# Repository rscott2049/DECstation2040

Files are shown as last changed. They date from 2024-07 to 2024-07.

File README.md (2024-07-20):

# DECstation 2040

## 1.0 Introduction

This document outlines the DECstation 2040, a RP2040 based DECstation 3000
emulator that can run DECWindows. A summary of features:

Hardware:

- RP2040, running at 1.8v/300 MHz
- 32 MB of PSRAM
- 8 MB SPI flash
- uSD card socket
- Monochrome VGA at 1024 x 864
- Ethernet RMII PHY support (socket on rev 1.5, integrated in rev 2.1)

Software:

- 4 port PSRAM PIO engine
- PIO driven VGA, with seperate 16x16 cursor plane overlay
- USB HID to DECWindows keyboard and mouse
  
## 1.1 Software 

### PIO:
The PSRAM/HyperRAM PIO engine provides 42/32 MB/s (write/read) of memory
bandwidth. Further, four PIO engines are used to provide four seperate
read/write memory ports. This allows independent memory access for
the emulated CPU, video DMA, and receive/send Ethernet traffic. Note that
all 32 instruction slots are used.

The video PIO engine can support up to a sysclk/2 pixel rate. Thus,
for the 300 MHz sysclk typically used, it is possible to run 1080p60 at
a pixel rate of 148.5 MHz. The default video rate is 1024 x 768 @ 70Hz,
as this matches the screen used for development and the pixel rate
is an integral divisor from sysclk. Only five PIO instruction slots are
used.

### DMA:
To drive the video PIO engine, five DMA channels are used. They are allocated
as follows:

- ctrl_dma_chan - points to DMA channel command packets
- data_dma_chan - executes DMA command packets
- ps_read_chan - points to PSRAM read data buffer
- inc_dma_chan - used to generate loop counter indices
- cur_inc_dma_chan - used as cursor loop counter

This project uses the RP2040 DMA sniffer to dynamically generate PSRAM
addresses, which eliminates the need to have a per-line PSRAM command packet. 
Further, it uses the inc_dma_chan to enable DMA command loops, eliminating
per-line DMA commands needed to send commands to the PIO pixel and PSRAM
PIO engines. This makes the amount of memory needed to drive video
independent of the display format. Currently, 86 DMA command packets are
used vs. approximately 2250 required for 1080p if a per-line DMA structure
was used.

In order to eliminate the latency from when the PSRAM PIO engine FIFO
has read data, and its delivery to SRAM, we use the ps_read_chan. This
channel is chained to after a PSRAM DMA command is executed. Without
this channel, the PSRAM PIO engine FIFO would be not be emptied until
the next DMA command is executed. This impacts the non-video PSRAM
channels, as they must wait unitl the video PSRAM command is complete.

### USB:
The USB HID code supports (at least) two keyboard/mouse combo types:
Rii mini X1 (model: RT-MWK01), purchased at MicroCenter, and Logitech
K830. 

### Emulator:
Dmitry's code at http://dmitry.gr/?r=05.Projects&proj=33.%20LinuxCard was
modified to support the RP2040, as well as adding support for video and USB
mouse/keyboard input. With overclocking and running the assembly language
version of the CPU emulator, Dmitry's Linux image reports a BOGOMIPS rating
of 13.44.

# 2.0) Getting started

## 2.1) Hardware
Build either rev 1.5 or 2.1, using the appropriate emu_brd directory. Please
note that rev 2.1 is still undergoing Ethernet debug, and has exhibited
significant packet drops. I use JLCPCB for board fabrication, and there are 
Digikey BOM spreadsheets in doc/bom. Recommend building two boards: one to
use as a 1.8v CMSIS debugger, and the other as the target. Feel free to only
populate the RP2040 related components on the CMSIS debugger.

The surface mount parts aren't too troublesome - I find the PSRAM BGA to be
much easier to solder than the RP2040 QFN. My technique is to use a hot-air
SMT rework tool. Recommended assembly steps:
1) Solder the voltage regulator, check for 1.8v and 3.3v when done.
2) Solder all of the passives, the RP2040, flash, and the USB connectors
if building rev 2.1. (Note that two bodge wires are needed to connect J5
and J11 D+/D- as my assumption that USB-A could serve as non-host connector
was incorrect).
When done, use blink_bringup (below) to check connections. (Edit blink.c
to enable the pins to check).
3) Solder the HyperRAM chip, run mem_test to check connections.
4) Solder the voltage translator chips, edit blink.c and run to check
connections.
5) Solder the connectors.

For rev 1.5:
Needs modified waveshare LAN8722 board. In addition to the modifications
outlined at: https://github.com/maximeborges/pico-rmii-ethernet, pin 13 of
the 7 x 2 connector (originally NC) is used as VDDIO for the LAN8722 chip.
To make this modification, cut the existing connection between LAN8722 pin
9 to 3.3v, and route pin 9 to pin 13 of the connector. This allows the use
of 1.8v I/O from the DECstation 2040 board. Also needed is a 6 pin header
to VGA connector. See rev 2.1 schematic for VGA pins needed.

## 2.2) Software
Start with:
http://dmitry.gr/?r=05.Projects&proj=33.%20LinuxCard
Download the images, particularly the ultrix.gui image. This should be placed
on a FAT32 for uMIPS. Edit uc_main.c to select which image to run.

Next, go to where this README.md is stored. Then set current directory to sw.
Edit the "source_this" file to reflect the location of the Pico SDK, and source
this file to set the PICO_SDK environment variable for the current session.

A good place to start is with the blink_bringup directory. CD to this,
and do:

`cmake -B build -S .`

Build software via

`./build.sh`

This will generate an .elf file in build/src. Use picotool to load this onto
the target board. After rebooting, should get "hello, world" on USB serial, as
well as on the hardware serial port. A 500 Hz square wave should be present
on GPIO21 (ret_clk). This can be changed via editing the src/blink.c file.
I use this tool incrementally while soldering the board, to verify connectivity.

Next, build the CMSIS debugger. CD to the picoprobe directory and
build with:

`cmake -B build -DCUSTOMPROBE=1
make -C build`

Program with

`sudo picotool load build/customprobe.elf`

Now go to the psram directory and do:

`cmake -B build -S .`

Build software via

`./build.sh`

This will generate most of the available packages. Of interest are:

- mem_test - a simple memory tester
- fb_test - test program for the frame buffer library
- fb_mem_test - memory test with frame buffer enabled
- pico-rv32ima - RISC-V linux emulation
- uMIPS - DECstation emulation
- pico_rmii_ethernet_httpd - test program for RMII. 

There are shell scripts to load the above:

- cl_sram.sh   - sd command line
- eth_sram.sh  - ethernet test
- fb_flash.sh  - framebuffer library test, run from flash
- fb_sram.sh   - framebuffer library test, run from SRAM
- fbm_flash.sh - memory test with framebuffer enabled, run from flash
- fbm_sram.sh  - memory test with framebuffer enabled, run from SRAM
- mt_sram.sh   - memory test, run from SRAM
- mt_flash.sh  - memory test, run from flash
- um_flash.sh - uMIPS emulator, run from flash
- um_sram.sh  - uMIPS emulator, run from SRAM

Running the code:
Connect the debugger board to the SWD port on the target.
Start the CMSIS debugger via sw/start_cmsis.sh.
Execute one of the scripts above. This will load the program into RP2040
SRAM and start it.

If you wish to run from flash, comment out the no_flash line in the source CMakeLists.txt. Note that the uMIPS emulator requires "copy_to_ram" to be enabled
when running from flash.

# 3.0) Commentary

This project has been a voyage of discovery. The first doc/build_log.txt entry
was on 23-mar-2023, but I'd been thinking of building a business card
ever since I'd read Dmitry's LinuxCard web page. I've learned how to
use the RP2040 PIO engines and the DMA subsystem to push pixels. I'm
amazed at how flexible and capable the RP2040 has turned out to be. Hats off
to the RP2040 designers! 

Most enjoyable moments:

- When the PSRAM PIO engine finally ran the memory test overnight.
- When the second solution to the problem of how to get the DMA subsytem
to do a counted loop actually worked without killing SD card access.
- When the DMA cursor read data during blanking worked, giving smooth
cursor movement.

Less than enjoyable moments:

- Realizing the "optimization" of reordering data on the PSRAM to improve
layout was wrong, after submitting the design to JLCPCB.
-  Realizing that the first flash part chosen didn't support "Continuous Read
Mode". On the other hand, this did force me to learn how to do SRAM builds,
speeding up development.
- Having the wrong footprint for the level translator on rev 1.3.
- Finding out that Digikey no longer stocked the Ethernet connector on
rev 2.0, after submitting PCB. Related - the PSRAM was out of stock, so
clicked on the recommended alternative. Was disappointed when the box
showed up, and it was the waferscale part. Tiny, but unsolderable.

# 4.0) Next steps
- Use the ps_get_buf DMA subroutine to setup the cursor PSRAM command. This
will reduce the memory footprint.
- Write the lance Ethernet emulation code for uMIPS.
- Port MicroMac https://axio.ms/projects/2024/06/16/MicroMac.html

# 5.0) Acknowledgements

This project would not exist without Dmitry's excellent LinuxCard project,
at: http://dmitry.gr/?r=05.Projects&proj=33.%20LinuxCard

Inspiration and software framework:
https://github.com/Wren6991/PicoDVI.git

DEC mouse and keyboard support used code from:
https://hackaday.io/project/19576-dec-mouse-adapter and 
https://github.com/pkoning2/lk201emu.git

Ethernet:
https://github.com/maximeborges/pico-rmii-ethernet

Also, Hackaday.com for articles on SMT soldering, USB-C, etc., giving me
confidence that I could actually do this project!

## Pictures/video
A selection of pictures from doc/photos follows. See doc/photos for pictures
of previous versions and how the emulated video output progressed from first
pixel to current.
### Video showing [Xmaze/worms](https://youtu.be/O6Lyjsey6ek) running
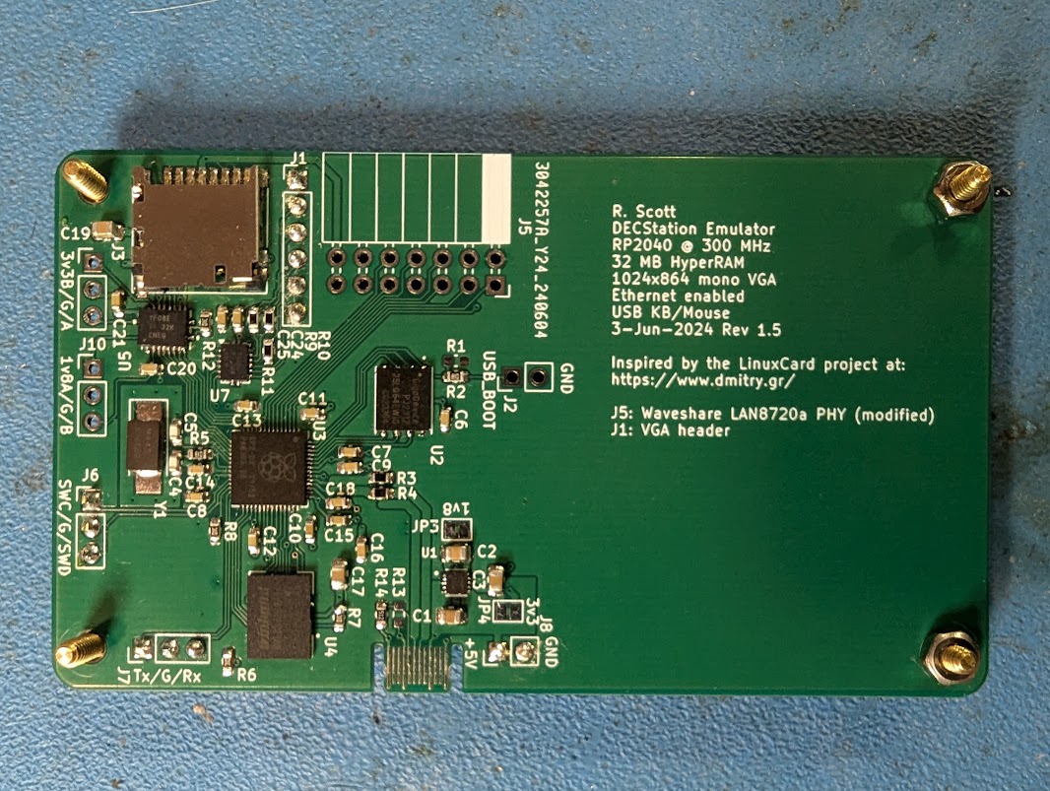
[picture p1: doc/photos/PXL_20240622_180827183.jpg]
### 
Rev 1.5
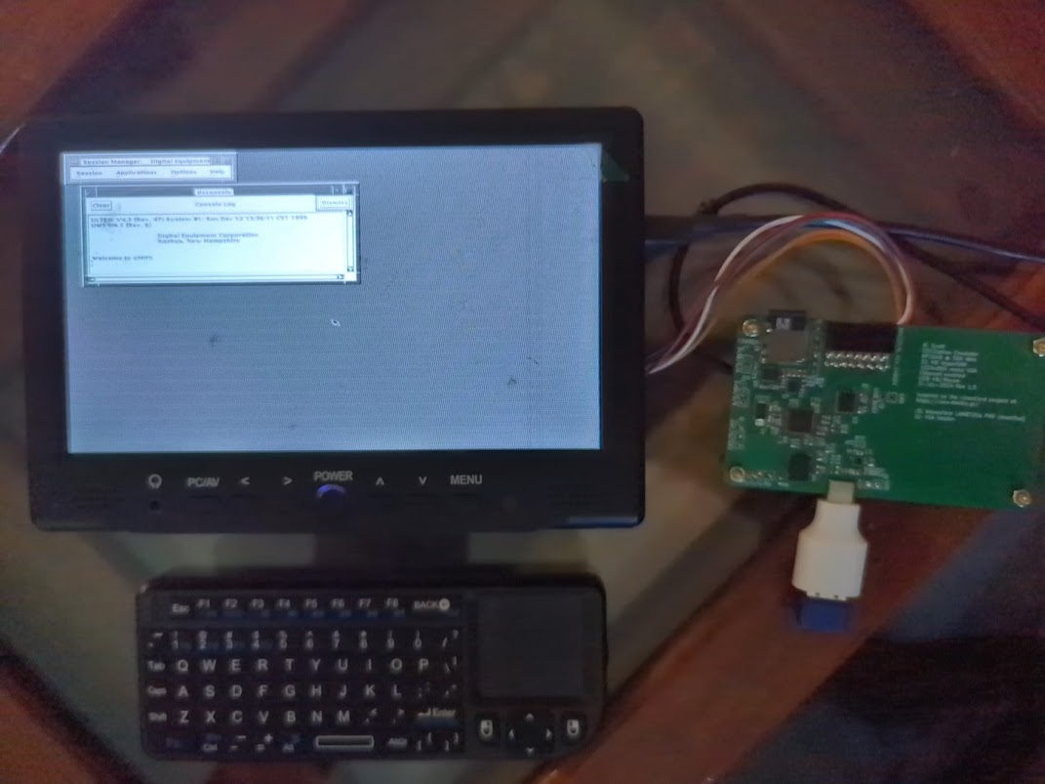
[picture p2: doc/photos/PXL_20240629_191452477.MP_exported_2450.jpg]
### 
Rev 1.5 running
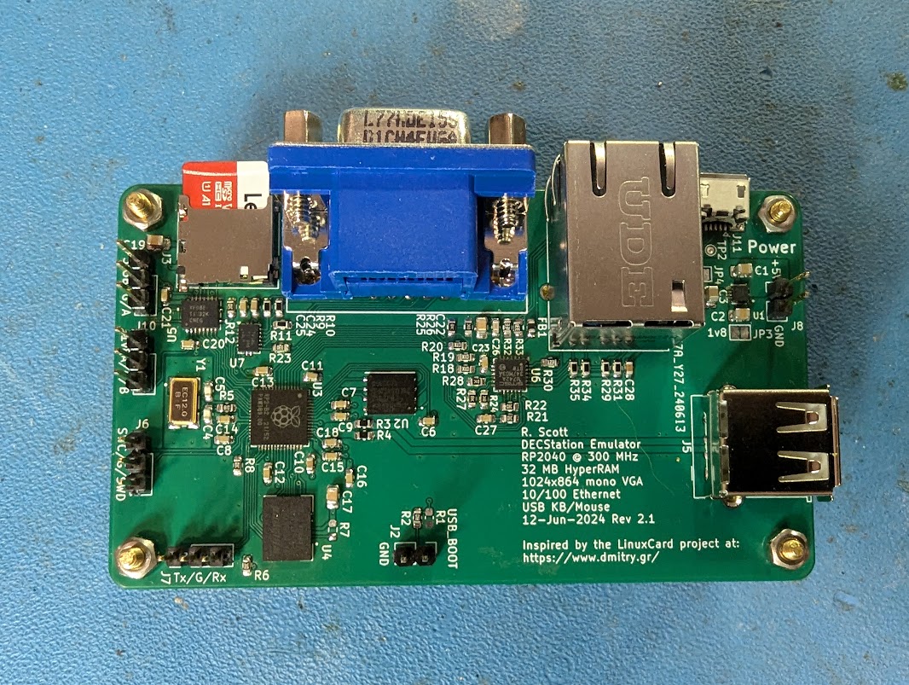
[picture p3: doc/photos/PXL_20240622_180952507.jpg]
### 
Rev 2.1
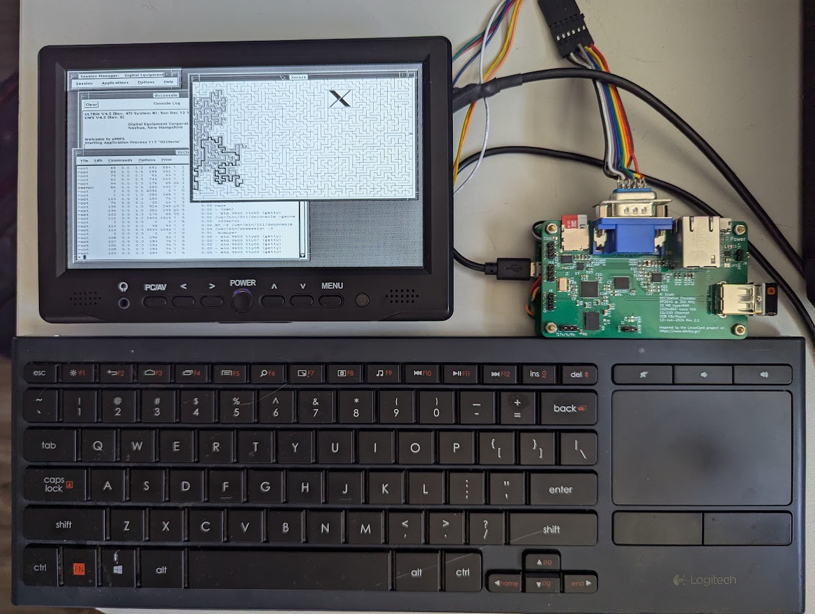
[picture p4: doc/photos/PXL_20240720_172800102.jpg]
### 
Rev 2.1 running with Logitech keyboard
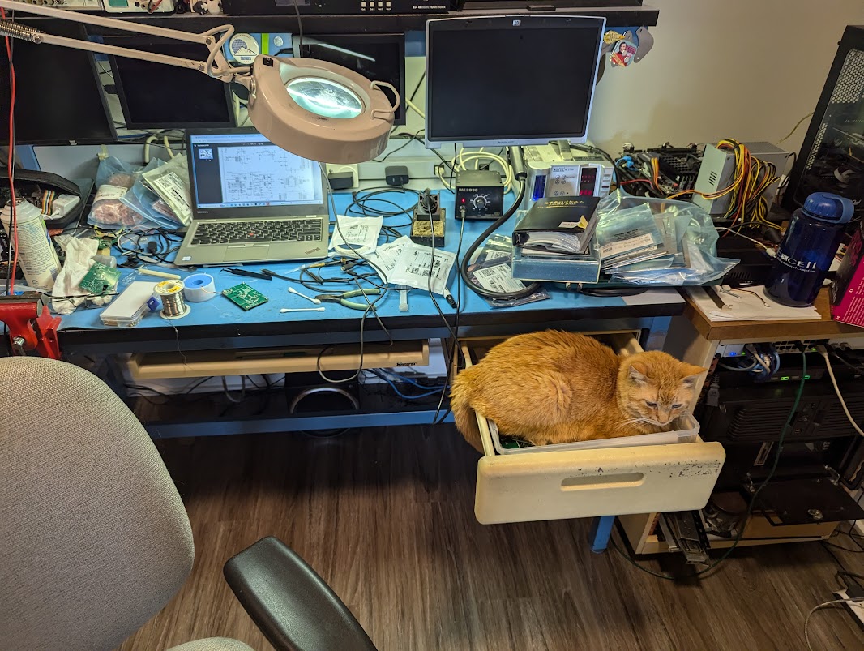
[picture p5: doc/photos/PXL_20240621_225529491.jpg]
Helper cat in the parts box
### 
Helper cat in the parts box

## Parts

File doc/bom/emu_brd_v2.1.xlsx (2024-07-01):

Index | Manufacturer Part Number | Manufacturer Name | Assemblies | Attrition % | Requested Quantity 1 | Pack Quantity 1 | Pack Type 1 | Digi-Key Part Number 1 | Unit Price 1 | Extended Price 1 | Minimum Order Quantity 1 | Product Notes
1 | SC0914(13) | Raspberry Pi | 480 |  | 1 | 480 | Cut Tape (CT) | 2648-SC0914(13)CT-ND | 0.70000 | $336.00 | 1
2 | W958D8NBYA4I | Winbond Electronics | 480 |  | 1 | 480 | Tray | 256-W958D8NBYA4I-ND | 2.99527 | $1,437.73 | 480
3 | GD25LQ64EWIGR | GigaDevice Semiconductor (HK) Limited | 480 |  | 1 | 480 | Cut Tape (CT) | 1970-GD25LQ64EWIGRCT-ND | 1.14648 | $550.31 | 1
4 | TXV0106BQBR | Texas Instruments | 480 |  | 1 | 480 | Cut Tape (CT) | 296-TXV0106BQBRCT-ND | 0.76004 | $364.82 | 1
5 | TXS0108ERGYR | Texas Instruments | 480 |  | 1 | 480 | Cut Tape (CT) | 296-24806-1-ND | 0.86860 | $416.93 | 1
6 | LAN8742A-CZ-TR | Microchip Technology | 480 |  | 1 | 480 | Cut Tape (CT) | LAN8742A-CZ-CT-ND | 1.17000 | $561.60 | 1
7 | TLV751180330PDSQR | Texas Instruments | 480 |  | 1 | 480 | Cut Tape (CT) | 296-TLV751180330PDSQRCT-ND | 0.35976 | $172.68 | 1
8 | L77HDE15SD1CH4FVGA | Amphenol ICC (Commercial Products) | 480 |  | 1 | 480 | Tray | L77HDE15SD1CH4FVGA-ND | 1.22643 | $588.69 | 1
9 | USB-A1HSW6 | On Shore Technology Inc. | 480 |  | 1 | 480 | Tray | ED2989-ND | 0.35552 | $170.65 | 1
10 | RB1-125BAG1A | WIZnet | 480 |  | 1 | 480 | Tray | 1278-1011-ND | 2.39295 | $1,148.62 | 1
11 | DM3D-SF | Hirose Electric Co Ltd | 480 |  | 1 | 480 | Cut Tape (CT) | HR1941CT-ND | 1.28572 | $617.15 | 1
12 | BLM18PG121SN1D | Murata Electronics | 480 |  | 1 | 480 | Cut Tape (CT) | 490-1037-1-ND | 0.03412 | $16.38 | 1
13 | C0603C270J5GAC7411 | KEMET | 480 |  | 2 | 960 | Cut Tape (CT) | 399-C0603C270J5GAC7411CT-ND | 0.01238 | $11.88 | 1
14 | GRM033R61H471KA12D | Murata Electronics | 480 |  | 1 | 480 | Cut Tape (CT) | 490-GRM033R61H471KA12DCT-ND | 0.00430 | $2.06 | 1
15 | CGA3E2X7R1H223K080AA | TDK Corporation | 480 |  | 2 | 960 | Cut Tape (CT) | 445-5663-1-ND | 0.01802 | $17.30 | 1
16 | CL10B104KO8NNNC | Samsung Electro-Mechanics | 480 |  | 16 | 4000 | Tape & Reel (TR) | 1276-1005-2-ND | 0.00574 | $22.96 | 4000
16 | CL10B104KO8NNNC | Samsung Electro-Mechanics | 480 |  |  | 3680 | Cut Tape (CT) | 1276-1005-1-ND | 0.00686 | $25.24 | 1
17 | CL10A105KO8NNNC | Samsung Electro-Mechanics | 480 |  | 2 | 960 | Cut Tape (CT) | 1276-1034-1-ND | 0.01050 | $10.08 | 1
18 | CL21A106KOQNNNG | Samsung Electro-Mechanics | 480 |  | 6 | 2880 | Cut Tape (CT) | 1276-6455-1-ND | 0.01847 | $53.19 | 1
19 | CRCW060327R0JNEA | Vishay Dale | 480 |  | 2 | 960 | Cut Tape (CT) | 541-27GCT-ND | 0.00866 | $8.31 | 1
20 | RC0603JR-0733RL | YAGEO | 480 |  | 1 | 480 | Cut Tape (CT) | 311-33GRCT-ND | 0.00760 | $3.65 | 1
21 | ERJ-3EKF49R9V | Panasonic Electronic Components | 480 |  | 4 | 1920 | Cut Tape (CT) | P49.9HCT-ND | 0.00980 | $18.82 | 1
22 | ERJ-3EKF2800V | Panasonic Electronic Components | 480 |  | 3 | 1440 | Cut Tape (CT) | P280HCT-ND | 0.00980 | $14.11 | 1
23 | RC0603JR-07330RL | YAGEO | 480 |  | 2 | 960 | Cut Tape (CT) | 311-330GRCT-ND | 0.00364 | $3.49 | 1
24 | CRGCQ0603F1K0 | TE Connectivity Passive Product | 480 |  | 2 | 960 | Cut Tape (CT) | A129688CT-ND | 0.00840 | $8.06 | 1
25 | CRG0603F10K | TE Connectivity Passive Product | 480 |  | 3 | 1440 | Cut Tape (CT) | A106048CT-ND | 0.00709 | $10.21 | 1
26 | RC0603FR-0712K1L | YAGEO | 480 |  | 1 | 480 | Cut Tape (CT) | 311-12.1KHRCT-ND | 0.00930 | $4.46 | 1
27 | ECS-120-20-23B-TR | ECS Inc. | 480 |  | 1 | 480 | Cut Tape (CT) | XC1013CT-ND | 0.52610 | $252.53 | 1

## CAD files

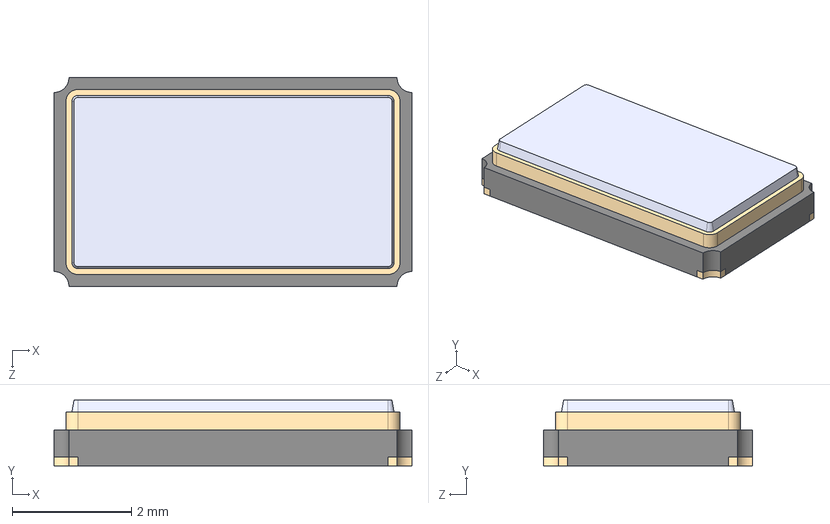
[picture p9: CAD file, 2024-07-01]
emu_brd_rev_2.1/emu_brd.step/ECS-120-20-23B-TR.step
6.00 x 1.10 x 3.50 mm

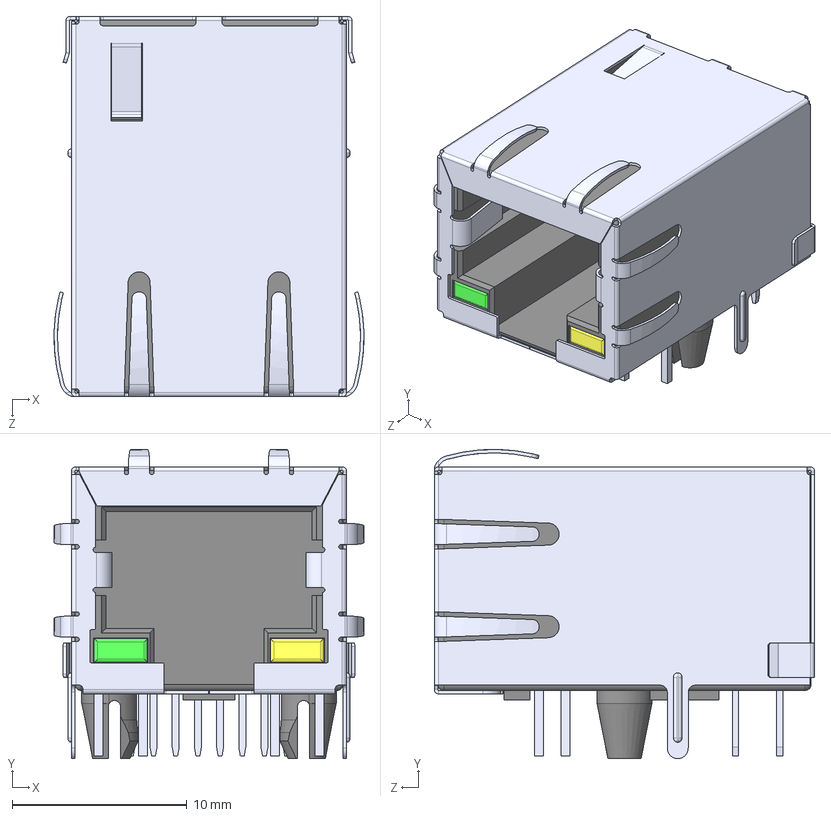
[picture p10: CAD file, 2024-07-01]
emu_brd_rev_2.1/emu_brd.step/RB1-125BAG1A.step
17.7 x 17.7 x 21.8 mm

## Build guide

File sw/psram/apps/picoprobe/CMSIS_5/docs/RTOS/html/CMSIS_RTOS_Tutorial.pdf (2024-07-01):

CMSIS-RTOS Tutorial

# Introduction

This tutorial is an excerpt from “The Designers Guide to the Cortex-M Processor Family” by Trevor Martin and is reproduced with permission of Elsevier. For more details please see the Further Reading section at the end of this tutorial.

In this tutorial we are going to look at using a small footprint RTOS running on a Cortex-M based microcontroller. Specifically we are going to use an RTOS that meets the ‘Cortex Microcontroller Interface Standard’ (CMSIS) RTOS Specification. This specification defines a standard RTOS API for use with Cortex-M based microcontrollers. The CMSIS-RTOS API provides us with all the features we will need to develop with an RTOS, we only need to learn it once and then can use it across a very wide range of devices. CMSIS-RTOS also provides a standard interface for more complex frameworks (Java Virtual Machine, UML). It is also a standard interface for anyone wanting to develop reusable software components. If you are new to using an RTOS it takes a bit of practice to get used to working with an RTOS but once you have made the leap the advantages are such that you will not want to return to writing bare metal code.

# Getting Started- Installing the tools

To run the examples in this tutorial, it is first necessary to install the MDK-ARM toolchain. First download the MDK-Core Version 5 using the embedded URL below and run the installation file.

http://www.keil.com/mdk5/install

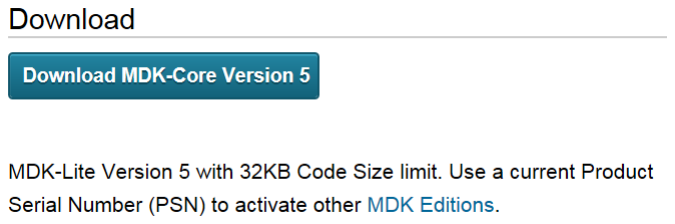
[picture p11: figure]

This installs the core toolchain which includes the IDE, compiler/linker and the basic debugger. It does not include support for specific Cortex-M based microcontrollers. To support a given microcontroller family we need to install a ‘Device Family Pack’. This is a collection of support files such as startup code, flash programming algorithms and debugger support that allow you to develop with a specific microcontroller family.

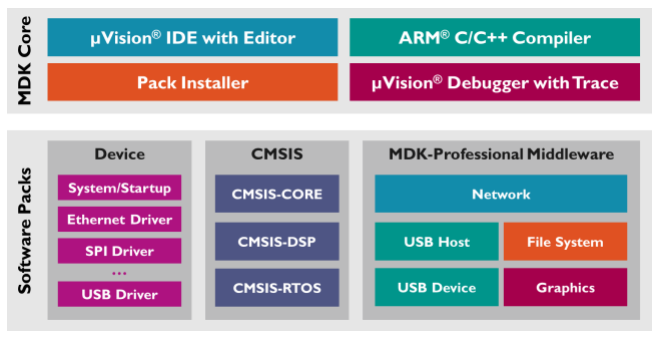
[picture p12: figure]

The | MDK-ARM | toolchain
consists of a Core Installation (IDE, Compiler and Debugger) plus additional software packs added through a pack installer

### 2 CMSIS-RTOS Tutorial

In the exercises we are going to use an STM32F103RB so we need to install support for this device using the ‘Pack Installer’ within the µVision IDE. When the MDK-Core finishes installing the pack installer will start automatically, alternatively you can start the µVision IDE and access Pack Installer from the toolbar by pressing the icon shown below

Once the pack installer is open it will connect to cloud based pack database and display the available device packs.

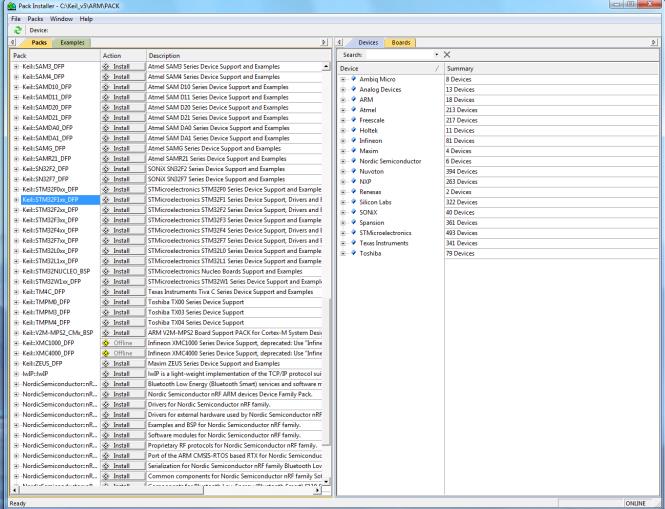
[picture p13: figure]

Select the Keil::STM32F1xx_DFP and press the install button. This will take a few minutes to download and install the STM32F1xx support files.

If the pack installer has any problems accessing the remote pack you can download it manually using the URL below

http://www.keil.com/dd2/Pack/

Pack Installer Icon

The Pack Installer.
Use this utility to
install device support
and | third | party
software components

Install support for the
STM32F1xx Family

CMSIS-RTOS Tutorial

Again select the STM32F1xx pack and save it to your hard disk. The file may be saved as a .zip file depending on the browser you are using. If it is saved as a .zip change the .zip extension to .pack, you can then install it locally by double clicking on the STM32F1xx.pack file.

# Installing the examples

The examples for this tutorial are provided as a CMSIS pack. You can install the pack into the MDK-ARM by simply double clicking on the Hitex.CMSIS_RTOS_Tutorial.1.0.3. pack file.

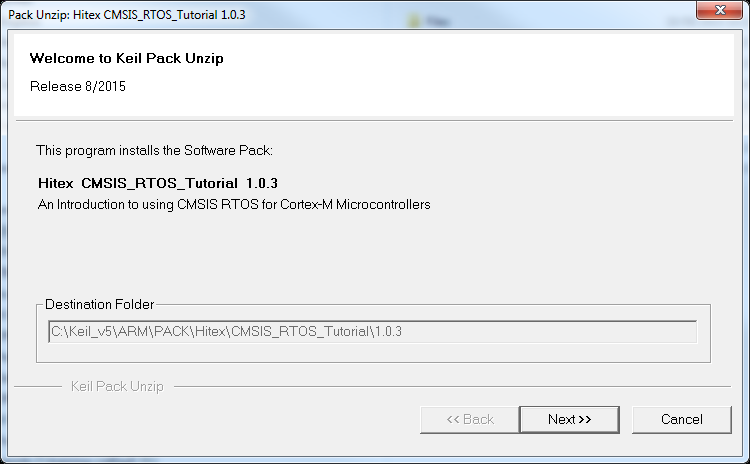
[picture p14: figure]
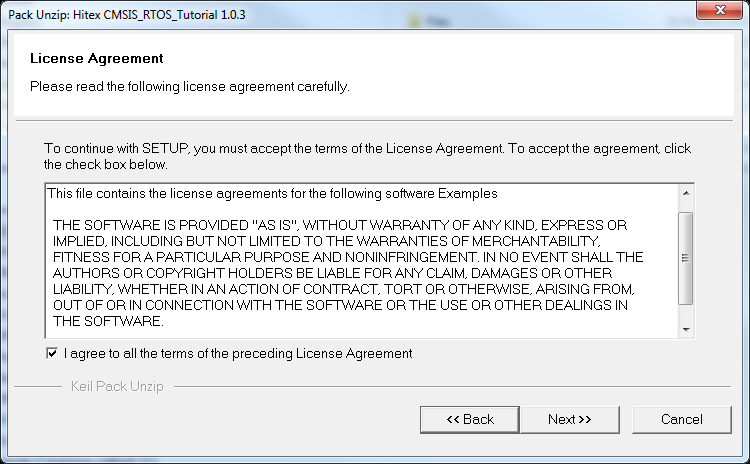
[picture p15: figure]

Once the examples have been installed into MDK-ARM they are part of the toolchain and can be accessed through the pack installer. The tutorial examples can be found in the boards section under ‘CMSIS_RTOS_Tutorial’.

Once | the | pack | has | started
installing click next

Here you must accept the license and again click next to continue the installation

### 4 CMSIS-RTOS Tutorial

# What Hardware do I need?

Simple answer: none! The Keil toolchain contains simulators for each of the Cortex-M processors. It also contains full simulation models (CPU + Peripherals) for some of the earlier Cortex-M microcontrollers. This means we can run the examples in the debugger using the simulation models and explore every aspect of using the RTOS. In fact this method of working is a better way of learning how to use the RTOS than going straight to a real microcontroller.

# Overview

In this tutorial we will first look at setting up an introductory RTOS project for a Cortex-M based microcontroller. Next, we will go through each of the RTOS primitives and how they influence the design of our application code. Finally, when we have a clear understanding of the RTOS features, we will take a closer look at the RTOS configuration options. If you are used to programming a microcontroller without using an RTOS i.e. bare metal, there are two key things to understand as you work through this tutorial. In the first section we will focus on creating and managing Threads. The key concept here is to consider them running as parallel concurrent objects. In the second section we will look at how to communicate between threads. In this section the key concept is synchronization of the concurrent threads.

CMSIS-RTOS Tutorial

## First steps with CMSIS-RTOS

The RTOS itself consists of a scheduler which supports round-robin, pre-emptive and co-operative multitasking of program threads, as well as time and memory management services. Inter-thread communication is supported by additional RTOS objects, including signal triggering, semaphores, mutex and a mailbox system. As we will see, interrupt handling can also be accomplished by prioritized threads which are scheduled by the RTOS kernel.

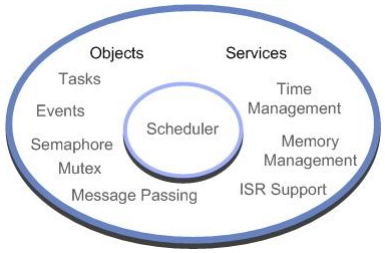
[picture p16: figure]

# Accessing the CMSIS-RTOS API

To access any of the CMSIS-RTOS features in our application code it is necessary to include the following header file

#include <cmsis_os.h>

This header file is maintained by ARM as part of the CMSIS-RTOS standard. For the CMSIS-RTOS Keil RTX this is the default API. Other RTOS will have their own proprietary API but may provide a wrapper layer to implement the CMSIS-RTOS API so they can be used where compatibility with the CMSIS standard is required.

# Threads

The building blocks of a typical ‘C’ program are functions which we call to perform a specific procedure and which then return to the calling function. In CMSIS-RTOS the basic unit of execution is a “Thread”. A Thread is very similar to a ‘C’ procedure but has some very fundamental differences.

The RTOS kernel contains a scheduler that runs program code as tasks. Communication between tasks is accomplished by RTOS objects such as events,
semaphores, | mutexes | and
mailboxes. | Additional | RTOS
services | include | time | and
memory | management | and
interrupt support.

### 6 CMSIS-RTOS Tutorial

unsigned int procedure (void) | void thread (void)
{ | {
| while(1)
…… | {
| ……
return(ch); | }
} | }

While we always return from our ‘C’ function, once started an RTOS thread must contain a loop so that it never terminates and thus runs forever. You can think of a thread as a mini self-contained program that runs within the RTOS.

An RTOS program is made up of a number of threads, which are controlled by the RTOS scheduler. This scheduler uses the SysTick timer to generate a periodic interrupt as a time base. The scheduler will allot a certain amount of execution time to each thread. So thread1 will run for 5ms then be de-scheduled to allow thread2 to run for a similar period; thread 2 will give way to thread3 and finally control passes back to thread1. By allocating these slices of runtime to each thread in a round-robin fashion, we get the appearance of all three threads running in parallel to each other.

Conceptually we can think of each thread as performing a specific functional unit of our program with all threads running simultaneously. This leads us to a more object-orientated design, where each functional block can be coded and tested in isolation and then integrated into a fully running program. This not only imposes a structure on the design of our final application but also aids debugging, as a particular bug can be easily isolated to a specific thread. It also aids code reuse in later projects. When a thread is created, it is also allocated its own thread ID. This is a variable which acts as a handle for each thread and is used when we want to manage the activity of the thread.

osThreadId id1,id2,id3;

In order to make the thread-switching process happen, we have the code overhead of the RTOS and we have to dedicate a CPU hardware timer to provide the RTOS time reference. In addition, each time we switch running threads, we have to save the state of all the thread variables to a thread stack. Also, all the runtime information about a thread is stored in a thread control block, which is managed by the RTOS kernel. Thus the “context switch time”, that is, the time to save the current thread state and load up and start the next thread, is a crucial figure and will depend on both the RTOS kernel and the design of the underlying hardware.

Each thread has its own stack for saving its data during a context switch. The thread control block is used by the kernel to manage the active thread.

Thread

Thread Control
Block

Thread
Stack
Priority & State | Context

CMSIS-RTOS Tutorial

The Thread Control Block contains information about the status of a thread. Part of this information is its run state. In a given system only one thread can be running and all the others will be suspended but ready to run. The RTOS has various methods of inter-thread communication (signals, semaphores, messages). Here, a thread may be suspended to wait to be signaled by another thread or interrupt before it resumes its ready state, whereupon it can be placed into running state by the RTOS scheduler.

Running | The Currently Running Thread
Ready | Threads ready to Run
Wait | Blocked Threads waiting for an OS Event

# Starting the RTOS

To build a simple RTOS program we declare each thread as a standard ‘C’ function and also declare a thread ID variable for each function.

void thread1 (void);
void thread2 (void);

osThreadId thrdID1, thrdID2;

By default the CMSIS-RTOS scheduler will be running when main() is entered and the main() function becomes the first active thread. Once in main(), we can stop the scheduler task switching by calling osKernelInitialize (). While the RTOS is halted we can create further threads and other RTOS objects. Once the system is in a defined state we can restart the RTOS scheduler with osKernelStart().

You can run any initializing code you want before starting the RTOS.

void main (void)
{
osKernelInitialize ();
IODIR1 = 0x00FF0000; | // Do any C code you want
Init_Thread(); | //Create a Thread
osKernelStart(); | //Start the RTOS
}

At any given moment a
single thread may be
running. The remaining
threads will be ready to
run | and | will | be
scheduled | by | the
kernel. Threads may
also | be | waiting
pending an OS event.
When this occurs they
will return to the ready
state and be scheduled
by the kernel.

### 8 CMSIS-RTOS Tutorial

When threads are created they are also assigned a priority. If there are a number
of threads ready to run and they all have the same priority, they will be allotted run time in a round-robin fashion. However, if a thread with a higher priority becomes ready to run, the RTOS scheduler will de-schedule the currently running thread and start the high priority thread running. This is called pre-emptive priority-based scheduling. When assigning priorities you have to be careful because the high priority thread will continue to run until it enters a waiting state or until a thread of equal or higher priority is ready to run.

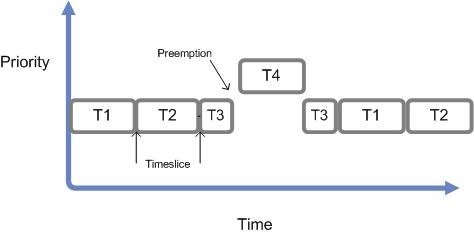
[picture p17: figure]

## Exercise a first CMSIS-RTOS project

This project will take you through the steps necessary to create and debug a CMSIS-RTOS based project.

Start µVision and select Project → New µVision Project

In the new project dialog enter a suitable project name and directory and click Save

Next the device database will open. Navigate through to the

STMicroelectronics::STM32F103:STM32F103RB

Threads of equal priority will be scheduled in a round-robin fashion. High priority tasks will pre-empt low priority tasks and enter the running state ‘on demand’.

CMSIS-RTOS Tutorial

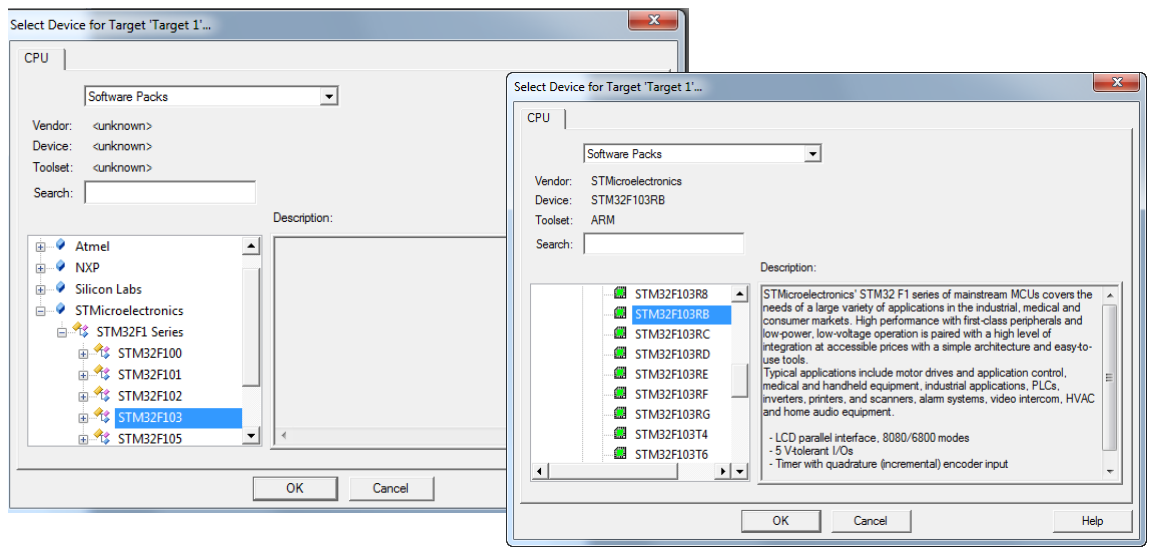
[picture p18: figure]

Once you have selected this device click ok.

Once the microcontroller variant has been selected the Run Time Environment Manager will open.

This allows you to configure the platform of software components you are going to use in a given project. As well as displaying the available components the RTE understands their dependencies on other components.

To configure the project for use with the CMSIS-RTOS Keil RTX, simply tick the CMSIS::RTOS (API):Keil RTX box.

### 10 CMSIS-RTOS Tutorial

This will cause the selection box to turn orange meaning that additional components are required. The required component will be displayed in the Validation Output window.

To add the missing components you can press the Resolve button in the bottom left hand corner of the RTE. This will add the device startup code and the CMSIS Core support. When all the necessary components are present the selection column will turn green.

It is also possible to access a components help files by clicking on the blue hyperlink in the Description column.

Now press the OK button and all the selected components will be added to the new project

CMSIS-RTOS Tutorial

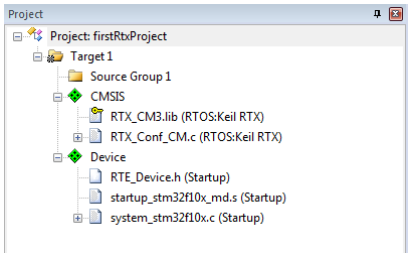
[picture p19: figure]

The CMSIS components are added to folders displayed as a green diamond. There are two types of file here. The first type is a library file which is held within the toolchain and is not editable. This file is shown with a yellow key to show that it is ‘locked’ (read-only). The second type of file is a configuration file. These files are copied to your project directory and can be edited as necessary. Each of these files can be displayed as a text files but it is also possible to view the configuration options as a set of pick lists and drop down menus.

To see this open the RTX_Conf_CM.c file and at the bottom of the editor window select the ‘Configuration Wizard’ tab.

### 12 CMSIS-RTOS Tutorial

Click on Expand All to see all of the configuration options as a graphical pick list:

For now it is not necessary to make any changes here and these options will be examined towards the end of this tutorial.

Our project contains four configuration files three of which are standard CMSIS files

Startup_STM32F10x_md.s | Assembler vector table
System_STM32F10x.c | C code to initialize key system peripherals, such as clock tree, PLL external memory interface.
RTE_Device.h | Configures the pin multiplex
RTX_Conf_CM.c | Configures Keil RTX

Now that we have the basic platform for our project in place we can add some user source code which will start the RTOS and create a running thread.

To do this right-click the ‘Source Group 1’ folder and select ‘Add new item to Source Group 1’

CMSIS-RTOS Tutorial

In the Add new Item dialog select the ’User code template’ Icon and in the CMSIS section select the ‘CMSIS-RTOS ‘main’ function’ and click Add

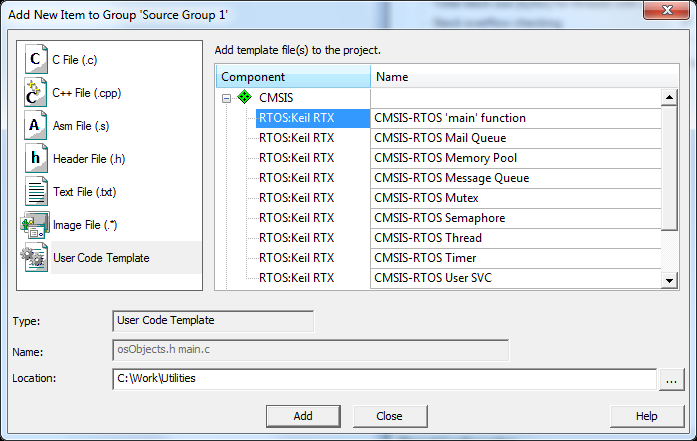
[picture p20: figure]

Repeat this but this time select ‘CMSIS-RTOS Thread’.

This will now add two source files to our project main.c and thread.c

Open thread.c in the editor

We will look at the RTOS definitions in this project in the next section. For now this file contains two functions Init_Thread() which is used to start the thread running and the actual thread function.

### 14 CMSIS-RTOS Tutorial

Copy the Init_Thread function prototype and then open main.c

Main contains the functions to initialize and start the RTOS kernel. Then unlike a bare metal project main is allowed to terminate rather than enter an endless loop. However this is not really recommended and we will look at a more elegant way of terminating a thread later.

In main.c add the Init_Thread prototype as an external declaration and then call it after the osKernelInitialize function as shown below.

#define osObjectsPublic

#include "osObjects.h"

extern int Init_Thread (void); | //Add this line

int main (void) {

osKernelInitialize ();

Init_Thread (); | //Add this line

osKernelStart ();

}

Build the project (F7)

In this tutorial we can use the debugger simulator to run the code without the need for any external hardware.

Highlight the Target 1 root folder, right click and select options for target 1

Select the debugger tab

This menu is in two halves the left side configures the simulator the right half configures the hardware debugger

Select the Simulator radio button and check that ‘Dialog DLL’ is set to DARMSTM.DLL with parameter -pSTM32F103RB

CMSIS-RTOS Tutorial

Click ok to close the options for target menu

Start the debugger (Ctrl+F5)

This will run the code up to main

Open the Debug → OS Support → System and Thread Viewer

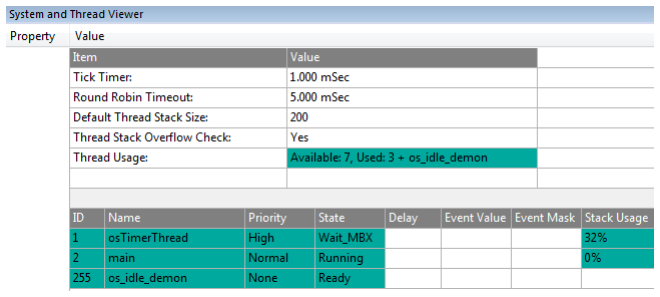
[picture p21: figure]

This debug view shows all the running threads and their current state. At the moment we have three threads which are main, os_idle_demon and osTimerThread.

Start the code running (F5)

### 16 CMSIS-RTOS Tutorial

Now the user thread is created and main is terminated.

Exit the debugger

While this project does not actually do anything it demonstrates the few steps necessary to start using CMSIS-RTOS

# Creating Threads

Once the RTOS is running, there are a number of system calls that are used to manage and control the active threads. By default, the main() function is automatically created as the first thread running. In the first example we used it to create an additional thread then let it terminate by running through the closing brace. However, if we want to we can continue to use main as a thread in its own right. If we want to control main as a thread we must get its thread ID. The first RTOS function we must therefore call is osThreadGetId() which returns the thread ID number of the currently running thread. This is then stored in its ID handle. When we want to refer to this thread in future OS calls, we use this handle rather than the function name of the thread.

osThreadId main_id; //create the thread handle

void main (void)

{

/* Read the Thread-ID of the main thread */

main_id = osThreadGetId ();

while(1)

{

………

}

}

Now that we have an ID handle for main we could create the application threads and then call osTerminate(main_id) to end the main thread. This is the best way to end a thread rather than let it run off the end of the closing brace. Alternatively

CMSIS-RTOS Tutorial

we can add a while(1) loop as shown above and continue to use main in our application.

As we saw in the first example the main thread is used as a launcher thread to create the application threads. This is done in two stages. First a thread structure is defined; this allows us to define the thread operating parameters.

osThreadId thread1_id; | //thread handle
void thread1 (void const *argument); | //function prototype for thread1
osThreadDef(thread1, osPriorityNormal, 1, 0); | //thread definition structure

The thread structure requires us to define the name of the thread function, its thread priority, the number of instances of the thread that will be created, and its stack size. We will look at these parameters in more detail later. Once the thread structure has been defined the thread can be created using the osThreadCreate() API call. Then the thread is created from within the application code, this is often the within the main thread but can be at any point in the code.

thread1_id = osThreadCreate(osThread(thread1), NULL);

This creates the thread and starts it running. It is also possible to pass a parameter to the thread when it starts.

uint32_t startupParameter = 0x23;

thread1_id = osThreadCreate(osThread(thread1), startupParameter);

When each thread is created, it is also assigned its own stack for storing data during the context switch. This should not be confused with the native Cortex processor stack; it is really a block of memory that is allocated to the thread. A default stack size is defined in the RTOS configuration file (we will see this later) and this amount of memory will be allocated to each thread unless we override it to allocate a custom size. The default stack size will be assigned to a thread if the stack size value in the thread definition structure is set to zero. If necessary a thread can be given additional memory resources by defining a bigger stack size in the thread structure.

osThreadDef(thread1, osPriorityNormal, 1, 0); | //assign default stack size to this thread
osThreadDef(thread2, osPriorityNormal, 1, 1024); | //assign 1KB of stack to this thread

### 18 CMSIS-RTOS Tutorial

However, if you allocate a larger stack size to a thread then the additional memory must be allocated in the RTOS configuration file; again we will see this later.

## Exercise creating and managing threads

In this project we will create and manage some additional threads. Each of the threads created will toggle a GPIO pin on GPIO port B to simulate flashing an LED. We can then view this activity in the simulator.

To access the exercise projects open the pack installer from within µVision.

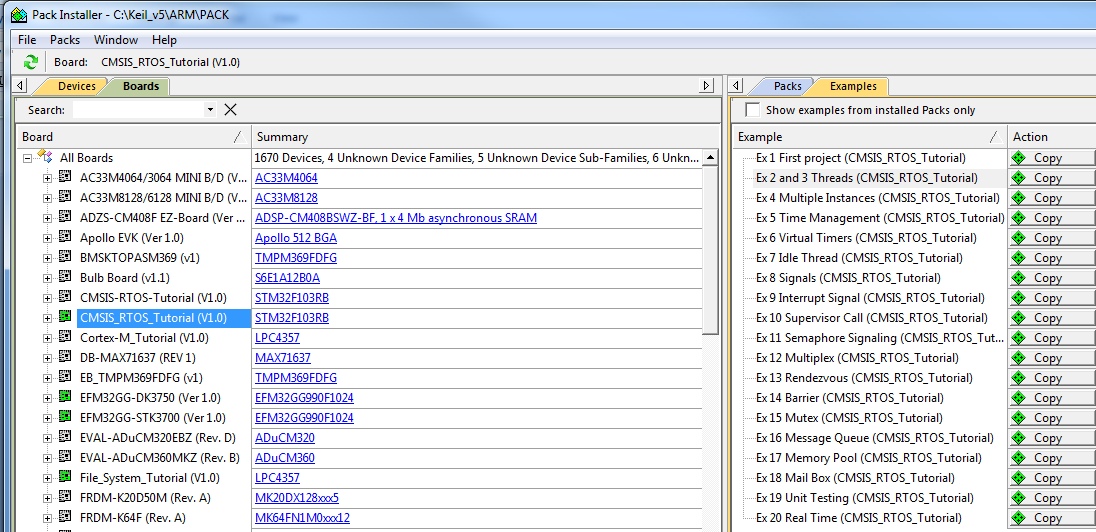
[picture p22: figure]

Select the boards tab and select the CMSIS-RTOS_Tutorial

Now select the examples tab and all the example projects for this tutorial will be shown.

To display then in order click on the grey ‘Example’ column header

A reference copy of the first exercise is included as Exercise 1

Select “Ex 2 and 3 Threads” and press the copy button.

This will install the project to a directory of your choice and open the project in µVision.

CMSIS-RTOS Tutorial

Open the Run Time Environment Manager

In the board support section the MCBSTM32E:LED box is ticked. This adds support functions to control the state of a bank of LED’s on the Microcontroller’s GPIO port B.

When the RTOS starts main() runs as a thread and in addition we will create two additional threads. First we create handles for each of the threads and then define the parameters of each thread. These include the priority the thread will run at, the number of instances of each thread we will create and its stack size (the amount of memory allocated to it) zero indicates it will have the default stack size.

osThreadId main_ID,led_ID1,led_ID2;

osThreadDef(led_thread2, osPriorityNormal, 1, 0);

osThreadDef(led_thread1, osPriorityNormal, 1, 0);

Then in the main() function the two threads are created

led_ID2 = | osThreadCreate(osThread(led_thread2), NULL);
led_ID1 = | osThreadCreate(osThread(led_thread1), NULL);

When the thread is created we can pass it a parameter in place of the NULL define.

Build the project and start the debugger

Start the code running and open the Debug → OS Support → System and Thread Viewer

### 20 CMSIS-RTOS Tutorial

Now we have four active threads with one running and the others ready.

Open the Debug → OS Support → Event Viewer

The event viewer shows the execution of each thread as a trace against time. This allows you to visualize the activity of each thread and get a feel for amount of CPU time consumed by each thread.

Now open the Peripherals → General Purpose IO → GPIOB window

Our two led threads are each toggling a GPIO port pin. Leave the code running and watch the pins toggle for a few seconds.

If you do not see the debug windows updating check the view\periodic window update option is ticked.

CMSIS-RTOS Tutorial

void led_thread2 (void const *argument) {

for (;;) {

LED_On(1);

delay(500);

LED_Off(1);

delay(500);

}}

Each thread calls functions to switch an LED on and off and uses a delay function between each on and off. Several important things are happening here. First the delay function can be safely called by each thread. Each thread keeps local variables in its stack so they cannot be corrupted by any other thread. Secondly none of the threads enter a descheduled waiting state, this means that each one runs for its full allocated time slice before switching to the next thread. As this is a simple thread most of its execution time will be spent in the delay loop effectively wasting cycles. Finally there is no synchronization between the threads. They are running as separate ‘programs’ on the CPU and as we can see from the GPIO debug window the toggled pins appear random.

# Thread Management and Priority

When a thread is created it is assigned a priority level. The RTOS scheduler uses a thread’s priority to decide which thread should be scheduled to run. If a number of threads are ready to run, the thread with the highest priority will be placed in the run state. If a high priority thread becomes ready to run it will preempt a running thread of lower priority. Importantly a high priority thread running on the CPU will not stop running unless it blocks on an RTOS API call or is preempted by a higher priority thread. A thread’s priority is defined in the thread structure and the following priority definitions are available. The default priority is osPriorityNormal

### 22 CMSIS-RTOS Tutorial

CMSIS-RTOS Priority Levels

osPriorityIdle

osPriorityLow

osPriorityBelowNormal

osPriorityNormal

osPriorityAboveNormal

osPriorityHigh

osPriorityRealTime

osPriorityError

Once the threads are running, there are a small number of OS system calls which are used to manage the running threads. It is also then possible to elevate or lower a thread’s priority either from another function or from within its own code.

osStatus osThreadSetPriority(threadID, priority);

osPriority osThreadGetPriority(threadID);

As well as creating threads, it is also possible for a thread to delete itself or another active thread from the RTOS. Again we use the thread ID rather than the function name of the thread.

osStatus = osThreadTerminate (threadID1);

Finally, there is a special case of thread switching where the running thread passes control to the next ready thread of the same priority. This is used to implement a third form of scheduling called co-operative thread switching.

osStatus osThreadYield();//switch to next ready to run thread

## Exercise creating and managing threads II

CMSIS-RTOS Tutorial

In this exercise we will look at assigning different priorities to threads and also how to create and terminate threads dynamically.

Go back to the project “Ex 2 and 3 Threads” Change the priority of LED Thread 2 to Above Normal

osThreadDef(led_thread2, osPriorityAboveNormal, 1, 0);

osThreadDef(led_thread1, osPriorityNormal, 1, 0);

Build the project and start the debugger

Start the code running

Open the Debug → OS Support → Event Viewer window

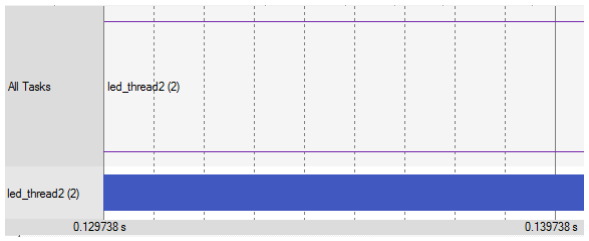
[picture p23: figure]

Here we can see thread2 running but no sign of thread1. Looking at the coverage monitor for the two threads shows us that led_thread1 has not run.

### 24 CMSIS-RTOS Tutorial

Led_thread1 is running at normal priority and led_thread2 is running at a higher priority so has pre-empted led_thread1. To make it even worse led_thread2 never blocks so it will run forever preventing the lower priority thread from ever running.

Although this error may seem obvious in this example this kind of mistake is very common when designers first start to use an RTOS.

# Multiple Instances

One of the interesting possibilities of an RTOS is that you can create multiple running instances of the same base thread code. So for example you could write a thread to control a UART and then create two running instances of the same thread code. Here each instance of the UART code could manage a different UART.

First we create the thread structure and set the number of thread instances to two;

osThreadDef(thread1, osPriorityNormal, 2, 0);

Then we can create two instances of the thread assigned to different thread handles. A parameter is also passed to allow each instance to identify which UART it is responsible for.

ThreadID_1_0 = osThreadCreate(osThread(thread1), UART1);
ThreadID_1_1 = osThreadCreate(osThread(thread1), UART2);

## Exercise Multiple thread instances

In this project we will look at creating one thread and then create multiple runtime instances of the same thread.

In the Pack Installer select “Ex 4 Multiple Instances” and copy it to your tutorial directory.

This project performs the same function as the previous LED flasher program. However we now have one led switcher function that uses an argument passed as a parameter to decide which LED to flash.

void ledSwitcher (void const *argument) {

CMSIS-RTOS Tutorial

for (;;) {
LED_On((uint32_t)argument); delay(500);
LED_Off((uint32_t)argument); delay(500);
}
}

When we define the thread we adjust the instances parameter to two.

osThreadDef(ledSwitcher, osPriorityNormal, 2, 0);

Then in the main thread we create two threads which are different instances of the same base code. We pass a different parameter which corresponds to the led that will be toggled by the instance of the thread.

led_ID1 = | osThreadCreate(osThread(ledSwitcher),(void *) 1UL);
led_ID2 = | osThreadCreate(osThread(ledSwitcher),(void *) 2UL);

Build the code and start the debugger

Start the code running and open the RTX tasks and system window

Here we can see both instances of the ledSwitcher task each with a different ID.

Examine the Call stack + locals window

### 26 CMSIS-RTOS Tutorial

Here we can see both instances of the ledSwitcher threads and the state of their variables. A different argument has been passed to each instance of the thread.

# Time Management

As well as running your application code as threads, the RTOS also provides some timing services which can be accessed through RTOS system calls.

# Time Delay

The most basic of these timing services is a simple timer delay function. This is an easy way of providing timing delays within your application. Although the RTOS kernel size is quoted as 5k bytes, features such as delay loops and simple scheduling loops are often part of a non-RTOS application and would consume code bytes anyway, so the overhead of the RTOS can be less than it immediately appears.

void osDelay (uint32_t millisec )

This call will place the calling thread into the WAIT_DELAY state for the specified number of milliseconds. The scheduler will pass execution to the next thread in the READY state.

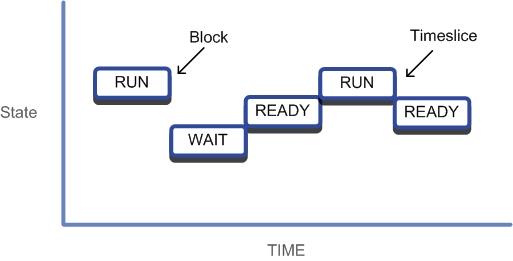
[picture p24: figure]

When the timer expires, the thread will leave the wait_delay state and move to the READY state. The thread will resume running when the scheduler moves it to the RUNNING state. If the thread then continues executing without any further blocking OS calls, it will be descheduled at the end of its time slice and be placed in the ready state, assuming another thread of the same priority is ready to run.

During their lifetime threads move through many states. Here a running thread is blocked by an osDelay call so it enters a wait state. When the delay expires, it moves to ready. The scheduler will place it in the run state. If its timeslice expires, it will move back to ready.

CMSIS-RTOS Tutorial

# Waiting for an Event

In addition to a pure time delay it is possible to make a thread halt and enter the waiting state until the thread is triggered by another RTOS event. RTOS events can be a signal, message or mail event. The osWait() API call also has a timeout period defined in millisec that allows the thread to wake up and continue execution if no event occurs.

osStatus osWait (uint32_t millisec )

When the interval expires, the thread moves from the wait to the READY state and will be placed into the running state by the scheduler. osWait is an optional api call within the CMSIS RTOS specification. If you intend to use this function you must first check it is supported by the RTOS you are using. The osWait API call is not supported by the Keil RTX RTOS.

# Exercise Time Management

In this exercise we will look at using the basic time delay function

In the Pack Installer select “Ex 5 Time Management” and copy it to your tutorial directory.

This is our original led flasher program but the simple delay function has been replaced by the osDelay API call. LED2 is toggled every 100mS and LED1 is toggled every 500mS

void ledOn (void const *argument) {

for (;;) {

LED_On(1);

osDelay(500);

LED_Off(1);

osDelay(500);

}}

### 28 CMSIS-RTOS Tutorial

Build the project and start the debugger

Start the code running and open the event viewer window

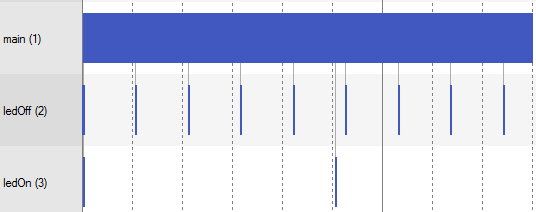
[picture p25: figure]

Now we can see that the activity of the code is very different. When each of the LED tasks reaches the osDelay API call it ‘blocks’ and moves to a waiting state. The main task will be in a ready state so the scheduler will start it running. When the delay period has timed out the led tasks will move to the ready state and will be placed into the running state by the scheduler. This gives us a multi threaded program where CPU runtime is efficiently shared between tasks.

# Virtual Timers

The CMSIS-RTOS API can be used to define any number of virtual timers which act as count down timers. When they expire, they will run a user call-back function to perform a specific action. Each timer can be configured as a one shot or repeat timer. A virtual timer is created by first defining a timer structure.

osTimerDef(timer0,led_function);

This defines a name for the timer and the name of the call back function. The timer must then be instantiated in an RTOS thread.

osTimerId timer0_handle = osTimerCreate (timer(timer0), osTimerPeriodic, (void *)0);

This creates the timer and defines it as a periodic timer or a single shot timer (osTimerOnce). The final parameter passes an argument to the call back function when the timer expires.

osTimerStart ( timer0_handle,0x100);

CMSIS-RTOS Tutorial

The timer can then be started at any point in a thread the timer start function invokes the timer by its handle and defines a count period in milliseconds.

## Exercise Virtual timer

In this exercise we will configure a number of virtual timers to trigger a callback function at various frequencies

In the Pack Installer select “Ex 6 Virtual Timers” and copy it to your tutorial directory.

This is our original led flasher program and code has been added to create four virtual timers to trigger a callback function. Depending on which timer has expired, this function will toggle an additional LED.

The timers are defined at the start of the code

osTimerDef(timer0_handle, callback);

osTimerDef(timer1_handle, callback);

osTimerDef(timer2_handle, callback);

osTimerDef(timer3_handle, callback);

They are then initialized in the main function

osTimerId timer0 = osTimerCreate(osTimer(timer0_handle), osTimerPeriodic, (void *)0);

osTimerId timer1 = osTimerCreate(osTimer(timer1_handle), osTimerPeriodic, (void *)1);

osTimerId timer2 = osTimerCreate(osTimer(timer2_handle), osTimerPeriodic, (void *)2);

osTimerId timer3 = osTimerCreate(osTimer(timer3_handle), osTimerPeriodic, (void *)3);

Each timer has a different handle and ID and passed a different parameter to the common callback function

void callback(void const *param){

switch( (uint32_t) param){

case 0:

GPIOB->ODR ^= 0x8;

### 30 CMSIS-RTOS Tutorial

break;

case 1:

GPIOB->ODR ^= 0x4;

break;

case 2:

GPIOB->ODR ^= 0x2;

break;

case 3:

break;

}

When triggered, the callback function uses the passed parameter as an index to toggle the desired LED.

In addition to the configuring the virtual timers in the source code, the timer thread must be enabled in the RTX configuration file.

Open the RTX_Conf_CM.c file and press the configuration wizard tab

In the system configuration section make sure the User Timers box is ticked. If this thread is not created the timers will not work.

Build the project and start the debugger

Run the code and observe the activity of the GPIOB pins in the peripheral window

CMSIS-RTOS Tutorial

There will also be an additional thread running in the System and Thread Viewer window

The osDelay() function provides a relative delay from the point at which the delay is started. The virtual timers provide an absolute delay which allows you to schedule code to run at fixed intervals.

## Sub millisecond delays

While the various CMSIS-RTOS time functions have a resolution of 1msec, it is possible to create delays with a resolution in micro seconds using the raw SysTick count. This form of delay does not deschedule the task, it simply halts its execution for the desired period. To create a delay we can first get the SysTick count.

int32_t tick,delayPeriod;

tick = osKernelSysTick(); | // get start value of the Kernel system tick

Then we can scale a period in microseconds to a SysTick count value

delayPeriod = osKernelTickMicroSec(100));

This then allows us to create a delay for the the required period.

do { | // Delay for 100 microseconds

### 32 CMSIS-RTOS Tutorial

} while ((osKernelSysTick() - tick) < delayPeriod);

# Idle Demon

The final timer service provided by the RTOS isn’t really a timer, but this is probably the best place to discuss it. If during our RTOS program we have no thread running and no thread ready to run (e.g. they are all waiting on delay functions) then the RTOS will use the spare runtime to call an “Idle Demon” that is again located in the RTX_Conf_CM.c file. This idle code is in effect a low priority thread within the RTOS which only runs when nothing else is ready.

void os_idle_demon (void)
{
for (;;) {
/* HERE: include here optional user code to be executed when no thread runs. | */
}
} /* end of os_idle_demon */

You can add any code to this thread, but it has to obey the same rules as user threads. The simplest use of the idle demon is to place the microcontroller into a low-power mode when it is not doing anything.

void os_idle_demon (void) {

__wfe();

}}

What happens next depends on the power mode selected in the microcontroller. At a minimum the CPU will halt until an interrupt is generated by the SysTick timer and execution of the scheduler will resume. If there is a thread ready to run then execution of the application code will resume. Otherwise, the idle demon will be reentered and the system will go back to sleep.

## Exercise Idle Thread

In the Pack Installer select “Ex 7 Idle” and copy it to your tutorial directory.

CMSIS-RTOS Tutorial

This is a copy of the virtual timer project. Open the RTX_Conf_CM.c file and click the text editor tab

Locate the os_idle_demon thread

void os_idle_demon (void) {

int32_t i;

for (;;) {

//wfe();

}}

Build the code and start the debugger

Run the code and observe the activity of the threads in the event Viewer.

This is a simple program which spend most of its time in the idle demon so this code will be run almost continuously

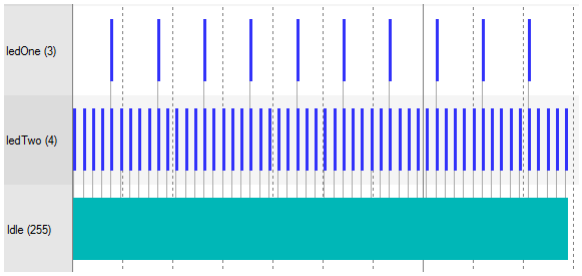
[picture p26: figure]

You can also see the activity of the idle demon in the event viewer. In a real project, the amount of time spent in the idle demon is an indication of spare CPU cycles.

Open the View → Analysis Windows → Performance Analyzer.

### 34 CMSIS-RTOS Tutorial

This window shows the cumulative run time for each function in the project. In this simple project the os_idle_demon is using most of the runtime because there is very little application code.

Exit the debugger

Remove the delay loop and the toggle instruction and add a __wfe() instruction in the for loop, so the code now looks like this.

void os_idle_demon (void) {

for (;;) {

__wfe();

}}

Rebuild the code, restart the debugger

Now when we enter the idle thread the __wfe() (wait for interrupt) instruction will halt the CPU until there is a peripheral or SysTick interrupt.

Performance analysis during hardware debugging

CMSIS-RTOS Tutorial

The code coverage and performance analysis tools are available when you are debugging on real hardware rather than simulation. However, to use these features you need two things: First, you need a microcontroller that has been fitted with the optional Embedded Trace Macrocell (ETM). Second, you need to use Keil ULINKpro debug adapter which supports instruction trace via the ETM.

# Inter-Thread Communication

So far we have seen how application code can be defined as independent threads and how we can access the timing services provided by the RTOS. In a real application we need to be able to communicate between threads in order to make an application useful. To this end, a typical RTOS supports several different communication objects which can be used to link the threads together to form a
meaningful | program. | The | CMSIS-RTOS | API | supports | inter-thread
communication with signals, semaphores, mutexes, mailboxes and message queues. In the first section the key concept was concurrency. In this section the key concept is synchronizing the activity of multiple threads.

## Signals

CMSIS-RTOS Keil RTX supports up to sixteen signal flags for each thread. These signals are stored in the thread control block. It is possible to halt the execution of a thread until a particular signal flag or group of signal flags are set by another thread in the system.

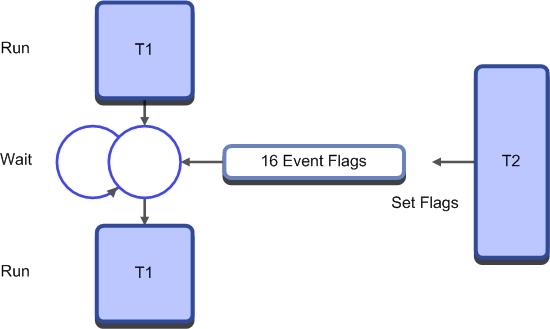
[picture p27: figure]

The signal wait system calls will suspend execution of the thread and place it into the wait_evnt state. Execution of the thread will not start until all the flags set in the signal wait API call have been set. It is also possible to define a periodic timeout after which the waiting thread will move back to the ready state, so that it

Each thread has 16 signal flags. A thread may be placed into a waiting state until a pattern of flags is set by another thread. When this happens, it will return to the ready state and wait to be scheduled by the kernel.

### 36 CMSIS-RTOS Tutorial

can resume execution when selected by the scheduler. A value of 0xFFFF defines an infinite timeout period.

osEvent osSignalWait ( int32_t signals,uint32_t millisec);

If the signals variable is set to zero when osSignalWait is called then setting any flag will cause the thread to resume execution. You can see which flag was set by reading the osEvent.value.signals return value.

Any thread can set or clear a signal on any other thread.

int32_t osSignalSet ( osThreadId thread_id, int32_t signals);

int32_t osSignalClear ( osThreadId thread_id, int32_t signals);

## Exercise Signals

In this exercise we will look at using signals to trigger activity between two threads. Whilst this is a simple program it introduces the concept of synchronizing the activity of threads together.

In the Pack Installer select “Ex 8 Signals” and copy it to your tutorial directory.

This is a modified version of the led flasher program one of the threads calls the same led function and uses osDelay() to pause the task. In addition it sets a signal flag to wake up the second led task.

void led_Thread2 (void const *argument) {

for (;;) {

LED_On(2);

osSignalSet (T_led_ID1,0x01);

osDelay(500);

CMSIS-RTOS Tutorial

LED_Off(2);

osSignalSet | (T_led_ID1,0x01);

osDelay(500);}}

The second led function waits for the signal flags to be set before calling the led functions.

void led_Thread1 (void const *argument) {

for (;;) {

osSignalWait (0x01,osWaitForever);

LED_On(1);

osSignalWait (0x01,osWaitForever);

LED_Off(1);

}}

Build the project and start the debugger

Open the GPIOB peripheral window and start the code running

Now the port pins will appear to be switching on and off together. Synchronizing the threads gives the illusion that both threads are running in parallel.

This is a simple exercise but it illustrates the key concept of synchronizing activity between threads in an RTOS based application.

## RTOS Interrupt Handling

The use of signal flags is a simple and efficient method of triggering actions between threads running within the RTOS. Signal flags are also an important method of triggering RTOS threads from interrupt sources within the Cortex-M microcontroller. While it is possible to run C code in an interrupt service routine (ISR), this is not desirable within an RTOS if the interrupt code is going to run for more than a short period of time. This delays the timer tick and disrupts the RTOS kernel. The SysTick timer runs at the lowest priority within the NVIC so there is no overhead in reaching the interrupt routine.

### 38 CMSIS-RTOS Tutorial

With an RTOS application it is best to design the interrupt service code as a thread within the RTOS and assign it a high priority. The first line of code in the interrupt thread should make it wait for a signal flag. When an interrupt occurs, the ISR simply sets the signal flag and terminates. This schedules the interrupt thread which services the interrupt and then goes back to waiting for the next signal flag to be set.

# Main

ISR level 0

ISR level 1

ISR level 2

ISR level 0

ISR level 1

# Round Robin Threads

priority normal

ISR 0 Thread priority above normal

ISR 1 Thread priority High

A traditional nested interrupt | scheme | supports prioritised interrupt
handling, but has unpredictable stack requirements.

Within the RTOS, interrupt code is run as threads. The interrupt handlers signal the threads when an interrupt occurs. The thread priority level defines which thread gets scheduled by the kernel.

CMSIS-RTOS Tutorial

A typical interrupt thread will have the following structure:

void Thread3 (void)
{

while(1)
{
osSignalWait ( isrSignal,waitForever); | // Wait for the ISR to trigger an event
| | // Handle the interrupt
} | // Loop round and go back sleep
}

The actual interrupt source will contain a minimal amount of code.

void IRQ_Handler (void)

{

osSignalSet (tsk3,isrSignal); | // Signal Thread 3 with an event

}

## Exercise Interrupt signal exercise

CMSIS-RTOS does not introduce any latency in serving interrupts generated by user peripherals. However operation of the RTOS may be disturbed if you lock out the SysTick interrupt for a long period of time. This exercise demonstrates a technique of signaling a thread from an interrupt and servicing the peripheral interrupt with a thread rather than a standard Interrupt service routine

In the Pack Installer select “Ex 9 Interrupt Signals” and copy it to your tutorial directory.

In the main function we initialize the ADC and create an ADC thread which has a higher priority than all the other threads

osThreadDef(adc_Thread, osPriorityAboveNormal, 1, 0);

int main (void) {

LED_Init ();

init_ADC ();

### 40 CMSIS-RTOS Tutorial

T_led_ID1 = | osThreadCreate(osThread(led_Thread1), NULL);
T_led_ID2 = | osThreadCreate(osThread(led_Thread2), NULL);
T_adc_ID = | osThreadCreate(osThread(adc_Thread), NULL);

However, there is a problem when we enter main: the RTOS may be configured to run the threads in unprivileged mode so we cannot access the NVIC registers without causing a fault exception. There are several ways round this. The simplest is to give the threads privileged access by changing the setting in the RTX_Conf_CM.c

Here, we have switched the thread execution mode to privileged which gives the threads full access to the Cortex-M processor. As we have added a thread, we also need to increase the number of concurrent running threads.

Build the code and start the debugger

Set breakpoints in led_Thread2, ADC_Thread and ADC1_2_IRQHandler

And in adc_Thread()

And in ADC1_2_Handler

CMSIS-RTOS Tutorial

Run the code

You should hit the first breakpoint which starts the ADC conversion, then run the code again and you should enter the ADC interrupt handler. The handler sets the adc_thread signal and quits. Setting the signal will cause the adc thread to preempt any other running task, run the ADC service code and then block waiting for the next signal.

## Exercise Keil RTX and SVC exceptions

As we saw in the last example, when we are in a thread, it will be running in unprivileged mode. The simple solution is to allow threads to run in privileged mode but this allows the threads full access to the Cortex M processor potentially allowing runtime errors. In this exercise we will look at using the system call exception to enter privileged mode to run ‘system level’ code.

In the Pack Installer select “Ex 10 Interrupt Signals” and copy it to your tutorial directory.

In the project we have added a new file called SVC_Table.s. This file is available as a ‘User Code Template’ (CMSIS-RTOS User SVC) from the ‘Add New Item’ dialog:

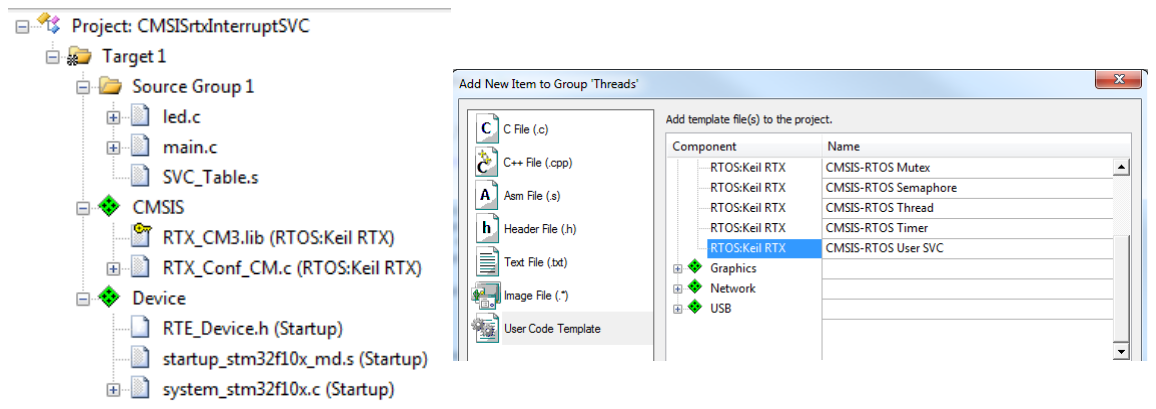
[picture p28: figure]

This is the look up table for the SVC interrupts

; Import user SVC functions here.

IMPORT __SVC_1

### 42 CMSIS-RTOS Tutorial

EXPORT SVC_Table

SVC_Table

; Insert user SVC functions here. SVC 0 used by RTX Kernel.

DCD | __SVC_1 | ; user SVC function

In this file we need to add import name and table entry for each __SVC function we are going to use. In our example we only need __SVC_1

Now we can convert the ADC init function to a service call exception

void __svc(1) init_ADC (void);

void __SVC_1 (void){

Build the project and start the debugger

Step the code (F11) to the call to the init_ADC function and examine the operating mode in the register window.

Here we are in Thread mode, unprivileged and using the process stack

Now step into the function (F11) and step through the assembler until you reach the init_ADC C function

Now we are running in Handler mode with privileged access and are using the main stack pointer.

CMSIS-RTOS Tutorial

This allows us the setup the ADC and also access the NVIC.

# Semaphores

Like signals, semaphores are a method of synchronizing activity between two or more threads. Put simply, a semaphore is a container that holds a number of tokens. As a thread executes, it will reach an RTOS call to acquire a semaphore token. If the semaphore contains one or more tokens, the thread will continue executing and the number of tokens in the semaphore will be decremented by one. If there are currently no tokens in the semaphore, the thread will be placed in a waiting state until a token becomes available. At any point in its execution, a thread may add a token to the semaphore causing its token count to increment by one.

The diagram above illustrates the use of a semaphore to synchronize two threads. First, the semaphore must be created and initialized with an initial token count. In this case the semaphore is initialized with a single token. Both threads will run and reach a point in their code where they will attempt to acquire a token from the semaphore. The first thread to reach this point will acquire the token from the semaphore and continue execution. The second thread will also attempt to acquire a token, but as the semaphore is empty it will halt execution and be placed into a waiting state until a semaphore token is available.

Meanwhile, the executing thread can release a token back to the semaphore. When this happens, the waiting thread will acquire the token and leave the waiting state for the ready state. Once in the ready state the scheduler will place the thread into the run state so that thread execution can continue. While semaphores have a simple set of OS calls they can be one of the more difficult OS objects to fully understand. In this section we will first look at how to add

Semaphores help to control access to program resources. Before a thread can access a resource, it must acquire a token. If none is available, it waits. When it is finished with the resource, it must return the token.

### 44 CMSIS-RTOS Tutorial

semaphores to an RTOS program and then go on to look at the most useful semaphore applications.

To use a semaphore in the CMSIS-RTOS you must first declare a semaphore container:

osSemaphoreId sem1;

osSemaphoreDef(sem1);

Then within a thread the semaphore container can be initialised with a number of tokens.

sem1 = osSemaphoreCreate(osSemaphore(sem1), SIX_TOKENS);

It is important to understand that semaphore tokens may also be created and destroyed as threads run. So for example you can initialise a semaphore with zero tokens and then use one thread to create tokens into the semaphore while another thread removes them. This allows you to design threads as producer and consumer threads.

Once the semaphore is initialized, tokens may be acquired and sent to the semaphore in a similar fashion to event flags. The os_sem_wait call is used to block a thread until a semaphore token is available, like the os_evnt_wait call. A timeout period may also be specified with 0xFFFF being an infinite wait.

osStatus osSemaphoreWait(osSemaphoreId semaphore_id, uint32_t millisec);

Once the thread has finished using the semaphore resource, it can send a token to the semaphore container.

osStatus osSemaphoreRelease(osSemaphoreId semaphore_id);

## Exercise Semaphore Signalling

In this exercise we will look at the configuration of a semaphore and use it to signal between two tasks.

In the Pack Installer select “Ex 11 Interrupt Signals” and copy it to your tutorial directory.

CMSIS-RTOS Tutorial

First, the code creates a semaphore called sem1 and initialises it with zero tokens.

osSemaphoreId sem1;
osSemaphoreDef(sem1);
int main (void) {
sem1 = osSemaphoreCreate(osSemaphore(sem1), 0);

The first task waits for a token to be sent to the semaphore.

void led_Thread1 (void const *argument) {
for (;;) {
osSemaphoreWait(sem1, osWaitForever); LED_On(1);
osDelay(500);
LED_Off(1);
}
}

While the second task periodically sends a token to the semaphore.

void led_Thread2 (void const *argument) {
for (;;) {
LED_On(2);
osSemaphoreRelease(sem1);
osDelay(500);
LED_Off(2);
osDelay(500);
}}

Build the project and start the debugger

Set a breakpoint in the led_Thread2 task

Run the code and observe the state of the threads when the breakpoint is reached.

### 46 CMSIS-RTOS Tutorial

Now led_thread1 is blocked waiting to acquire a token from the semaphore. led_Thread1 has been created with a higher priority than led_thread2 so as soon
as a token is placed in the semaphore it will move to the ready state and pre-empt the lower priority task and start running. When it reaches the osSemaphoreWait() call it will again block.
Now block step the code (F10) and observe the action of the threads and the semaphore.

# Using Semaphores

Although semaphores have a simple set of OS calls, they have a wide range of synchronizing applications. This makes them perhaps the most challenging RTOS object to understand. In this section we will look at the most common uses of semaphores. These are taken from “The Little Book Of Semaphores” by Allen
B. Downey. This book may be freely downloaded from the URL given in the bibliography at the end of this book.

# Signaling

Synchronizing the execution of two threads is the simplest use of a semaphore:

osSemaphoreId sem1;

osSemaphoreDef(sem1);

void thread1 (void)
{
sem1 = osSemaphoreCreate(osSemaphore(sem1), 0);

while(1)
{
FuncA();
osSemaphoreRelease(sem1)
}
}

void task2 (void)
{

while(1)
{
osSemaphoreWait(sem1,osWaitForever) FuncB();

CMSIS-RTOS Tutorial

}
}

In this case the semaphore is used to ensure that the code in FuncA() is executed before the code in FuncB().

# Multiplex

A multiplex is used to limit the number of threads that can access a critical section of code. For example, this could be a routine that accesses memory resources and can only support a limited number of calls.

osSemaphoreId multiplex;

osSemaphoreDef(multiplex);

void thread1 (void)
{
multiplex =osSemaphoreCreate(osSemaphore(multiplex), FIVE_TOKENS);

while(1) {
osSemaphoreWait(multiplex,osWaitForever)
ProcessBuffer();
osSemaphoreRelease(multiplex);
}}

In this example we initialise the multiplex semaphore with 5 tokens. Before a thread can call the ProcessBuffer() function, it must acquire a semaphore token. Once the function has completed, the token is sent back to the semaphore. If more than five threads are attempting to call ProcessBuffer(), the sixth must wait until a thread has finished with ProcessBuffer() and returns its token. Thus the multiplex semaphore ensures that a maximum of five threads can call the ProcessBuffer() function “simultaneously”.

### 48 CMSIS-RTOS Tutorial

# Exercise Multiplex

In this exercise we will look at using a semaphore to control access to a function by creating a multiplex.

In the Pack Installer select “Ex 12 Multiplex” and copy it to your tutorial directory.

The project creates a semaphore called semMultiplex which contains one token. Next, six instances of a thread containing a semaphore multiplex are created.

Build the code and start the debugger

Open the Peripherals → General Purpose IO → GPIOB window

Run the code and observe how the tasks set the port pins

As the code runs only one thread at a time can access the LED functions so only one port pin is set.

Exit the debugger and increase the number of tokens allocated to the semaphore when it is created

semMultiplex = osSemaphoreCreate(osSemaphore(semMultiplex), 3);

Build the code and start the debugger

Run the code and observe the GPIOB pins

Now three threads can access the led functions ‘concurrently’.

# Rendezvous

A more generalised form of semaphore signalling is a rendezvous. A rendezvous ensures that two threads reach a certain point of execution. Neither may continue until both have reached the rendezvous point.

osSemaphoreId arrived1,arrived2;

osSemaphoreDef(arrived1);

CMSIS-RTOS Tutorial

osSemaphoreDef(arrived2);

void thread1 (void){
Arrived1 =osSemaphoreCreate(osSemaphore(arrived1),ZERO_TOKENS); Arrived2 =osSemaphoreCreate(osSemaphore(arrived2),ZERO_TOKENS); while(1){
FuncA1();
osSemaphoreRelease(Arrived1); osSemaphoreWait(Arrived2,osWaitForever); FuncA2();
}}

void thread2 (void) {
while(1){
FuncB1();
Os_sem_send(Arrived2);
os_sem_wait(Arrived1,osWaitForever); FuncB2();
}}

In the above case the two semaphores will ensure that both threads will rendezvous and then proceed to execute FuncA2() and FuncB2().

## Exercise Rendezvous

In this project we will create two tasks and make sure that they have reached a semaphore rendezvous before running the LED functions.

In the Pack Installer select “Ex 13 Rendezvous” and copy it to your tutorial directory.

Build the project and start the debugger.

Open the Peripherals\General Purpose IO\GPIOB window.

Run the code

Initially the semaphore code in each of the LED tasks is commented out. Since the threads are not synchronised the GPIO pins will toggle randomly.

Exit the debugger

Un-comment the semaphore code in the LED tasks.

### 50 CMSIS-RTOS Tutorial

Built the project and start the debugger.

Run the code and observe the activity of the pins in the GPIOB window.

Now the tasks are synchronised by the semaphore and run the LED functions ‘concurrently’.

# Barrier Turnstile

Although a rendezvous is very useful for synchronising the execution of code, it only works for two functions. A barrier is a more generalised form of rendezvous which works to synchronise multiple threads.

osSemaphoreId count,barrier;

osSemaphoreDef(counter);

osSemaphoreDef(barrier);

unsigned int count;

void thread1 (void)
{
count = osSemaphoreCreate(osSemaphore(count),ONE_TOKEN); barrier = osSemaphoreCreate(osSemaphore(barrier),ZERO_TOKENS);

while(1)
{
//Allow only one task at a time to run this code osSemaphoreWait(counter);
count = count+1;
if count == 5 os_sem_send(barrier, osWaitForever); osSemaphoreRelease(counter);

//when all five tasks have arrived the barrier is opened os_sem_wait(barrier, osWaitForever); os_sem_send(barrier);

critical_Function();
}}

In this code we use a global variable to count the number of threads which have arrived at the barrier. As each function arrives at the barrier it will wait until it can acquire a token from the counter semaphore. Once acquired, the count variable will be incremented by one. Once we have incremented the count

CMSIS-RTOS Tutorial

variable, a token is sent to the counter semaphore so that other waiting threads can proceed. Next, the barrier code reads the count variable. If this is equal to the number of threads which are waiting to arrive at the barrier, we send a token to the barrier semaphore.

In the example above we are synchronising five threads. The first four threads will increment the count variable and then wait at the barrier semaphore. The fifth and last thread to arrive will increment the count variable and send a token to the barrier semaphore. This will allow it to immediately acquire a barrier semaphore token and continue execution. After passing through the barrier it immediately sends another token to the barrier semaphore. This allows one of the other waiting threads to resume execution. This thread places another token in the barrier semaphore which triggers another waiting thread and so on. This final section of the barrier code is called a turnstile because it allows one thread at a time to pass the barrier. In our model of concurrent execution this means that each thread waits at the barrier until the last arrives then the all resume simultaneously. In the following exercise we create five instances of one thread containing barrier code. However the barrier could be used to synchronise five unique threads.

## Exercise Semaphore Barrier

In this exercise we will use semaphores to create a barrier to synchronise multiple tasks.

In the Pack Installer select "Ex 14 Barrier" and copy it to your tutorial directory.

Build the project and start the debugger.

Open the Peripherals\General Purpose IO\GPIOB window.k

Run the code.

Initially, the semaphore code in each of the threads is commented out. Since the threads are not synchronised the GPIO pins will toggle randomly like in the rendezvous example.

Exit the debugger.

### 52 CMSIS-RTOS Tutorial

Remove the comments on lines 34, 45, 53 and 64 to enable the barrier code.

Built the project and start the debugger.

Run the code and observe the activity of the pins in the GPIOB window.

Now the tasks are synchronised by the semaphore and run the LED functions ‘concurrently’.

# Semaphore Caveats

Semaphores are an extremely useful feature of any RTOS. However semaphores can be misused. You must always remember that the number of tokens in a semaphore is not fixed. During the runtime of a program semaphore tokens may be created and destroyed. Sometimes this is useful, but if your code depends on having a fixed number of tokens available to a semaphore you must be very careful to always return tokens back to it. You should also rule out the possibility of accidently creating additional new tokens.

# Mutex

Mutex stands for “Mutual Exclusion”. In reality, a mutex is a specialized version of semaphore. Like a semaphore, a mutex is a container for tokens. The difference is that a mutex can only contain one token which cannot be created or destroyed. The principle use of a mutex is to control access to a chip resource such as a peripheral. For this reason a mutex token is binary and bounded. Apart from this it really works in the same way as a semaphore. First of all we must declare the mutex container and initialize the mutex:

osMutexId uart_mutex;

osMutexDef (uart_mutex);

Once declared the mutex must be created in a thread.

uart_mutex = osMutexCreate(osMutex(uart_mutex));

Then any thread needing to access the peripheral must first acquire the mutex token:

osMutexWait(osMutexId mutex_id,uint32_t millisec;

CMSIS-RTOS Tutorial

Finally, when we are finished with the peripheral the mutex must be released:

osMutexRelease(osMutexId mutex_id);

Mutex use is much more rigid than semaphore use, but is a much safer mechanism when controlling absolute access to underlying chip registers.

# Exercise Mutex

In this exercise our program writes streams of characters to the microcontroller UART from different threads. We will declare and use a mutex to guarantee that each thread has exclusive access to the UART until it has finished writing its block of characters.

In the Pack Installer select "Ex 15 Mutex" and copy it to your tutorial directory.

This project declares two threads which both write blocks of characters to the UART. Initially, the mutex is commented out.

void uart_Thread1 (void const *argument) {

uint32_t i;

for (;;) {

//osMutexWait(uart_mutex, osWaitForever);

for( i=0;i<10;i++) SendChar('1');

SendChar('\n');

SendChar('\r');

//osMutexRelease(uart_mutex);

}}

In each thread the code prints out the thread number. At the end of each block of characters it then prints the carriage return and new line characters.

Build the code and start the debugger.

### 54 CMSIS-RTOS Tutorial

Open the UART1 console window with View\Serial Windows\UART #1

Start the code running and observe the output in the console window.

Here we can see that the output data stream is corrupted by each thread writing to the UART without any accessing control.

Exit the debugger.

Uncomment the mutex calls in each thread.

Build the code and start the debugger.

Observe the output of each task in the console window.

CMSIS-RTOS Tutorial

Now the mutex guarantees each task exclusive access to the UART while it writes each block of characters.

# Mutex Caveats

Clearly you must take care to return the mutex token when you are finished with the chip resource, or you will have effectively prevented any other thread from accessing it. You must also be extremely careful about using the osThreadTerminate() call on functions which control a mutex token. Keil RTX is designed to be a small footprint RTOS so that it can run on even the very small Cortex-M microcontrollers. Consequently there is no thread deletion safety. This means that if you delete a thread which is controlling a mutex token, you will destroy the mutex token and prevent any further access to the guarded peripheral.

# Data Exchange

So far all of the inter-thread communication methods have only been used to trigger execution of threads; they do not support the exchange of program data between threads. Clearly, in a real program we will need to move data between threads. This could be done by reading and writing to globally declared variables. In anything but a very simple program, trying to guarantee data integrity would be extremely difficult and prone to unforeseen errors. The exchange of data between threads needs a more formal asynchronous method of communication.

### 56 CMSIS-RTOS Tutorial

CMSIS-RTOS provides two methods of data transfer between threads. The first method is a message queue which creates a buffered data ‘pipe’ between two threads. The message queue is designed to transfer integer values.

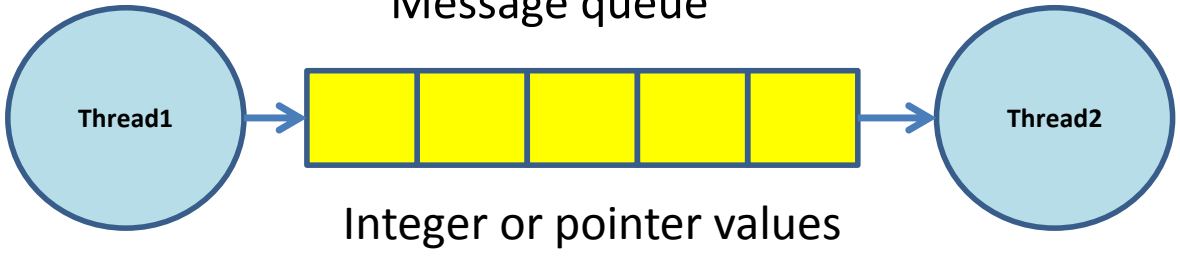
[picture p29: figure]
Thread1; Thread2; Integer or pointer values

The second form of data transfer is a mail queue. This is very similar to a message queue except that it transfers blocks of data rather than a single integer.

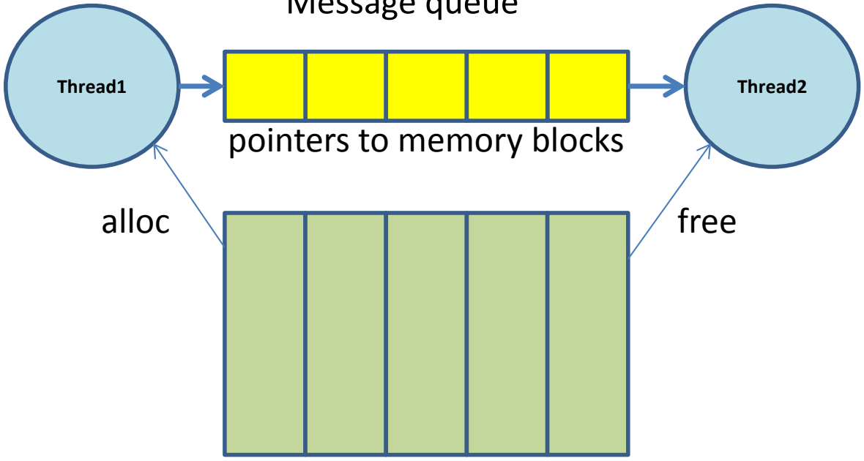
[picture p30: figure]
Thread1; Thread2; pointers to memory blocks; alloc; free

Message and mail queues both provide a method for transferring data between threads. This allows you to view your design as a collection of objects (threads) interconnected by data flows. The data flow is implemented by message and mail queues. This provides both a buffered transfer of data and a well defined communication interface between threads. Starting with a system level design based on threads connected by mail and message queues allows you to code different subsystems of your project, especially useful if you are working in a

# Message queue

# Message queue

# Mailslots – formatted memory blocks

CMSIS-RTOS Tutorial

team. Also as each thread has well defined inputs and outputs it is easy to isolate for testing and code reuse.

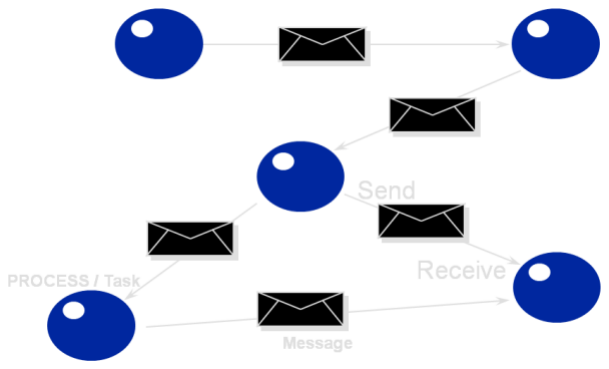
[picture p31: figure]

## Message Queue

To setup a message queue we first need to allocate the memory resources.

osMessageQId Q_LED;

osMessageQDef (Q_LED,16_Message_Slots,unsigned int);

This defines a message queue with sixteen storage elements. In this particular queue each element is defined as an unsigned int. Whilst we can post data directly into the message queue, it is also possible to post a pointer to a data object.

osEvent result;

We also need to define an osEvent variable which will be used to retrieve the queue data. The osEvent variable is a union that allows you to retrieve data from the message queue in a number of formats.

union{

uint32_t v

void *p

int32_t signals

The system level view of an RTOS based project consists of thread objects connected by data flows in the form of message and mail queues.

### 58 CMSIS-RTOS Tutorial

}value

The osEvent union allows you to read the data posted to the message queue as an unsigned int or a void pointer. Once the memory resources are created we can declare the message queue in a thread.

Q_LED = osMessageCreate(osMessageQ(Q_LED),NULL);

Once the message queue has been created we can put data into the queue from one thread.

osMessagePut(Q_LED,0x0,osWaitForever);

and then read if from the queue in another.

result = osMessageGet(Q_LED,osWaitForever);

LED_data = result.value.v;

## Exercise message queue

In this exercise we will look at defining a message queue between two threads and then use it to send process data.

In the Pack Installer select “Ex 16 Message Queue” and copy it to your tutorial directory.

Open Main.c and view the message queue initialization code.

osMessageQId Q_LED;

osMessageQDef (Q_LED,0x16,unsigned char);

osEvent result;

int main (void) {

LED_Init ();

Q_LED = osMessageCreate(osMessageQ(Q_LED),NULL);

We define and create the message queue in the main thread along with the event structure.

osMessagePut(Q_LED,0x1,osWaitForever);

CMSIS-RTOS Tutorial

osDelay(100);

Then in one of the threads we can post data and receive it in the second.

result = osMessageGet(Q_LED,osWaitForever);

LED_On(result.value.v);

Build the project and start the debugger.

Set a breakpoint in led_thread1.

Now run the code and observe the data as it arrives.

## Memory pool

While it is possible to post simple data values into the message queue it is also possible to post a pointer to a more complex object. CMSIS-RTOS supports the dynamic allocation of memory in the form of a memory pool. Here we can declare a structure which combines a number of data elements.

typedef struct {

uint8_t LED0;

uint8_t LED1;

uint8_t LED2;

uint8_t LED3;

} memory_block_t;

Then we can create a pool of these objects as blocks of memory.

osPoolDef(led_pool,ten_blocks,memory_block_t);

osPoolId( led_pool);

Then we can create the memory pool by declaring it in a thread.

### 60 CMSIS-RTOS Tutorial

led_pool = osPoolCreate(osPool(led_pool));

Now we can allocate a memory pool within a thread.

memory_block_t *led_data;

*led_data = (memory_block_t *) osPoolAlloc(led_pool);

and then populate it with data;

led_data->LED0 = 0;

led_data->LED1 = 1;

led_data->LED2 = 2;

led_data->LED3 = 3;

It is then possible to place the pointer to the memory block in a message queue.

osMessagePut(Q_LED,(uint32_t)led_data,osWaitForever);

so the data can be accessed by another task.

osEvent event; memory_block_t * received;

event = osMessageGet(Q_LED,osWatiForever);

*received = (memory_block *)event.value.p;

led_on(received->LED0);

Once the data in the memory block has been used the block must be released back to the memory pool for reuse.

osPoolFree(led_pool,received);

## Exercise Memorypool

This exercise demonstrates the configuration of a memorypool and message queue to transfer complex data between threads.

In the Pack Installer select “Ex 17 MemoryPool” and copy it to your tutorial directory.

CMSIS-RTOS Tutorial

This exercise creates a memory pool and a message queue. A producer thread acquires a buffer from the memory pool and fills it with data. A pointer to the memory pool buffer is then placed in the message queue. A second thread reads the pointer from the message queue and then accesses the data stored in the memory pool buffer before freeing the buffer back to the memory pool. This allows large amounts of data to be moved from one thread to another in a safe synchronized way. This is called a ‘zero copy’ memory queue as only the pointer is moved through the message queue, the actual data does not move memory locations.

At the beginning of main.c the memory pool and message queue are defined.

typedef struct {

uint8_t canData[8];

} message_t;

osPoolDef(mpool, 16, message_t);

osPoolId mpool;

osMessageQDef(queue, 16, message_t);

osMessageQId queue;

In the producer thread acquire a message buffer, fill it with data and post a testData++;

message = (message_t*)osPoolAlloc(mpool);

for(index =0;index<8;index++){

message->canData[index] = testData+index;}

osMessagePut(queue, (uint32_t)message, osWaitForever);

Then in the consumer thread we can read the message queue using the event.value.p pointer object and then access the memory pool buffer. Once we have used the data in the buffer it can be released back to the memory pool.

for(index=0;index<8;index++){

message_t *message = (message_t*)evt.value.p;

LED_On((uint32_t)message->canData[index]);}

### 62 CMSIS-RTOS Tutorial

osPoolFree(mpool, message);

Build the code and start the debugger.

Place breakpoints on the osMessagePut and osmessageGet functions.

Run the code and observe the data being transferred between the threads.

## Mail Queue

While memory pools can be used as data buffers within a thread, CMSIS-RTOS also implements a mail queue which is a combination of memory pool and message queue. The Mail queue uses a memory pool to create formatted memory blocks and passes pointers to these blocks in a message queue. This allows the data to stay in an allocated memory block while we only move a pointer between the different threads. A simple mail queue API makes this easy to setup and use. First we need to declare a structure for the mail slot similar to the one we used for the memory pool.

typedef struct {

uint8_t LED0;

uint8_t LED1;

uint8_t LED2;

uint8_t LED3;

} mail_format;

This message structure is the format of the memory block that is allocated in the mail queue. Now we can create the mail queue and define the number of memory block ‘slots’ in the mail queue.

CMSIS-RTOS Tutorial

osMailQDef(mail_box, sixteen_mail_slots, mail_format);

osMailQId mail_box;

Once the memory requirements have been allocated we can create the mail queue in a thread.

mail_box = osMailCreate(osMailQ(mail_box), NULL);

Once the mail queue has been instantiated we can post a message. This is different from the message queue in that we must first allocate a mail slot and populate it with data.

mail_format *LEDtx;

LEDtx = (mail_format*)osMailAlloc(mail_box, osWaitForever);

First declare a pointer in the mail slot format and then allocate this to a mail slot. This locks the mail slot and prevents it being allocated to any other thread. If all of the mail slots are in use the thread will block and wait for a mail slot to become free. You can define a timeout in milliseconds which will allow the task to continue if a mail slot has not become free.

Once a mail slot has been allocated it can be populated with data and then posted to the mail queue.

LEDtx->LED0 = led0[index];

LEDtx->LED1 = led1[index];

LEDtx->LED2 = led2[index];

LEDtx->LED3 = led3[index];

osMailPut(mail_box, LEDtx);

The receiving thread must declare a pointer in the mail slot format and an osEvent structure.

osEvent evt;

mail_format *LEDrx;

Then in the thread loop we can wait for a mail message to arrive.

### 64 CMSIS-RTOS Tutorial

evt = osMailGet(mail_box, osWaitForever);

We can then check the event structure to see if it is indeed a mail message and extract the data.

if (evt.status == osEventMail) {

LEDrx = (mail_format*)evt.value.p;

Once the data in the mail message has been used the mail slot must be released so it can be reused.

osMailFree(mail_box, LEDrx);

## Exercise Mailbox

This exercise demonstrates configuration a mailbox and using it to post messages between tasks.

In the Pack Installer select “Ex 17 Mailbox” and copy it to your tutorial directory.

The project creates a 16 slot mailbox to send LED data between threads.

typedef struct {
uint8_t LED0;
uint8_t LED1;
uint8_t LED2;
uint8_t LED3;
} mail_format;

osMailQDef(mail_box, 16, mail_format); osMailQId mail_box;

int main (void) {
LED_Init();
mail_box = osMailCreate(osMailQ(mail_box), NULL);

A producer task then allocates a mail slot fills it with data and posts it to the mail queue.

LEDtx = (mail_format*)osMailAlloc(mail_box, osWaitForever);

LEDtx->LED0 = led0[index];

CMSIS-RTOS Tutorial

LEDtx->LED1 = led1[index];

LEDtx->LED2 = led2[index];

LEDtx->LED3 = led3[index];

osMailPut(mail_box, LEDtx);

The receiving task waits for a mail message to arrive then reads the data. Once the data has been used the mail slot is released.

evt = osMailGet(mail_box, osWaitForever);

if(evt.status == osEventMail){

LEDrx = (mail_format*)evt.value.p;

LED_Out((LEDrx->LED0|LEDrx->LED1|LEDrx->LED2|LEDrx->LED3)<<8);

osMailFree(mail_box, LEDrx);

}

Build the code and start the debugger

Set a breakpoint in the consumer and producer threads and run the code.

Observe the mailbox messages arriving at the consumer thread.

# Configuration

So far we have looked at the CMSIS-RTOS API. This includes thread management functions, time management and inter-thread communication. Now that we have a clear idea of exactly what the RTOS kernel is capable of, we can take a more detailed look at the configuration file. There is one configuration file for all of the Cortex-M based microcontrollers.

### 66 CMSIS-RTOS Tutorial

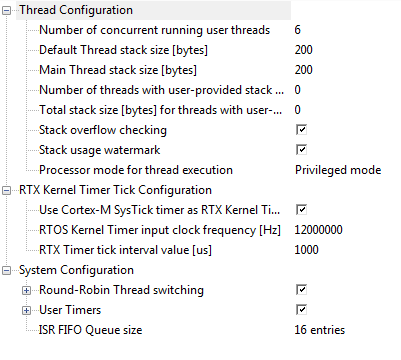
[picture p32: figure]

Like the other configuration files, the RTX_Conf_CM.c file is a template file which presents all the necessary configurations as a set of menu options.

# Thread Definition

In the thread definition section we define the basic resources which will be required by the CMSIS-RTOS threads. For each thread we allocate a defined stack space (in the above example this is 200 bytes.) We also define the maximum number of concurrently running threads. Thus, the amount of RAM required for the above example can easily be computed as 200 x 6 or 1200 bytes. If some of our threads need a larger stack space, then a larger stack can be allocated when the task is created. In addition the total custom stack size must be allocated in the configuration file along with the total number of threads with custom stack size. Again, the RAM requirement is easily calculated.

CMSIS-RTOS Tutorial

## Kernel Debug support

During development, CMSIS-RTOS can trap stack overflows. When this option is enabled, an overflow of a thread stack space will cause the RTOS kernel to call the os_error function which is located in the RTX_Conf_CM.c file. This function gets an error code and then sits in an infinite loop. The stack checking option is intended for use during debugging and should be disabled on the final application to minimize the kernel overhead. However, it is possible to modify the os_error() function if enhanced error protection is required in the final release.

#define OS_ERROR_STACK_OVF | 1

#define OS_ERROR_FIFO_OVF | 2

#define OS_ERROR_MBX_OVF | 3

extern osThreadId svcThreadGetId (void);

void os_error (uint32_t error_code) {

switch (error_code) {

case OS_ERROR_STACK_OVF:

/* Stack overflow detected for the currently running task. */

/* Thread can be identified by calling svcThreadGetId(). */

break;

case OS_ERROR_FIFO_OVF:

/* ISR FIFO Queue buffer overflow detected. */

break;

case OS_ERROR_MBX_OVF:

/* Mailbox overflow detected. */

break;

}

for (;;);

}

### 68 CMSIS-RTOS Tutorial

It is also possible to monitor the maximum stack memory usage during run time. If you check the ‘Stack Usage Watermark’ option, a pattern (0xCC) is written into each stack space. During runtime this watermark is used to calculate the maximum memory usage. This figure is reported in the threads section of the ‘System and Event Viewer’ window.

The final option in the thread definition section allows you to define the number of user timers. It is a common mistake to leave this set at zero. If you do not set this value to match the number of virtual timers in use by your application, the os_timer() API calls will fail to work. The thread definition section also allows us to select whether the threads are running in privileged or unprivileged mode.

## System Timer Configuration

The default timer for use with CMSIS-RTOS is the Cortex-M SysTick timer which is present on nearly all Cortex-M processors. The input to the SysTick timer will generally be the CPU clock. It is possible to use a different timer by unchecking the ‘Use SysTick’ option. If you do this there are two function stubs in the RTX_Conf_CM.c file that allow you to initialize the alternative timer and acknowledge its interrupt.

int os_tick_init (void) {

return (-1); /* Return IRQ number of timer (0..239) */

}

void os_tick_irqack (void) {

/* ... */

}

Whichever timer you use you must next setup its input clock value. Next we must define our timer tick rate. This is the rate at which timer interrupts are generated. On each timer tick the RTOS kernel will run the scheduler to determine if it is necessary to perform a context switch and replace the running

CMSIS-RTOS Tutorial

thread. The timer tick value will depend on your application, but the default starting value is set to 1msec.

# Timeslice configuration

The final configuration setting allows you to enable round robin scheduling and define the timeslice period. This is a multiple of the timer tick rate so in the above example each thread will run for five ticks or 5msec before it will pass execution to another thread of the same priority that is ready to run. If no thread of the same priority is ready to run, it will continue execution. The system configuration options also allow you to enable and configure the virtual timer thread. If you are going to use the virtual timers this option must be configured or the timers will not work. Then lastly if you are going to trigger a thread from an interrupt routine using event flags then it is possible to define a FIFO queue for triggered signals. This buffers signal triggers in the event of bursts of interrupt activity.

# Scheduling Options

CMSIS-RTOS allows you to build an application with three different kernel scheduling options. These are round robin scheduling, pre-emptive scheduling and co-operative multi-tasking. A summary of these options are as follows:

# Pre-emptive scheduling

If the round robin option is disabled in the RTX_Config_CM.c file, each thread must be declared with a different priority. When the RTOS is started and the threads are created, the thread with the highest priority will run.

In a pre-emptive RTOS each thread has a different priority level and will run until it is pre-empted or has reached a blocking OS call.

### 70 CMSIS-RTOS Tutorial

This thread will run until it blocks, i.e. it is forced to wait for an event flag, semaphore or other object. When it blocks, the next ready thread with the highest priority will be scheduled and will run until it blocks, or a higher priority thread becomes ready to run. So with pre-emptive scheduling we build a hierarchy of thread execution, with each thread consuming variable amounts of run time.

## Round-Robin Scheduling

A round-robin based scheduling scheme can be created by enabling the round-robin option in the RTX_Conf_CM.c file and declaring each thread with the same priority.

In this scheme, each thread will be allotted a fixed amount of run time before execution is passed to the next ready thread. If a thread blocks before its timeslice has expired, execution will be passed to the next ready thread.

## Round-Robin Pre-emptive Scheduling

As discussed at the beginning of this tutorial, the default scheduling option for the Keil RTX is round-robin pre-emptive. For most applications this is the most useful option and you should use this scheduling scheme unless there is a strong reason to do otherwise.

## Co-operative Multitasking

A final scheduling option is co-operative multitasking. In this scheme, round-robin scheduling is disabled and each thread has the same priority. This means that the first thread to run will run forever unless it blocks. Then execution will pass to the next ready thread.

In a round robin RTOS
threads will run for a fixed period or timeslice or until they reach a blocking OS

CMSIS-RTOS Tutorial

Threads can block on any of the standard OS objects, but there is also an additional OS call, os_task_pass, that schedules a thread to the ready state and passes execution to the next ready thread.

## RTX Source Code

CMSIS-RTOS Keil RTX is included with all versions of the MDK-ARM toolchain. The source code can be found in the following directory of the toolchain.

C:\Keil\ARM\Pack\ARM\CMSIS\<version>\CMSIS\RTOS\RTX

If you want to perform source level debugging of the RTOS code create a text file containing the following command line where the path is the RTX source directory.

SET SRC = <path>

Now add this file to the initialization box in the debugger menu.

In a co-operative RTOS each thread will run until it reaches a blocking OS call or uses the osThreadYield()

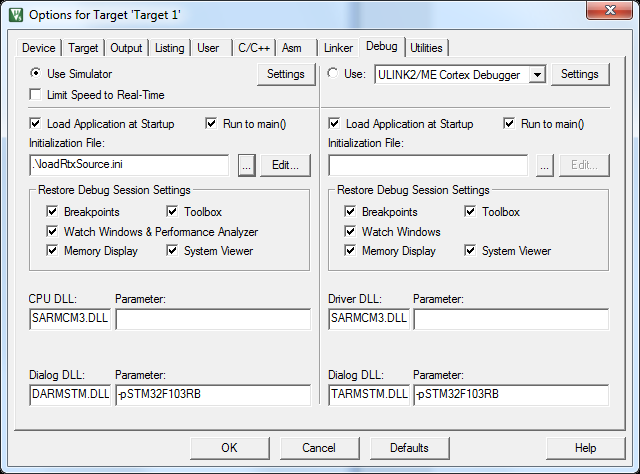
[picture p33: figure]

### 72 CMSIS-RTOS Tutorial

Now when you start the debug session the RTX source will be loaded.

## RTX License

CMSIS-RTOS Keil RTX is provided under a three clause BSD license and may be used freely without cost for commercial and non commercial projects. RTX will also compile using the IAR and GCC tools. For more information use the URL below.

https://www.keil.com/demo/eval/rtx.htm

## Hardware Debug

During this tutorial we have used the simulator within the µVision debugger. To debug real hardware you need to select the hardware interface you are using and select the radio button to enable hardware debug.

If your hardware debugger supports the CoreSight Instrumentation Trace Macrocell (ITM), you will be able to get the same debug information in the ‘System and Thread Viewer’ and ‘Event Viewer’. However, to make these windows active you must enable and configure the ITM. In the debug dialog press the settings button next to the hardware debug interface.

CMSIS-RTOS Tutorial

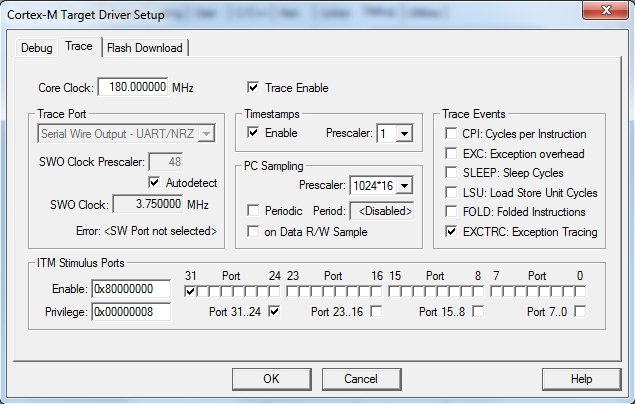
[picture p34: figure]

In this menu you must set the Core clock to the CPU frequency of your microcontroller.

Next tick the trace enable box.

Finally enable port 31 of the ITM stimulus ports

This will now receive the additional debug information sent by the RTX kernel.

### 74 CMSIS-RTOS Tutorial

## Further Reading

This tutorial is an excerpt from the Designers Guide to the Cortex-M Processor family by Trevor Martin.

Table of contents

Introduction to the Cortex-M Processor Family

Developing Software for the Cortex-M Processors

Cortex-M Architecture

Cortex Microcontroller Software Interface Standard

Advanced Architecture Features

Developing with CMSIS-RTOS

Practical DSP for the Cortex-M4

Debugging with CoreSight

For More details please see the Elsevier Store

Print book ISBN 978-0080982960

http://store.elsevier.com/product.jsp?isbn=9780080982960&pagename=search

E Book | ISBN 978-0080982991

http://store.elsevier.com/product.jsp?isbn=9780080982991&pagename=search

CMSIS-RTOS Tutorial

## Reference Material

Little Book Of Semaphores Allen B downey

http://www.greenteapress.com/semaphores/

## Training Courses

In Depth Training courses for the Cortex-M processors are available from Hitex in Germany and the UK.

Training courses in Germany

http://www.hitex.com/index.php?id=training&L=2

Training courses in the UK

http://www.hitex.co.uk/index.php?id=3431

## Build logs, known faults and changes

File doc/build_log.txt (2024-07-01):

28-mar-2023:

Started designing emulation board (need better name!) last Sunday, just to
see if it's possible. As of today, added PSRAM (32MB), and changed to 1.8v
operation. Used the modified RP2040 minimal board as a starting point,
and also upgraded to Kicad 6. Some strangenesses observed...

Now on to Micro SD and VGA support.
SD card from "Hardware Design with RP2040" uses:
GPIO 18-22: SD card data bus 0 to 3
GPIO 5 SD clk
GPIO 18 SD cmd

Now, if we want to use SPI mode only, need to map into a SPI instance
(DAT1 and DAT2 not used).
That means SD_CMD needs to transform into SPIO_RX. One pin that can do this
is GPIO16.

uSD Pinouts:
     uSD   SPI
1    Dat2  NC
2    Dat3  CS
3    CMD   DI  (MOSI)
4    VDD   VDD
5    SCLK  SCLK
6    VCC   VCC
7    Dat0  DO  (MISO)
8    Dat1  NC

uSD conn  RP GPIO Function
1 SD_DAT2   GPIO21  (not used)
2 SD_DAT3   GPIO22  (used as GPIO to do CS function)
3 SD_CMD    GPIO16  SPIO_RX
4 3V3 
5 SD_CLK    GPIO18  SPIO_SCK
6 GND
7 SD_DAT0   GPIO19  SPIO_TX
8 SD_DAT1   GPIO20  (not used)

29-mar-2023:
Unfortunately, we need to operate the uSD card at 3.3v I/O levels. A single
channel voltage translator is $0.39, and an 8 channel 110 MHz is $1.06

Using:
Using Ti TXS0108, which has several second sources, in QFN package.

30-mar-2023:
Using Hirose DMD3D uSD card socket, as there is a KiCad footprint available.
Not the cheapest socket, but not too bad: $1.69.

Ethernet:
RMII project: https://github.com/maximeborges/pico-rmii-ethernet
Uses:
MDC
CRS_DV
RXD1
RXD0
MDIO
R_RXCLK
TXD0
TXD1
TXEN

Wiring
RMII Module 	Raspberry Pi Pico 	Library Default
TX1 	TX0 + 1 	11
TX-EN 	TX0 + 2 	12
TX0 	any GPIO 	10
RX0 	any GPIO 	6
RX1 	RX0 + 1 	7
nINT / RETCLK 	   21/23/24/25 	         21
CRS 	RX0 + 2 	8
MDIO 	any GPIO 	14
MDC 	MDIO + 1 	15
VCC 	3V3 	
GND 	GND

So, we need 9 GPIOs. Have 11, without audio. If we use PWM audio
(2 pins), then we'd make it. Could give up CK#, to do I2S (3 pin) audio.
The LAN8720A does have variable I/O voltage, so no level translation
needed!

Also, it appears that MDIO uses I2C protocol, so could share this...

But, no pins left to do video...

Digikey has no stock on LAN8720A. Looking at eth board, it appears that
pin 9 (VDDIO) is brought out to a via, so may be possible to modify...

Will have to modify to accept external 50MHz clock input, so that
RP2040 can drive it directly.

Ethernet costs:
LAN8720A:   1.37
Jack w/mag: 2.14 (no LEDs)

Amazon:
DWEII 2PCS LAN8720 board: $11, so $5.50 per board.

For now, design in a connector. Digikey shows stock of LAN8720A in late July.

Could do both: footprint and connector...

No video for this pass. Also, may not have enough PIO space to drive
video in addition to Hyperbus, RMII, and SDIO.

Need to re-jigger SDIO, given need to use the 3.3v GPIO pins. Note: this
precludes the use of hardware SPI, since SD_DAT0 must be on GPIO26, and
this is assigned to SPI1 SCK. (Wish there was a GPIO30, then we could
start the SD data bus on GPIO27). 

So:

uSD conn  uSD SPI  RP GPIO Function
1 SD_DAT2   NC     GPIO28  SPI1_RX
2 SD_DAT3   CS     GPIO29  SPI1_CS
3 SD_CMD    DI
4 3V3       3V3
5 SD_CLK    SCLK
6 GND       GND
7 SD_DAT0   DO     GPIO26  SPI1_SCK
8 SD_DAT1   NC     GPIO27  SPI1_TX

Still need at least four channels of voltage translation:
2 for uSD (clk & cmd), and 2 for SWD/SWCLK.

Future pin reduction: PSRAM RESET#. Could be done as a power on reset via
external circuitry. Could also tie to RP2040 RUN pin.

LAN8720A module connector:
1) TX1      2) IOVDD (with mod)
3) TX_EN    4) TX0
5) RX0      6) RX1
7) RefClk   8) CRS
9) GND     10) GND
11) 3v3    12) 3v3

Note: Need to modify Waveshare LAN8720A board to make RefClk input
instead of output, and to add IOVDD to pin 2.

GPIO assignment:
RMII Module 	   RP2040
RX0 	any GPIO   GPIO15
RX1 	RX0 + 1    GPIO16
CRS 	RX0 + 2    GPIO17

TX0 	any GPIO   GPIO18
TX1 	TX0 + 1    GPIO19
TX-EN 	TX0 + 2    GPIO20

nINT / RETCLK 	   GPIO21
MDIO 	any GPIO   GPIO22  I2C1_SDA
MDC 	MDIO + 1   GPIO23  I2C1_SCL

Remaining GPIOS: 13 & 14. If we move RESET# to 14, then we could add a
uart on 12 & 13 (UART 0).

31-mar-2023:

If we take the CK# and RESET# from the PSRAM, then we could do mono video
and single channel PWM sound.

Not sure if there's enough PIO program space though.
SD card, sdio (4bit):
From: https://github.com/ZuluSCSI/ZuluSCSI-firmware
https://github.com/ZuluSCSI/ZuluSCSI-firmware/blob/main/lib/ZuluSCSI_platform_RP2040/rp2040_sdio.pio
_sdio.pio: sm0: 18, sm1: 5 + 9 = 14
 Exactly 32! No room for anything else on one state machine instance. It
 looks like there are actually two instances, each with their own 32 instruction
 memory. Yes, this is the case: pio0 has 32 locations and 4 sms, and pio1 the
 same.
Ethernet, RMII:
From: https://github.com/maximeborges/pico-rmii-ethernet
phy_tx.pio: 10 instructions
phy_rx.pio: 7 instructions
2 sm instances
Audio, PDM:
PDM.pio from https://github.com/tierneytim/Pico-USB-audio: 1 PIO instruction
I2S:
https://github.com/raspberrypi/pico-extras/blob/master/src/rp2_common/pico_audio_i2s/audio_i2s.pio
8 instructions
SPDIF:
4 instructions
Video: VGA:
https://github.com/raspberrypi/pico-extras/blob/master/src/common/pico_scanvideo/scanvideo.pio
32 instructions!
https://github.com/HughMaingauche/PICO-VGA-Micropython/blob/main/VGA.py
hsync: 9
vsync: 14
out: 8
total: 31
3 sm instances

If we used only hardware PWM for audio, that could help. 

Breakdown:
PIO/SMs  function #inst
0/0, 1   SDIO     32
1/0, 1   RMII     17
1/2      SPDIF    4
or
1/2      PWDM     1

Can we do video in 14 instructions?
Yes, with the help of DMA chaining! Use pixel out SM to do basic timing.
But, we'd most likely conflict with system timing, since we can't use
the fractional PIO clock divider (would lead to asymmetric pixels).

Could use the following system clocks:
MHz Enet Div
100 1
125 1.25
150 1.5
175 1.75
200 2

None of these are VGA pixel clocks. 150 is close to 148.5 (1920x1080p).

1-apr-2023:

Found:

Note that at Mouser, can get double density for the same price. So,
32 MB for $3 or 64 MB for $6? They are footprint compatible, so late
binding decision. (Digikey prices are 2x, and have limitied octal spi parts)
Octal SPI removes need for clk#, and reset# is optional, so gets back two
pins. Also, there are DQM, allowing for masked writes. Could be good for
graphics.

Etherenet repo:
https://github.com/maximeborges/pico-rmii-ethernet

5-apr-2023:
Going with the Octal SPI part, even though digikey doesn't have it. Arrow lists
it, but has no stock. $4.59 for 512Mbit. Only in-stock part is 128Mbit for 3.81.

Octal SPI frees up ck# pin, and reset# can be driven by an RC network.
This gives four pins available. If we use these as debug port, then
we can skip the 1.8v to 3.3v translator. $1.57 for TSSOP, $1.05 for VQFN
at digikey.

Going to keep this version simple, so no video/audio.

Oops! Re-reading the RP2040 datasheet:

It is safe to supply ADC_AVDD at a higher or lower voltage than IOVDD, e.g.
to power the ADC at 3.3V, for optimum performance, while supporting 1.8V
signal levels on the digital IO. But the voltage on the ADC analogue inputs must
not exceed IOVDD, e.g. if IOVDD is powered at 1.8V, the voltage on the ADC inputs should be limited to 1.8V. Voltages greater than IOVDD will result in leakage
currents through the ESD protection diodes. See Section 5.2.3, “Pin
Specifications” for details.

So, the scheme of using ADC I/O at 3.3v doesn't work. Do need the translator
for interfacing to the SD card. This will use 6 of the 8 available
translation circuits. Could use the remaining two for the SWD interface,
removing the need to have a 1.8v SWD programmer.

Need to re-jigger GPIO assignments, to allow SPI to drive SD card. (See above).

Think we should jumper SWD pins to enable selection between them and
UART. Then we can have a 1.8v UART, or 1.8v SWD. (Use one copy to debug
the other...)

Further refinements:
Put jumper on reset# to select between LED and reset#. Also enables use as
an external GPIO. Maybe GPIO25 for Pico compatibility. A green LED has a 2.0v
threshold, a rohm sample has 1.8v for yellow. Still seems like a good idea
to put a resistor in series (for current limiting), just in case. 

So:
SD card:
1 SD_DAT2   GPIO21  (not used)
2 SD_DAT3   GPIO22  (used as GPIO to do CS function)
3 SD_CMD    GPIO16  SPIO_RX
4 3V3 
5 SD_CLK    GPIO18  SPIO_SCK
6 GND
7 SD_DAT0   GPIO19  SPIO_TX
8 SD_DAT1   GPIO20  (not used)

and:

RMII Module 	Raspberry Pi Pico 	Library Default
TX1 	TX0 + 1 	11
TX-EN 	TX0 + 2 	12
TX0 	any GPIO 	10
RX0 	any GPIO 	6
RX1 	RX0 + 1 	7
nINT / RETCLK 	   21/23/24/25 	         21
CRS 	RX0 + 2 	8
MDIO 	any GPIO 	14
MDC 	MDIO + 1 	15
VCC 	3V3 	
GND 	GND

Rationalizing with PSRAM using GPIO0 to GPIO10:
TX0 	any GPIO 	13
TX1 	TX0 + 1 	14
TX-EN 	TX0 + 2 	15
nINT / RETCLK 	        24
RX0 	any GPIO 	25
RX1 	RX0 + 1 	26
CRS 	RX0 + 2 	27

MDIO 	any GPIO 	28 (I2C0 SDA)
MDC 	MDIO + 1 	29 (I2C0 SCL)

And
UART0 TX 12
UART0 RX 17

LED/reset# 23

6-apr-2023:

Ok, a layout attempt with the above gpio allocation really didn't look good.
The RMII TX0, 1, _EN are on the opposite side of the RP2040, and would
require circumnavigating the whole chip. These are high speed signals,
and would interfere with other signals. Also, the jumpering of SWD/UART0
creates routing problems...

Reorganizing GPIOs:
Push the SD card down, move the reset/led pin back.

SD card:
1 SD_DAT2   GPIO17  (not used)
2 SD_DAT3   GPIO18  (used as GPIO to do CS function)
3 SD_CMD    GPIO12  SPI1_RX
4 3V3 
5 SD_CLK    GPIO14  SPI1_SCK
6 GND
7 SD_DAT0   GPIO15  SPI1_TX
8 SD_DAT1   GPIO16  (not used)

7-apr-2023:

Finalizing layout. Need to align the three 3 pin jumper blocks:

JP2:
X: 113.11 mm
Y: 106.975

Conn J5 (gnd)
X: 115.65
Y: 106.975

JP1:
X: 118.19
Y: 106.975

Holes:
H1:
X: 73.19
Y: 74

H4:
X: 73.19
Y: 117.18

H2:
X: 117.29
Y: 74

H3:
X: 117.29
Y: 117.18

J6:
X: 78.25
Y: 118

J7:
X: 87.65
Y: 118

Move to:
X: 88.41

8-apr-2023:

Finalized board last night, and sent off to JLCPCB.com! Also submitted a fixed
version of the HP display driver board (addressed the swapped source/drains on
the column MOSFET drivers). Final cost was: $9.84 for 10 boards, including
$3.84 for shipping. Amazing!

Final GPIO assignment:
Ethernet:
Signal  Requirement    GPIO  Alternate function
TX0 	any GPIO 	0    UART0 TX/I2C0 SDA/SPI0 RX
TX1 	TX0 + 1 	1    UART0 RX/I2C0 SCL/SPI0 CSn
TX-EN 	TX0 + 2 	2    I2C1 SDA/SPI0 SCK

RX0 	any GPIO 	3    I2C1 SCL/SPI0 TX
RX1 	RX0 + 1 	4    UART1 TX/I2C0 SDA/SPI0 RX
CRS 	RX0 + 2 	5    UART1 RX/I2C0 SCL/SPI0 CSn

nINT / RETCLK 	        21 (Must be a RP2040 clock output, i.e. 21, 23, 24, 25)

MDIO 	any GPIO 	6    I2C1 SDA/SPI0 SCK
MDC 	MDIO + 1 	7    I2C1 SCL/SPI0 TX

SD Card:
Signal        
SDIO       SPI       Requirement   GPIO  Alternate function
1 SD_DAT2  (N/C)     SD_DAT1 + 1    13   SPI1 CSn
2 SD_DAT3  CS        SD_DAT2 + 1    14   SPI1 SCK
3 SD_CMD   RX (MOSI) any GPIO       8    SPI1 RX
4 3V3 
5 SD_CLK   SCK       any GPIO       10   SPI1 SCK
6 GND
7 SD_DAT0  TX (MISO) any GPIO       11   SPI1 TX
8 SD_DAT1  (N/C)     SD_DAT0 + 1    12   SPI1 RX

PSRAM:
Signal  Requirement    GPIO
DQ0     any GPIO       19
DQ1     DQ0 + 1        22 (FAIL! Violated the requirement)
DQ2     DQ1 + 1        23
DQ3     DQ2 + 1        24
DQ4     DQ3 + 1        25
DQ5     DQ4 + 1        26
DQ6     DQ5 + 1        27
DQ7     DQ6 + 1        28
CK      any GPIO       29
CS#
RWDS
CK#     (pulled down to gnd via 10K resistor)
RESET#  (pulled up to +1v8 via 10K resistor)

UART:
Signal  Requirement     GPIO   Function
TX      RP2040 UART TX  16     UART0TX
RX      RP2040 UART RX  17     UART0RX

GPIO
Signal  Requirement     GPIO   Function
0       any GPIO        9      UART1 Rx/I2C0 SDA
1       any GPIO        15     UART0 RTS/I2C1 SCL

OK, so two failures seen on the light of day:
1) SD Card SPI mode won't work: conflict between SPI RX and SD card SPI RX,
   and same for TX. Should have been RX->TX, and TX->RX.

2) PSRAM DQ0 not sequential with remaining DQS...

Need to do a spin...

First, reconfigure pinout:
Must use GPIO22 to 29 as DQ bus. CK will have to be on GPIO18. Messy.

SD Card:
Signal        
SDIO       SPI       Requirement   GPIO  Alternate function
1 SD_DAT2  (N/C)     SD_DAT1 + 1    14   
2 SD_DAT3  CS        SD_DAT2 + 1    15   SPI1 TX (Use as GPIO)
3 SD_CMD   RX (MOSI) any GPIO       11   SPI1 TX
4 3V3 
5 SD_CLK   SCK       any GPIO       10   SPI1 SCK 
6 GND
7 SD_DAT0  TX (MISO) any GPIO       12   SPI1 RX
8 SD_DAT1  (N/C)     SD_DAT0 + 1    13   

From: 
https://github.com/ZuluSCSI/ZuluSCSI-firmware/blob/main/lib/ZuluSCSI_platform_RP2040/ZuluSCSI_platform_gpio_BS2.h
// SD card pins in SDIO mode
#define SDIO_CLK 10
#define SDIO_CMD 11
#define SDIO_D0  12
#define SDIO_D1  13
#define SDIO_D2  14
#define SDIO_D3  15

// SD card pins in SPI mode
#define SD_SPI       spi0
#define SD_SPI_SCK   10
#define SD_SPI_MOSI  11
#define SD_SPI_MISO  12
#define SD_SPI_CS    15

(The SD_SPI #define looks questionable - should be spi1, according to the
RP2040 datasheet).

Note: was able to modify the Waveshare LAN8720 board to put IOVDD on pin 2 (the
previous NC pin), and change the clocking to external (remove the two 33 ohm
resistors, and put one across the two vacated pads next to the chip).

9-apr-2023:

Using https://github.com/carlk3/no-OS-FatFS-SD-SPI-RPi-Pico.git as a test
with a ltm board wired up as above.

git clone -b sdio --recurse-submodules https://github.com/carlk3/no-OS-FatFS-SD-SPI-RPi-Pico.git no-OS-FatFS

from the README:
Customize:

    Configure the code to match the hardware: see section Customizing for the Hardware Configuration, below.
    Customize ff14a/source/ffconf.h as desired
    Customize pico_enable_stdio_uart and pico_enable_stdio_usb in CMakeLists.txt as you prefer. (See 4.1. Serial input and output on Raspberry Pi Pico in Getting started with Raspberry Pi Pico and 2.7.1. Standard Input/Output (stdio) Support in Raspberry Pi Pico C/C++ SDK.)

Figured out how to change default UART pins:

Put this in the CMakeLists.txt, just before "target sources", changing exe name:

# Enable different UART pin definitions
target_compile_definitions(simple_example PRIVATE
  PICO_DEFAULT_UART_TX_PIN=16
  PICO_DEFAULT_UART_RX_PIN=17
)

Success! Running command_line example:
> mount
> getfree                                                                       
    258095 KiB total drive space.                                               
    202925 KiB available.                                                       
                                                                                
> cat LICENCE.broadcom                                                          
Copyright (c) 2006, Broadcom Corporation.                                       
Copyright (c) 2015, Raspberry Pi (Tradary form, without                         
modification, are permitted provided that the following condiy only be used for 
  running or using a Raspbeivative                                              
  device manufactured via the element14 Raspberry Pi Customization Serv* Rediste
  following rovided with the distribution.                                      
* Neither the name of Broadcom Corporation nor t this software                  
  without specific prior written permission.                                    
                                                                                
DISCLAIMER.  THDED BY THE COPYRIGHT HOLDERS AND                                 
CONTRIBUTORS "AS IS" AND ANY EXPRESS OR IMPLIUDING,                             
BUT NOT LIMITED TO, THE IMPLIED WARRANTIES OF MERCHANTABILITY AND               
FITNESS FOR A NT SHALL THE                                                      
COPYRIGHT OWNER OR CONTRIBUTORS BE LIABLE FOR ANY DIRECT, INDIRECTNSEQUENTIAL D,
BUT NOT LIMITED TO, PROCUREMENT OF SUBSTITUTE GODS OR SERVICES; LOSS            
OF USE, DATA, OR PROFITS; OR BUSINESS INTERRUPTION) HOWEIN CONTRACT, STRICT LIAR
TORT (INCLUDING NEGLIGENCE OR OTHERWISE) ARISUSE OF THIS SOFTWARE, EVEN IF ADVIH
DAMAGE.                                                                         

> 

Now to try the SDIO mode...

11-apr-2023:
Finally, success! Not sure what it took - perhaps powercycling all of the
components?

Oturing date: 11/2013

FILE_SIZE_MB = 5
BUF_SIZE = 20480
Starting write test,latency
speed,max,min,avg
KB/Sec,usec,usec,usec
                                                           
2849.4,17019,6457,7181
                                                          
2858.7,14090,6583,7160
Starting read test, please wait.
read speed and late4761.9,4702,4070,4300
4766.3,4696,4063,4298
Done

Really need to get a better version of picoprobe - apparently, servicing
the USB uart and the SWD port leads to dropped characters.
(Maybe use both cores?!)

29-apr-2023:

Rev 1.1 Final pinouts:
Ethernet:
Signal  Requirement    GPIO  Alternate function
TX0 	any GPIO 	0    UART0 TX/I2C0 SDA/SPI0 RX
TX1 	TX0 + 1 	1    UART0 RX/I2C0 SCL/SPI0 CSn
TX-EN 	TX0 + 2 	2    I2C1 SDA/SPI0 SCK

RX0 	any GPIO 	3    I2C1 SCL/SPI0 TX
RX1 	RX0 + 1 	4    UART1 TX/I2C0 SDA/SPI0 RX
CRS 	RX0 + 2 	5    UART1 RX/I2C0 SCL/SPI0 CSn

nINT / RETCLK 	        21 (Must be a RP2040 clock output, i.e. 21, 23, 24, 25)

MDIO 	any GPIO 	6    I2C1 SDA/SPI0 SCK
MDC 	MDIO + 1 	7    I2C1 SCL/SPI0 TX

SD Card:
Signal        
SDIO       SPI       Requirement   GPIO  Alternate function
1 SD_DAT2  (N/C)     SD_DAT1 + 1    14   
2 SD_DAT3  CS        SD_DAT2 + 1    15   SPI1 TX (Use as GPIO)
3 SD_CMD   RX (MOSI) any GPIO       11   SPI1 TX
4 3V3 
5 SD_CLK   SCK       any GPIO       10   SPI1 SCK 
6 GND
7 SD_DAT0  TX (MISO) any GPIO       12   SPI1 RX
8 SD_DAT1  (N/C)     SD_DAT0 + 1    13   

PSRAM:
Signal  Requirement    GPIO
DQ0     any GPIO       22
DQ1     DQ0 + 1        23
DQ2     DQ1 + 1        24
DQ3     DQ2 + 1        25
DQ4     DQ3 + 1        26
DQ5     DQ4 + 1        27
DQ6     DQ5 + 1        28
DQ7     DQ6 + 1        29
CK      any GPIO       18
CS#     any GPIO       19
RWDS    any GPIO       20
CK#     (pulled down to gnd via 10K resistor)
RESET#  (pulled up to +1v8 via 10K resistor)

UART:
Signal  Requirement     GPIO   Function
TX      RP2040 UART TX  16     UART0TX
RX      RP2040 UART RX  17     UART0RX

GPIO
Signal  Requirement     GPIO   Function
0       any GPIO        8      UART1 TX/I2C0 SDA
1       any GPIO        9      UART1 RX/I2C0 SCL

20-may-2023:

Figured out how to build custom stage two rp2040 boot loader. CMakfile:

# Select different boot_stage2 file
#set(PICO_DEFAULT_BOOT_STAGE2_FILE $ENV{PICO_SDK_PATH}/src/rp2_common/boot_stage2/boot2_usb_blinky.S)
#set(PICO_DEFAULT_BOOT_STAGE2_FILE $ENV{PWD}/boot_stage2/boot2_usb_blinky.S)
set(PICO_DEFAULT_BOOT_STAGE2_FILE $ENV{PWD}/boot_stage2/w25q80.S)
pico_define_boot_stage2(slower_boot2 ${PICO_DEFAULT_BOOT_STAGE2_FILE})
#target_compile_definitions(slower_boot2 PRIVATE PICO_FLASH_SPI_CLKDIV=4)
pico_set_boot_stage2(blink slower_boot2)

Verified with modified boot2_usb_blinky.S:
.thumb_func
_stage2_boot:
    add r0, r0, #2	
    b _stage2_boot

telnet devel0 4444

Trying 192.168.1.54...
Connected to devel0.light.com.
Escape character is '^]'.
Open On-Chip Debugger
> halt
target halted due to debug-request, current mode: Thread 
xPSR: 0x01000000 pc: 0x20041f00 msp: 0x20041ee8
> reg r0
r0 (/32): 0x79db8072

> resume
> halt
target halted due to debug-request, current mode: Thread 
xPSR: 0x01000000 pc: 0x00000138 msp: 0x20041f00
target halted due to debug-request, current mode: Thread 
xPSR: 0x01000000 pc: 0x20041f00 msp: 0x20041ee8
> reg r0
r0 (/32): 0x7f80ff40

OpenOCD memory read commands
mrb address
      Returns value of byte in memory. (command valid any time)
mrh address
      Returns value of halfword in memory. (command valid any time)
mrw address
      Returns value of word in memory. (command valid any time)

Before mod:
> mrw 0x40020000
0
> 

After adding at line 120:
    movs r0, #PADS_QSPI_VOLTAGE_SELECT_VALUE_1V8
    str r0, [r3, #PADS_QSPI_VOLTAGE_SELECT_OFFSET]

> mrw 0x40020000
1
>

Still doesn't boot. Trying the boot2_generic_03h.S file... Hurray, works!
Now have figure out why our W25Q64JW part doesn't work with the W25q080
rpi boot2 code. FYI, we did boot with a W25Q40CLSNIG (after modifying the
board to use 3.3v).

Modifying boot2_generic_03h.S to set threshold to 1.8v:
Before:
> mrw 0x40020000
0

Adding at line 22:
#include "hardware/regs/pads_qspi.h"

Adding at line 67:
    // Set pad configuration:
    // - 1.8v threshold for VDD of 1.8v	(20-may-2023 RS)
    ldr r3, =PADS_QSPI_BASE
    movs r0, #PADS_QSPI_VOLTAGE_SELECT_VALUE_1V8
    str r0, [r3, #PADS_QSPI_VOLTAGE_SELECT_OFFSET]

After mod:
> mrw 0x40020000
1
>

21-may-2023:

Found in picoboot sources:
#define ROM_START   0x00000000
#define ROM_END     0x00004000
#define FLASH_START 0x10000000
#define FLASH_END   0x11000000 // this is maximum
#define XIP_SRAM_BASE 0x15000000
#define XIP_SRAM_END 0x15004000

Apparently bricked board - didn't respond to openocd. Rebooting board in
dfu mode and reprogramming with standard blink allowed openocd to work
once again.

Ok, finally figured out problem: The W25Q64JW does not support "Continuous
Read Mode", while the W25Q64FW does. Digikey shows no stock for the F variant.

Phrase to look for is something like:
Allows XiP (eXecute In Place) Operation
- High speed Read reduce overall XiP instruction fetch time
- Continuous Read with Wrap further reduce data latency to
fill up SoC cache 

In stock digikey part is: GD25Q64E (has above phrase in datasheet). But it
is 2.7 to 3.6V supply. The GD25LQ64E is 1.65 to 2.0V, and is in stock.
Placed order for 10 parts. Will use boot2_generic_03 to do debugging for
now.

Also, we can support other boards via:
 cmake -DPICO_BOARD=shawns_board_name ..
See also:
https://github.com/raspberrypi/pico-sdk/blob/master/src/boards/include/boards/adafruit_feather_rp2040.h

Still having problems with board, even with generic flash code. Learning how
to use RAM only builds, and load with openocd load_image command.

Magic needed:
CMakeLists.txt:
cmake_minimum_required(VERSION 3.12)
include($ENV{PICO_SDK_PATH}/pico_sdk_init.cmake)

project(blink)

pico_sdk_init()

# source goes here
add_subdirectory(./src)

# Enable SRAM only executable
pico_set_binary_type(blink no_flash)

And a shell script with:
echo -e "reset halt\nload_image /home/rscott/$filename\nresume 0x20000000" | ncat devel0 4444

(with openocd running on devel0, of course...)

Works on both boards. Can also leave flash boot jumper installed, as openocd
doesn't care...

22-may-2023:
Got ID reads to work:

ID0: 0e860e86                                                                   
ID0.Row Address Bit Count: 01110                                                
  15 row address bits                                                           
ID0.Column Address Bit Count: 1000                                              
  9 column address bits                                                         
ID0.Manufacturer: 0110                                                          
  Windbond                                                                      

Thus, many of the PSRAM pins were toggled, so maybe the BGA soldering
was successful. Need to do an acutal read/write test to be sure...

One interesting thing to note: register reads are MSByte first:
// From the data sheet, pg. 13:
//   For register read, the output data Dn A is RG[15:8], Dn B is RG[7:0],
//   Dn+1 A is RG[15:8], Dn+1 B is RG[7:0]
// So, we must byte swap the returned data

23-may-2023:
Got PSRAM memory reads and writes working.

FYI:
32K Rows of 1KB = 32 MB.

Full 32MB memory test passing:

Pass: 0 WWWWWWWWWWWWWWWWWWWWWWWWWWWWWWWWRRRRRRRRRRRRRRRRRRRRRRRRRRRRRRRR        
Pass: 1 WWWWWWWWWWWWWWWWWWWWWWWWWWWWWWWWRRRRRRRRRRRRRRRRRRRRRRRRRRRRRRRR        
Pass: 2 WWWWWWWWWWWWWWWWWWWWWWWWWWWWWWWWRRRRRRRRRRRRRRRRRRRRRRRRRRRRRRRR        
Pass: 3 WWWWWWWWWWWWWWWWWWWWWWWWWWWWWWWWRRRRRRRRRRRRRRRRRRRRRRRRRRRRRRRR        
Pass: 4 WWWWWWWWWWWWWWWWWWWWWWWWWWWWWWWWRRRRRRRRRRRRRRRRRRRRRRRRRRRRRRRR        
Pass: 5 WWWWWWWWWWWWWWWWWWWWWWWWWWWWWWWWRRRRRRRRRRRRRRRRRRRRRRRRRRRRRRRR        
Pass: 6 WWWWWWWWWWWWWWWWWWWWWWWWWWWWWWWWRRRRRRRRRRRRRRRRRRRRRRRRRRRRRRRR        
Pass: 7 WWWWWWWWWWWWWWWWWWWWWWWWWWWWWWWWRRRRRRRRRRRRRRRRRRRRRRRRRRRRRRRR        
Pass: 8 WWWWWWWWWWWWWWWWWWWWWWWWWWWWWWWWRRRRRRRRRRRRRRRRRRRRRRRRRRRRRRRR        
Pass: 9 WWWWWWWWWWWWWWWWWWWWWWWWWWWWWWWWRRRRRRRRRRRRRRRRRRRRRRRRRRRRRRRR        
Pass: 10 WWWWWWWWWWWWWWWWWWWWWWWWWWWWWWWWRRRRRRRRRRRRRRRRRRRRRRRRRRRRRRRR       
Pass: 11 WWWWWWWWWWWWWWWWWWWWWWWWWWWWWWWWRRRRRRRRRRRRRRRRRRRRRRRRRRRRRRRR

Coding bugs encountered:
1) Didn't realize that latency during writes affected when the writes begin. I.e.
when the latency count expires, writes will be performed! Also had a bug where
the latency counter reversed clock high and low assertions, causing the
first write to be delayed.
2) Masked too much of the PSRAM address. Caused half of memory to not be
available.
3) Didn't fully realize that PSRAM addresses memory as words. It assumes
that 16 bits are always transferred per clock.

Enabled variable latency mode, and shortened latency count. Still passes
memory test.

So, while wondering about how the HyperRAM deals with row crossings during
writes, this popped up from the datasheet:

During the write data transfers, RWDS is driven by the host master interface
as a data mask. When data is being written and RWDS is High the byte will be
masked and the array will not be altered. When data is being written and RWDS is
Low the data will be placed into the array. Because the master is driving RWDS
during write data transfers, neither the master nor the HyperRAM device is able
to indicate a need for latency within the data transfer portion of a write
transaction. The acceptable write data burst length setting is also shown in
configuration register 0.

Strictly speaking then - we must limit bursts to 128 B, as shown in
config 0. (Probably should also program this as well). I'm guessing there's
a 128 B write buffer in the PSRAM.

25-may-2023

So, reading the data sheet shows that commands/data  must have setup/hold times
around the clock. For 133 MHz parts, this is 0.8 ns. Also, read data
is strobed by RWDS, which driven by the part. It has setup/hold times of:
0.6 ns. The delay from clock to RWDS is 1 to 5.5ns.

So, order of operations for read data:
Generate clock rising edge
Sample RWDS
If set:
  Read databus for this edge (ph0)
  Generate clock falling edge
  Read databus (ph1)
  Done with read
else
  Generate clock falling edge
  Go back to start

So, with input pin mapping set to RWDS, side set RWDS, CD, CLK

  nop             1
sample:
  in pins, 1      1  ; Get RWDS
  mov X, ISR      1  ; Set up to test it
  jmp !X, DV      1  ; If not zero, data is valid
  jmp sample      0  ; Zero, so assert clock and sample again
DV:
  mov X, pins     1  ; Use output mapping to fetch data bus pins
  in X, 8         0  ; Accumulate them, setup to get ph1
  mov X, pins     0  ; Get ph1
  in X, 8         0

If we assume that burst length is limited, and we don't cross PSRAM row
boundaries, then can sample RWDS at beginning of cycle. The data read
routine would then look like:

  nop             1   ; Set up clock for ph0
  mov X, pins     1   ; Get ph0 data <31:24>
  in X, 8         0   ; Accumulate data, setup for ph1
  mov X, pins     0   ; Get ph1 data <23:16>
  in X, 8         1   ; Accumulate, set up for next ph0
  mov X, pins     1   ; Get ph0 data <15:08>
  in X, 8         0   ; Accumulate data, setup for ph1
  mov X, pins     0   ; Get ph1 data <07:00>
  in X, 8         2   ; Accumulate, and rase CE with clock low to end cycle

This gives setup from clock edge to data sample. Presumably, RP2040 can deal
with effectively no data hold time...

So, if we use the wrap around read mode, we'd never cross a row boundary. But
we'd always have to use a "cache-fill" model for block reads.

29-may-2023:

Reading more PIO code on the net, discovered that the JMP instruction can
jump on the state of a pin set via: EXECCTRL_JMP_PIN. This provides
a more convienent method of monitoring the RWDS pin...

So:
; In/Out/Mov instruction GPIO pin mapping
; <7:0> - PSRAM data

; SET instruction GPIO pin mapping
; 0 - RDWS

; EXECCTL GPIO pin mapping
; 0 - RWDS
psram:
    pull           side 2     ; Wait for input with clock low, CE high
    out ISR, 1     side 0     ; Get R/W flag, assert CE (1 = read)
    mov Y, ISR     side 0     ; Save flag
    out NULL, 5    side 0     ; Skip over unused address bits
    set X, 0x1     side 0     ; Set linear operation bit
    in X, 2        side 0     ; Should now have either 0x04 (rd) or 0x5 (wr)
    in NULL, 5     side 0     ; Make into 0xA0 or 0x20
    mov PINS, ISR  side 0     ; Output CR0, ph0
    out X, 7       side 1     ; Get address bits 25:19, latch ph0
    mov PINS, X    side 1     ; Output CR0, ph1
    out X, 8       side 0     ; Get address bits 18:11, latch ph1
    mov PINS, X    side 0     ; Output CR1, ph0
    out X, 8       side 1     ; Get address bits 10:03, latch ph0
    mov PINS, X    side 1     ; Output CR1, ph1
    set X, 0       side 0     ; Set up CR2, ph0, latch ph1
    mov PINS, X    side 0     ; Output CR2, ph0
    out X, 3       side 1     ; Get address bits 02:00, latch ph0
    mov PINS, X    side 1     ; Output CR2, ph1
    mov X, 13      side 1     ; Set up for extended latency
    jmp !Y, read   side 1     ; Go to read trans, based on saved flag
    jmp RWDS, lat  side 1     ; Get extended latency input before falling clk
    pull           side 1     ; Wait for write data
    mov X, 6       side 1     ; Set up for normal latency
lat:
    nop            side 0     ; Tick off latency count
    jmp X--, lat   side 1
write:
    set PINDIR, 1  side 0     ; Make RWDS output, bump latency count
    set PINS, 0    side 1;    ; Don't mask PSRAM data, 
    mov PINDIR, ~NULL side 0  ; Make PSRAM data bus pins output
    out PINS, 8    side 1     ; 
    out PINS, 8    side 0
    out PINS, 8    side 1
    out PINS, 8    side 0	
    set PINDIR, 0  side 2     ; Make RWDS input, done with write
    set PINDIR, NULL side 2
    jmp psram

read:
    jmp RWDS, next side 1     ; Wait for latency pin to go high
    jmp read       side 0

next:
    in PINS, 8     side 0     ; Accumulate ph0 data, setup for ph1
    in PINS, 8     side 1     ; Accumulate ph1 data, setup for ph0
    in PINS, 8     side 0     ; Accumulate ph0 data, setup for ph1
    in PINS, 8     side 1     ; Accumulate ph1 data, setup for ph0
    push           side 2     ; Done with transaction
    jmp psram      side 2

Here's something interesting:
https://github.com/Wren6991/PicoDVI.git
There's a sub-project that includes hyperRAM support! Let's give it a shot...
Weird - git clone doesn't pickup all of the software subdirectory, but
downloading a zip does.
  
7-jun-2023:

Experimented with the Wren project (above) - a memtest showed intermittent
failures, even with reduced clock speed. Re-writing code now. Currently,
can read config registers and memory correctly, up to a clock divisor of 5.

8-jun-2023:

Note for the read/write packet format above: could make byte 9/8 (read/write
data length) a word to word align the packet header, as follows:

cfg-wr:
bytes:
0: <7:0> - next pc: 0 to go back to start
1: <7:0> - command length - 1: 3 for CMD/ADR and 16 bit data, so 4 uint16
2: <7:0> - CA 0
3: <7:0> - CA 1
4: <7:0> - CA 2
5: <7:0> - CA 3
6: <7:0> - CA 4
7: <7:0> - CA 5
8-9: cfg write data 0, 1
10-11: padding to fill out last uint32

write:
bytes:
0: <7:0> - next pc: "w_lat" to start write latency timer
1: <7:0> - command length - 1: 2 for CMD/ADR (3 uint16)
2: <7:0> - CA 0
3: <7:0> - CA 1
4: <7:0> - CA 2
5: <7:0> - CA 3
6: <7:0> - CA 4
7: <7:0> - CA 5
8-11: <31:0> - write data length -1 in 16 bit units
12 + len:  data to write to memory

read:
bytes:
0: <7:0> - next pc: "r_lat" to start write latency timer
1: <7:0> - command length - 1: 2 for CMD/ADR (3 uint16)
2: <7:0> - CA 0
3: <7:0> - CA 1
4: <7:0> - CA 2
5: <7:0> - CA 3
6: <7:0> - CA 4
7: <7:0> - CA 5
8-10: <23:0> - read data length -1 in 16 bit units
11: <7:0> - I/O Pad data direction (should be zero for input)

11-jun-2023:

Discovered problem with scheme to change the data direction of the data bus:
it doesn't account for write data in the FIFO getting pushed into the OSR
after a PIO program has completed. The problematic routine is:

public start: ;                  |||
     set PINDIRS, 0       side 0b100       ; Make RWDS pin input
     mov OSR, ~NULL       side 0b100
     out PINDIRS, 32      side 0b100       ; Set CMD/Data pins to output
     pull ifempty         side 0b100       ; Get length and next pc command

So, if the FIFO isn't empty when start is encountered (which might happen
if a PIO routine is executing and the processor pushes in the next PIO
command), then the word in the OSR will be overwritten by the MOV OSR
instruction.

Solutions:
1) Put explicit pull commands into code.
2) Put a byte in the command stream to control data bus direction at
the beginning of a command.
3) Break up into seperate state machines: one to do DDR writes, one for reads.

Thoughts on above:
1) Blows up code - would have to count bytes in inner DDR loops to know when
to do a 32 bit pull...
2) This is what Wren's code does. The thinking was that this caused the
occasional memory errors.
3) Doesn't lend itself to being DMA driven - e.g. would need seperate DMA
channels for reads/writes, and attendant synchronization issues.

I guess (2) seems like the best approach for now. New packet format:

cfg-wr:
bytes:
0: <7:0> - Data Direction: must be 0xff to write CMD/ADR
1: <7:0> - <7:5> - cmd len -1 (3), <4:0> next pc: 0 to go back to start
2: <7:0> - CA 0
3: <7:0> - CA 1
4: <7:0> - CA 2
5: <7:0> - CA 3
6: <7:0> - CA 4
7: <7:0> - CA 5
8-9: padding to align write data
10-11: cfg write data 0, 1 (big endian)

write:
bytes:
0: <7:0> - Data Direction: must be 0xff to write CMD/ADR
1: <7:0> - <7:5> - cmd len -1 (2), <4:0> next pc: "w_lat" to start write lat tmr
2: <7:0> - CA 0
3: <7:0> - CA 1
4: <7:0> - CA 2
5: <7:0> - CA 3
6: <7:0> - CA 4
7: <7:0> - CA 5
8-11: <31:0> - write data length -1 in 16 bit units
12 + len:  data to write to memory

read:
bytes:
0: <7:0> - Data Direction: must be 0xff to write CMD/ADR
1: <7:0> - <7:5> - cmd len -1 (2), <4:0> next pc: "r_lat" to start read lat tmr
2: <7:0> - CA 0
3: <7:0> - CA 1
4: <7:0> - CA 2
5: <7:0> - CA 3
6: <7:0> - CA 4
7: <7:0> - CA 5
8-10: <23:0> - read data length -1 in 16 bit units
11: <7:0> - I/O Pad data direction (should be zero for input)

Seems to work for reg reads/writes. Note, however, that we must
always write 32 bit words, otherwise, the OSR has data left over, and
that causes the next command to start with whatever was left (bad!).

A hack for the CMD writes would be to add a NOP to re-align the OSR.
Or, we could just write the same data twice. The latter should(!) be ok...

Sigh. There's some problem with the output fifo that causes repeated
write commands to go awry. So, let's refactor a bit:

Commands are composed of a command/address phase, followed by (optional)
latency phase, followed by data read or data write phase. Proposal:
make 32 bit FIFO commands that follow this. Must accomodate changing pin dirs.
Could also fix endian issue by re-formatting the cmd/adr phase from big to
little endian.

Once FIFO command is done, it returns to start

Note: all below assumes byte 0 is 31:24 (big endian)

Possible sequences are:
reg read:  idle -> cmd -> r_latency -> read data
reg write: idle -> cmd -> idle 
mem read:  idle -> cmd -> r_latency -> read data
mem write:  idle -> cmd -> w_latency -> write data

So from idle, we need the following:

Word 0:
byte 0: data pin dir
byte 1: cmd len (8 bits) [2 or 3]
byte 2: CA 0
byte 3: CA 1

Word 1:
byte 0: CA 2
byte 1: CA 3
byte 2: CA 4
byte 2: CA 5

<if len == 3>
Word 2:
byte 0: write data 0
byte 1: write data 1
byte 2: write data 2
byte 3: write data 3

Word 2/3:
byte 0: PIO address (8 bits) [idle, latency]
byte 1: padding
byte 2: padding
byte 3: padding

For latency command:
Word 0: 
byte 0: Data direction
byte 1: xfer length
byte 2: xfer pc [idle]
byte 3: next PIO address (8 bits) [w_data, r_data]

For data write:
none

Word 1 to length: data
none

So a register/memory read command looks like (big endian):
word 0: 0xff, <cmd_wr>, CA 0, CA 1
word 1: CA 2, CA 3, CA 4, CA 5
word 2: 0xff, <latency>, long, short
word 3: 0x00, <data_rd>, len h, len l

So a memory write command looks like (big endian):
word 0: 0xff, <cmd_wr>, CA 0, CA 1
word 1: CA 2, CA 3, CA 4, CA 5
word 2: 0xff, <latency>, 0, 0
word 3: 0xff, <data_wr>, len h, len l
word 4 to len: write data

So a register write command looks like (big endian):
word 0: 0xff, <cmd_wr>, CA 0, CA 1
word 1: CA 2, CA 3, CA 4, CA 5
word 2: 0xff, <data_wr>, len h, len l
word 3 to len: write data

12-jun-2023:

Finally fixed PIO code, and enabled the memory test to pass. Above
packet formats did change; will log them here, once I've tuned them
a bit further.

Now attempting to use 3 vs. default 7 latency timing.
Currently PIO latency clock is 11, giving 14 total latency clocks.
So, we have a fixed overhead of 3 clocks, so to get to a total of 6,
2x latency clock should be 3.

Wow! Changing the latency PIO value to 3 actually worked!

Debugged variable latency mode - memtest still passes.

With above changes, now down to 5us per 32 bit read, 4us per 32 bit write.

Leaving long memtest to run, at 2:00 pm. 5:30 pm, pass 164, no errors.

Optimizing packet formats:

So a register/memory read command looks like (big endian):
word 0: 0xff, cmd_len, CA 0, CA 1
word 1: CA 2, CA 3, CA 4, CA 5
word 2: xfer_len, 0x00, 0x00, r_lat

So a memory write command looks like (big endian):
word 0: 0xff, cmd_len, CA 0, CA 1
word 1: CA 2, CA 3, CA 4, CA 5
word 2: xfer_len, 0xff, 0xff, w_lat

So a register write command looks like (big endian):
word 0: 0xff, <cmd_wr>, CA 0, CA 1
word 1: CA 2, CA 3, CA 4, CA 5
word 2: write data (16 bits), write data (16 bits)
word 3: 0x00, 0x00, 0x00, start

Got to pass 310 without errors.

13-jun-2023:

After optimization, at clkdiv = 5:
Op size time    MB/s
rd 1    4 us    
wr 1    3 us
rd 8    5.5 us
wr 8    4.6 us

wd/us * 4 B/1 wrd * 1us/1e-6s * 1e-6MB/1B
1/4 wd/us = 4/4 = 1 MB/s
1/3 wd/us = 4/3 = 1.33 MB/s
8/5.5 wd/us = 8 * 4/5.5 = 5.82 MB/s
8/4.6 wd/us = 8 * 4/4.6 = 6.96 MB/s

This is at stock rp2040 clock. Using Wren's Pico DVI clock settings:
  vreg_set_voltage(VREG_VOLTAGE_1_20);
  sleep_ms(1);
  set_sys_clock_khz(252 * 1000, true);

Minimum clkdiv for passing memtest: 6
Op size time    MB/s
rd 1    1.1 us    
wr 1    0.872 ns
rd 8    2.5 us
wr 8    2.2 us

1/1.1 wd/us = 4/1.1 = 3.63 MB/s
1/0.872 wd/us = 4/0.872 = 4.58 MB/s
8/2.5 wd/us = 8 * 4/2.5 =  12.80 MB/s
8/2.2 wd/us = 8 * 4/2.2 =  14.54 MB/s

Falls well short of the potential 500 MB/s (peak, at 250 MHz) of the PSRAM.

With the above conditions, the cycle time of the RDWS read is: 100ns.
Thus we get a new byte every 50ns, or 20 MB/s

The board is populated with: Windbond W958D8NBYA4I. This is the highest perf
part: 250 MHz.

Decreasing the clk div with clk speed set to 250 shows that the RWDS stops
with a clkdiv of 2. Using default clk speed, clkdiv of 1 works.

CLK  DIV   RWDS
133  1     32ns
250  2     32ns
300  2     26.4ns
325  2     ---

So, it seems like we can send commands at these higher rates, but
can't read the response correctly.

Also note that the I/O level at 300 MHz is observed to be 1.0v. Should be 1.8v.

Experimenting with slew rate and drive strength...
 gpio_set_slew_rate(pin + off, GPIO_SLEW_RATE_SLOW)
 GPIO_SLEW_RATE_FAST GPIO_DRIVE_STRENGTH_8MA

No observed difference.

Experimenting with PSRAM drive strength... Very slight changes observed,
between nominal (34) and maximum drive (19 ohms).

Also saw that 315 MHz was one person's maximum RP2040 clock rate. Tried 325,
no response, but 315 does work, even with vreg not boosted. Leaving at
300 for now, so that the above measurements will be valid going forth.

Reading ID reg 1 to see where data shows up. ID1 is 0x0001, with address
0xc0000001.

Had to reflow the RP2040 pins, after too much probing of DQ0. Discovered
that the vreg boost really is needed after re-connecting the board, as
it wouldn't boot until the vreg was boosted.

Also soldered in W25Q80EWSSIG. Programmed/verified blink just fine (with
modified second stage boot loader), but blink failed to run.
Errors found when attempting to re-flash blinky via SWD:
Warn : target was in unknown state when halt was requested
Info : SWD DPIDR 0x0bc12477
Info : SWD DLPIDR 0x00000001
Error: error executing cortex_m crc algorithm
Error: checksum mismatch - attempting binary compare
Polling target rp2040.core0 failed, trying to reexamine
Info : SWD DPIDR 0x0bc12477
Info : SWD DLPIDR 0x00000001
Info : rp2040.core0: hardware has 4 breakpoints, 2 watchpoints
** Verify Failed **

Searching the config space shows that:
  // Works at 300 RP2040 clk speed, PSRAM latency 5, LATENCY = 5, LAT_SHORT = 2
  clkdiv = 7;

Clocks look clean on the scope as well.
Setting latency to 3 or 4 and LATENCY = 3 results in no RWDS when reading memory.
Setting latency to 3 or 4 and LATENCY = 4 results in one cycle delay RWDS.

Rejiggering the read data routine to sample when clock changes, vs.
one instruction after, allows us to run with clkdiv = 5, and 3 PSRAM latency.
Going further... 4 works, 3 works, 2 fails, with no RWDS. Increasing
LATENCY to 8/5 enables RWDS, but sampling is now mid-clock.

So, apparently the PSRAM has logic that saturates the requested
latency to the lowest acheivable. When experimenting above, 3-6
operate the same as 7. Which, actually, the datasheet indicates:
0000b - 5 Clock Latency @ 133MHz Max Frequency
0001b - 6 Clock Latency @ 166MHz Max Frequency
0010b - 7 Clock Latency @ 200MHz Max Frequency (default)
0010b - 7 Clock Latency @ 250MHz Max Frequency

So, it looks like clkdiv 3 is the max.

300/3 = 100, 100/4 = 25 MHz. => 50 MB/sec. (Peak, of course).

At this freq, PSRAM latency works as expected.

Starting long memtest at 9:20 pm.

14-jun-2023:

Long memtest failed:
Pass:   60 WWWWWWWWWWWWWWWWWWWWWWWWWWWWWWWWRRRRRRRRRRRRRRRRRRRRR                
RAM failure at 01405770 exp/act: 08ff7708 08ff7700                              
08ff7708 25de84e8 5d3c376a a1f24ac3 fde18c57 410a4623 300a7a45 971e5965         
00fbe7bd fd834edc 1f481af1 9ed0abbb ff564369 d0546675 cfc7ef39 763a130a   

Interesting to note that the second read does match the expected value. Perhaps
we need to lower the clock rate just a bit?

Fixing the short RAM test, and playing with buffer sizes, made the error
more prevailent:
Pass:    0 WRWRWRWRWRWR                                                         
RAM failure at 00500384 exp/act: 957c93c6 957c93e7                              
957c93e7 e78e58c5 be4b3f4f edf4c05f ca1c4ea1 3ac1a7e6 c9917ff9 2babb50f         
WR                                                                              
RAM failure at 00600150 exp/act: ec5b32ea ec5b32ca                              
ec5b32ca cac0caca a0a583c7 0b701e8a 1c8a019b cb90b728 73ceebd3 782f4daa         
WRWRWR                                                                          
RAM failure at 00900168 exp/act: 8a8413af 8a841316                              
8a841316 16cf0d38 1a66a70d 1e6b698f 180cb463 5e92f744 0f34985a 1bcd5ee6         
WR                                                                              
RAM failure at 00a003e4 exp/act: 1bc70014 1bc70083                              
1bc70083 837a4337 a884119a 7c5fdce2 7fb83f64 72c4ea8f 1d3ad5e6 00084043

Going to sysclk 250 didn't help. Nor did reverting to default (PSRAM clk: 10 MHz)

It's always the last byte. Is it the write or the read? Let's do a write once,
then read repeatedly test. Definitely read problem:

Pass:    0 WRR                                                                  
RAM failure at 0000028c exp/act: a3a48027 a3a48047                              
a3a48047 47af4718 46ce077f 42152990 03cc1a64 909b9ea5 8aa6af43 b692fc65         
a3a48027 47af4718 46ce077f 42152990 03cc1a64 909b9ea5 8aa6af43 b692fc65         
                                                                                
RAM failure at 000002c0 exp/act: 10e727c6 10e72777                              
10e72777 77ec24ea 9d52b713 bda6ebac 7ab82366 a44f5d8d b0259433 56dd5923         
10e727c6 77ec24ea 9d52b713 bda6ebac 7ab82366 a44f5d8d b0259433 56dd5923         
                                                                                
RAM failure at 00000360 exp/act: 9832deeb 9832debe                              
9832debe be143c9d 09778b9f f886e43e a427f1ff 191fa294 44e7d273 6b9449c8         
9832deeb be143c9d 09778b9f f886e43e a427f1ff 191fa294 44e7d273 6b9449c8         
                                                                                
RAM failure at 000003c0 exp/act: f9b837a8 f9b83716                              
f9b83716 16e449cf 64612202 44090053 e4691813 2a086f67 db770e36 6c8bbeaf         
f9b837a8 16e44964 64612202 44090053 e4691813 2a086f67 db770e36 6c8bbeaf

Second read shows that the bits were properly written. So, the last
byte is marginal for some reason...

Experimenting with burst size shows that for an 8 word (32 byte, 16 short),
errors present. 1, 2, 4 word bursts do not. Going to 4, increasing sysclk...
300 MHz works. Testing again at 8 fails, as does 5, 6, 7.

15-jun-2023:

Test failed yesterday:
Pass: 2778423 WRWRWRWRWRWRWRWRWRWRWRWRWRWRWRWRWRWRWRWRWRWRWRWRWRWR              
RAM failure at 019003bc exp/act: f7089b01 f7009b01                              
f7009b01 00084043 0804ac24 2d8c3e65 e259a3e6 12841675 99153451 cc7e785f         
f7009b01 00084043 0804ac24 2d8c3e65 e259a3e6 12841675 99153451 cc7e785f         
WRWRWRWRWRWR

Interesting that it was the 3rd byte this time.

Looks like falling edge sampling doesn't fully work.

Next, let's try using all of the available clocks, via clkdiv = 1. If we
use three instructions per phase, that'll allow us to move the sample
period a bit. So, 50 MHz PSRAM clk, or 100 MB/s peak.

So:
Entered with clock high for 2 ticks, 1 away from falling edge
public r_data:
     in PINS, 8           side 0b000       ; Get ph 0 data
     nop                  side 0b010   [1] ; Setup for ph 1
     in PINS, 8           side 0b010       ; Get ph 1 data
     jmp X--, r_data      side 0b000   [1] ; Setup for ph 0

So, further experimentation shows that pushing the in as far from
the leading clock edge is the most successful. Hold time must not
be the issue here.

Currently running long memtest with 300 MHz sysclk, divisor = 3, so
100 MHz effective, with each phase using 3 instructions, so 33 MB/s.

Fails with 200 MHz sysclk, div = 2, which should yeild the same 100 MHz
instruction rate. Weird...

public r_lat:
     nop                  side 0b000 [2]
lat_cnt:
     nop                  side 0b010 [2]
     jmp Y--, lat_cnt     side 0b000 [2]
     nop                  side 0b010
public r_data:
     nop                  side 0b010 
     in PINS, 8           side 0b011 ; Get data
     nop                  side 0b000    ; CA phase 0 
     nop                  side 0b000    ; CA phase 0 
     in PINS, 8           side 0b001  
     jmp X--, r_data      side 0b010    ; CA phase 1 write
     jmp start            side 0b000

Should try with each phase = 4 instructions, divisor = 2, sys

16-jun-2023:

Test ran overnight. Also thought of why it fails when running at 200 MHz/
div = 2: the processor is running 1/3 slower every time it gets a clock tick.
This means the time between assertion of clock and capture of data is shorter.

Re-wrote code to use more delay slots. Still can't get above 33 MB/s reliably.
Noted that a delay between CS assertion and command output is needed.

Trying to get 300 MHz sysclk with 6 ticks/phase to work. Experimented
with latency, but no difference. Seems like there's phase delay somewhere:

5 lat PSRAM, PIO LATENCY = 5/2 
id 0: 000e860e                                                                  
id 1: 86000100                                                                  
cfg 0: 01ff00ff                                                                 
cfg 1: 00ffddff                                                                 
00084043 0804ac24 2d8c3e65 e259a3e6 12841675 99153451 cc7e785f 6dc6a546         
01000840 430804ac 242d8c3e 65e259a3 e6128416 75991534 51cc7e78 5f6dc6a5         
a9000840 430804ac 242d8c3e 65e259a3 e6128416 75991534 51cc7e78 5f6dc6a5

4 lat PSRAM, PIO LATENCY = 4/1 
id 0: f00e860e                                                                  
id 1: 86000100                                                                  
cfg 0: 01fff0ff                                                                 
cfg 1: f0ffddff                                                                 
00084043 0804ac24 2d8c3e65 e259a3e6 12841675 99153451 cc7e785f 6dc6a546         
01000840 430804ac 242d8c3e 65e259a3 e6128416 75991534 51cc7e78 5f6dc6a5         
a9000840 430804ac 242d8c3e 65e259a3 e6128416 75991534 51cc7e78 5f6dc6a5

3 lat PSRAM, PIO LATENCY = 3/0 
id 0: e00e860e                                                                  
id 1: 86000100                                                                  
cfg 0: 01ffe0ff                                                                 
cfg 1: e0ffddff                                                                 
00084043 0804ac24 2d8c3e65 e259a3e6 12841675 99153451 cc7e785f 6dc6a546         
01000840 430804ac 242d8c3e 65e259a3 e6128416 75991534 51cc7e78 5f6dc6a5         
a9000840 430804ac 242d8c3e 65e259a3 e6128416 75991534 51cc7e78 5f6dc6a5         

In the above reading the written data portion, we see that the read
bytes are delayed by one byte from the written. Test with GPIO writes:

From GPIO psram_test:
Did not enter power down mode. CFG_0 act/exp: 8f2f 0000                         
ID0: 00000e86                                                                   
ID1: 00000001                                                                   
CFG0: 00008f2f                                                                  
CFG1: 0000ffc1                                                                  
Original CFG0: 0x8f2f                                                           
Writing to CFG0: 0xf0e0                                                         
Updated  CFG0: 0xffe0                                                           
00084042 08008c02 2998d882 6398b906 e3b0281a 30d07323 e8358359 538f61b6         
00084042 08008c02 2998d882 6398b906 e3b0281a 30d07323 e8358359 538f61b6         
00084042 08008c02 2998d882 6398b906 e3b0281a 30d07323 e8358359 538f61b6

From psram_wren:
id 0: e00e860e                                                                  
id 1: 86000100                                                                  
cfg 0: 01ffe0ff                                                                 
cfg 1: e0ffc1ff                                                                 
00084043 0804ac24 2d8c3e65 e259a3e6 12841675 99153451 cc7e785f 6dc6a546         
01000840 430804ac 242d8c3e 65e259a3 e6128416 75991534 51cc7e78 5f6dc6a5         
a9000840 430804ac 242d8c3e 65e259a3 e6128416 75991534 51cc7e78 5f6dc6a5

So read problem, then.
PIO or PSRAM? Try returning a constant. Seems OK:
    set Y, 15             side 0b01 [3]
public r_data:
;     nop                  side 0b01 
     set pins, 2          side 0b01 
;     in PINS, 8           side 0b01        ; CA phase 0 
     in Y, 8           side 0b01        ; CA phase 0 
;     nop                  side 0b00 [2]    ; Setup for phase 1
     set pins, 0          side 0b00 [4] 
;     in PINS, 8           side 0b00        ; CA phase 1
     in x, 8           side 0b00        ; CA phase 0 
     jmp X--, r_data      side 0b01 [3]    ; Continue until all data captured 
     jmp start            side 0b00

id 0: 0f010f00                                                                  
id 1: 0f010f00                                                                  
cfg 0: 0f010f00                                                                 
cfg 1: 0f010f00

Also, passes at default clk freq, and 200 MHz. At 250 MHz, we see:

id 0: 08860e86                                                                  
id 1: 00010100                                                                  
cfg 0: 01e0e0e1                                                                 
cfg 1: e0c1c1c1                                                                 
00084043 0804ac24 2d8c3e65 e259a3e6 12841675 99153451 cc7e785f 6dc6a546         
005f1ddd d17806d0 00f34b22 0ad20a1a 081418c3 0b898166 20c6a655 49aa08a4         
475f1ddd d17806d0 00f34b22 0ad20a1a 081418c3 0b898166 20c6a655 49aa08a4
Pass:    0 WR                                                                   
RAM failure at 00000000 exp/act: 00084043 01084042                              
01084042 09040424 2c8c0c64 625823e6 12840474 19153450 417e785e 6dc6a446         
a1084042 09040424 2c8c0c65 625823e6 12840474 19153450 407e785e 6dc6a446

So, I think we're seeing the limitations of overclocking: the input
pads can't keep up with the incoming data past 33 MHz or so. I wonder
if I threw away the first pad read?

Verified that it's a read problem, by writing memory with PIO (big endian),
then reading back with GPIO (byte swapping):
Reading cfg 0: b6ffe0ff                                                         
Writing f0e0 to CR0 register                                                    
Reading cfg 0: e0ffe0ff                                                         
id 0: e00e860e                                                                  
id 1: 86000100                                                                  
cfg 0: 01ffe0ff                                                                 
cfg 1: e0ffc1ff                                                                 
00084042 08008c02 2998d882 6398b906 e3b0281a 30d07323 e8358359 538f61b6         
01000840 4208008c 022998d8 826398b9 06e3b028 1a30d073 23e83583 59538f61         
b6000840 4208008c 022998d8 826398b9 06e3b028 1a30d073 23e83583 59538f61         
                                                                                
****Setup done                                                                  
Did not enter power down mode. CFG_0 act/exp: 8f2f 0000                         
ID0: 00000e86                                                                   
ID1: 00000001                                                                   
CFG0: 00008f2f                                                                  
CFG1: 0000ffc1                                                                  
Original CFG0: 0x8f2f                                                           
Writing to CFG0: 0xf0e0                                                         
Updated  CFG0: 0xffe0                                                           
00084042 08008c02 2998d882 6398b906 e3b0281a 30d07323 e8358359 538f61b6         
00084042 08008c02 2998d882 6398b906 e3b0281a 30d07323 e8358359 538f61b6         
00084042 08008c02 2998d882 6398b906 e3b0281a 30d07323 e8358359 538f61b6

Perhaps going to the last edge sampling will help? As done above.
Certainly better:

id 0: 0e860e86                                                                  
id 1: 00010001                                                                  
cfg 0: ffe0ffe0                                                                 
cfg 1: ffc1ffc1                                                                 
00084042 08008c02 2998d882 6398b906 e3b0281a 30d07323 e8358359 538f61b6         
00084042 08008c02 2998d882 6398b906 e3b0281a 30d07323 e8358359 538f61b6         
00084042 08008c02 2998d882 6398b906 e3b0281a 30d07323 e8358359 538f61b6         
Pass:    0 WR                                                                   
RAM failure at 000003d8 exp/act: e46ea3e9 e46ea332                              
e46ea332 3260e7e0 00084042 08008c02 2998d882 6398b906 e3b0281a 30d07323         
e46ea3e9 3260e7e0 00084042 08008c02 2998d882 6398b906 e3b0281a 30d07323         
WRWRWR                                                                          
RAM failure at 003002b4 exp/act: 869c6985 869c697e                              
869c697e 7e354633 089ae40a 00084042 08008c02 2998d882 6398b906 e3b0281a         
869c6985 7e354633 089ae40a 00084042 08008c02 2998d882 6398b906 e3b0281a         
WRWR                                                                            
RAM failure at 00500290 exp/act: ae2f2ba4 ae2f2b20                              
ae2f2b20 202a4f29 5024220e 58d48fbc 00084042 08008c02 2998d882 6398b906         
ae2f2ba4 202a4f29 5024220e 58d48fbc 00084042 08008c02 2998d882 6398b906

Now fails on last byte. See if we can move last byte sampling. Ok, this
shouldn't work, but marginally does:

     nop                  side 0b01 [5]

public r_data:
     in PINS, 8           side 0b00 [4]    ; CA phase 0 
     in PINS, 8           side 0b00        ; CA phase 1
     jmp X--, r_data      side 0b01 [4]    ; Continue until all data captured 
     jmp start            side 0b00

Increasing the 4 to 5 enables passing short memtest. Clock is 23 MHz,
according to the scope. Pushing sysclk to 315 fails. Starting long
memtest @12:30 pm with 300 MHz... Failed at pass 11.

With the following code, gets 130 passes with long memtest:
;     nop                  side 0b01 [5]
; Trigger for scope
;     set pins 2           side 0b01
;     nop                  side 0b01 [3]
;     set pins 0           side 0b01
public r_data:
     set pins 2           side 0b01
     nop                  side 0b01 [4]
     set pins 0           side 0b01
     in PINS, 8           side 0b00 [5]    ; CA phase 0 
     in PINS, 8           side 0b00        ; CA phase 1
     jmp X--, r_data      side 0b00        ; Continue until all data captured 
     jmp start            side 0b00

Clock is 20 MHz, according to scope.

With previous code, changing 4 to 6, clk rate 21.37 MHz, long memtest running...
200 passes without error.

Optimizing...
public r_lat:
     nop                  side 0b00 [5]
lat_cnt:
     nop                  side 0b01 [5]
     jmp Y--, lat_cnt     side 0b00 [5]

;     nop                  side 0b01 [5]
; Trigger for scope
     set pins 2           side 0b01
     nop                  side 0b01 [3]
     set pins 0           side 0b01
     nop                  side 0b00 
public r_data:
     in PINS, 8           side 0b00 [5]    ; CA phase 0 
     in PINS, 8           side 0b01 [6]    ; CA phase 1
     jmp X--, r_data      side 0b00        ; Continue until all data captured 
     jmp start            side 0b00

17-jun-2023:

Long memory test ran overnight: pass 6094 as of 6:57 am.

PSRAM clock is 21.37 MHz, measured. So 42 MB/s peak.

Tried moving latency loop counter into main cmd code, but this isn't a
good idea: it'll cause extra writes when doing config register writes.

Ok, so ran short mem test, now fails:

cfg 1: ffc1ffc1                                                                 
00084042 08008c02 2998d882 6398b906 e3b0281a 30d07323 e8358359 538f61b6         
00084042 08008c02 2998d882 6398b906 e3b0281a 30d07323 e8358359 538f61b6         
00084042 08008c02 2998d882 6398b906 e3b0281a 30d07323 e8358359 538f61b6         
Pass:    0 WRWR                                                                 
RAM failure at 00100278 exp/act: 03895500 0389550c                              
0389550c 0c017314 00084042 08008c02 2998d882 6398b906 e3b0281a 30d07323         
03895500 0c017314 00084042 08008c02 2998d882 6398b906 e3b0281a 30d07323         
WRWRWRWR                                                                        
RAM failure at 00500274 exp/act: 38ea6478 38ea64f8                              
38ea64f8 f8ce970a 6fd781bd 00084042 08008c02 2998d882 6398b906 e3b0281a         
38ea6478 f8ce970a 6fd781bd 00084042 08008c02 2998d882 6398b906 e3b0281a         
WRWR

Reverting back to earlier:

public r_data:
     in PINS, 8           side 0b00 [5]    ; CA phase 0 
     in PINS, 8           side 0b00        ; CA phase 1
     jmp X--, r_data      side 0b01 [6]    ; Continue until all data captured 
     jmp start            side 0b10

enables passing short memory test once again. Mostly: failed at pass 45001.

Pass: 45001 WRWRWRWRWRWRWRWRWRWRWRWRWRWRWRWRWR                                  
RAM failure at 01000060 exp/act: 08fff788 08fff780                              
08fff780 37df1d6f 5a207d96 e7c07cbf e2aafa14 00ecb8e0 69ee9018 c654702e         
08fff780 37df1d6f 5a207d96 e7c07cbf e2aafa14 00ecb8e0 69ee9018 c654702e

Increased delay times by one tick, re-running. PSRAM clk is now: 18.66 MHz.

Looking at the above, perhaps this was a write failure?

Memtest is up to pass 1023000.

18-Jun-2023:

Memory test is up to 3611300. Too bad it's only 37 MB/s. 

750 ns between word reads.

Managed to boost speed just a tich: sysclk is now 21.2 MHz (scope).
Code:

; Trigger for scope
     set pins 2           side 0b00 [6]    ; Burn a latency clock
     set pins 0           side 0b01 [5]

public r_data:
     in PINS, 8           side 0b01 [0]    ; CA phase 0 
     nop                  side 0b00 [5]    ; Burn a latency clock
     in PINS, 8           side 0b00 [0]       ; CA phase 1
     jmp X--, r_data      side 0b01 [5]    ; Continue until all data captured 
     jmp start            side 0b10

The speed up is because we don't change the clock during the IN instruction.

So, now we get 42 MB/s.

Nope, fails at pass 45001 consistently:

d 0: 0e860e86                                          
id 1: 00010001                                          
cfg 0: ffe0ffe0                                         
cfg 1: ffc1ffc1                                         
00084042 08008c02 2998d882 6398b906 e3b0281a 30d07323 e8358359 538f61b6
00084042 08008c02 2998d882 6398b906 e3b0281a 30d07323 e8358359 538f61b6
00084042 08008c02 2998d882 6398b906 e3b0281a 30d07323 e8358359 538f61b6
Pass: 45000 WRWRWRWRWRWRWRWRWRWRWRWRWRWRWRWRWRWRWRWRWRWRWRWRWRWRWRWRWRWRWRWR
Pass: 45001 WRWRWRWRWRWRWRWRWRWRWRWRWRWRWRWRWR
RAM failure at 01000060 exp/act: 08fff788 08fff780
08fff780 37df1d6f 5a207d96 e7c07cbf e2aafa14 00ecb8e0 69ee9018 c654702e
08fff780 37df1d6f 5a207d96 e7c07cbf e2aafa14 00ecb8e0 69ee9018 c654702e
WRWRWRWRWRWRWRWRWRWRWRWRWRWRWRSet sysclk to 300 MHz
pad bank0 voltage select addr/data: 4001c000 00000001
Loading program
Initialising state machine
Setting clock divisor to 1
Reading cfg 0: ffe0ffe0
Writing f0e0 to CR0 register
Reading cfg 0: ffe0ffe0
id 0: 0e860e86
id 1: 00010001
cfg 0: ffe0ffe0
cfg 1: ffc1ffc1
00084042 08008c02 2998d882 6398b906 e3b0281a 30d07323 e8358359 538f61b6
00084042 08008c02 2998d882 6398b906 e3b0281a 30d07323 e8358359 538f61b6
00084042 08008c02 2998d882 6398b906 e3b0281a 30d07323 e8358359 538f61b6
Pass: 45000 WRWRWRWRWRWRWRWRWRWRWRWRWRWRWRWRWRWRWRWRWRWRWRWRWRWRWRWRWRWRWRWR
Pass: 45001 WRWRWRWRWRWRWRWRWRWRWRWRWRWRWRWRWR
RAM failure at 01000060 exp/act: 08fff788 08fff780
08fff780 37df1d6f 5a207d96 e7c07cbf e2aafa14 00ecb8e0 69ee9018 c654702e
08fff780 37df1d6f 5a207d96 e7c07cbf e2aafa14 00ecb8e0 69ee9018 c654702e
WRWRWRWRWRWRWRWRWRWRWRWRWRWRWR

(Set the pass to 45000 in main.c)

Sigh. See note from 17-jun: same failure at 45001, with code that
changes clk during IN instruction, so above is simply wrong. There must be
some timing path we're hitting with this particular sequence of read data.

So, this works:
     in PINS, 8           side 0b01 [0]    ; CA phase 0 
     nop                  side 0b00 [6]    ; Burn a latency clock
     in PINS, 8           side 0b00 [0]       ; CA phase 1
     jmp X--, r_data      side 0b01 [5]    ; Continue until all data captured 
     jmp start            side 0b10

but this doesn't:
     in PINS, 8           side 0b01 [0]    ; CA phase 0 
     nop                  side 0b00 [5]    ; Burn a latency clock
     in PINS, 8           side 0b00 [0]       ; CA phase 1
     jmp X--, r_data      side 0b01 [6]    ; Continue until all data captured 
     jmp start            side 0b10

This also works, at 21 MHz sysclk:
     in PINS, 8           side 0b00 [6]    ; CA phase 0 
     in PINS, 8           side 0b00 [0]       ; CA phase 1
     jmp X--, r_data      side 0b01 [5]    ; Continue until all data captured 
     jmp start            side 0b10

19-jun-2023:

Overnight test failed:
Pass: 1985416 WRWRWRWRWRWRWRWRWRWRWRWRWRWRWRWR
RAM failure at 00f0021c exp/act: 7ff708f7 7ff700f7
7ff700f7 43dd57e3 cd092d13 fdcc1186 80612178 2d8018bf fc6a1174 76dd0496
7ff708f7 43dd57e3 cd092d13 fdcc1186 80612178 2d8018bf fc6a1174 76dd0496
WRWRWRWRWRWRWRWRWRWRWRWRWRWRWRWR

Second byte failure... and it's repeatable:

d 0: 0e860e86
id 1: 00010001
cfg 0: ffe0ffe0
cfg 1: ffc1ffc1
00084042 08008c02 2998d882 6398b906 e3b0281a 30d07323 e8358359 538f61b6
00084042 08008c02 2998d882 6398b906 e3b0281a 30d07323 e8358359 538f61b6
00084042 08008c02 2998d882 6398b906 e3b0281a 30d07323 e8358359 538f61b6
Pass: 1985400 WRWRWRWRWRWRWRWRWRWRWRWRWRWRWRWRWRWRWRWRWRWRWRWRWRWRWRWRWRWRWRWR
Pass: 1985401 WRWRWRWRWRWRWRWRWRWRWRWRWRWRWRWRWRWRWRWRWRWRWRWRWRWRWRWRWRWRWRWR
Pass: 1985402 WRWRWRWRWRWRWRWRWRWRWRWRWRWRWRWRWRWRWRWRWRWRWRWRWRWRWRWRWRWRWRWR
Pass: 1985403 WRWRWRWRWRWRWRWRWRWRWRWRWRWRWRWRWRWRWRWRWRWRWRWRWRWRWRWRWRWRWRWR
Pass: 1985404 WRWRWRWRWRWRWRWRWRWRWRWRWRWRWRWRWRWRWRWRWRWRWRWRWRWRWRWRWRWRWRWR
Pass: 1985405 WRWRWRWRWRWRWRWRWRWRWRWRWRWRWRWRWRWRWRWRWRWRWRWRWRWRWRWRWRWRWRWR
Pass: 1985406 WRWRWRWRWRWRWRWRWRWRWRWRWRWRWRWRWRWRWRWRWRWRWRWRWRWRWRWRWRWRWRWR
Pass: 1985407 WRWRWRWRWRWRWRWRWRWRWRWRWRWRWRWRWRWRWRWRWRWRWRWRWRWRWRWRWRWRWRWR
Pass: 1985408 WRWRWRWRWRWRWRWRWRWRWRWRWRWRWRWRWRWRWRWRWRWRWRWRWRWRWRWRWRWRWRWR
Pass: 1985409 WRWRWRWRWRWRWRWRWRWRWRWRWRWRWRWRWRWRWRWRWRWRWRWRWRWRWRWRWRWRWRWR
Pass: 1985410 WRWRWRWRWRWRWRWRWRWRWRWRWRWRWRWRWRWRWRWRWRWRWRWRWRWRWRWRWRWRWRWR
Pass: 1985411 WRWRWRWRWRWRWRWRWRWRWRWRWRWRWRWRWRWRWRWRWRWRWRWRWRWRWRWRWRWRWRWR
Pass: 1985412 WRWRWRWRWRWRWRWRWRWRWRWRWRWRWRWRWRWRWRWRWRWRWRWRWRWRWRWRWRWRWRWR
Pass: 1985413 WRWRWRWRWRWRWRWRWRWRWRWRWRWRWRWRWRWRWRWRWRWRWRWRWRWRWRWRWRWRWRWR
Pass: 1985414 WRWRWRWRWRWRWRWRWRWRWRWRWRWRWRWRWRWRWRWRWRWRWRWRWRWRWRWRWRWRWRWR
Pass: 1985415 WRWRWRWRWRWRWRWRWRWRWRWRWRWRWRWRWRWRWRWRWRWRWRWRWRWRWRWRWRWRWRWR
Pass: 1985416 WRWRWRWRWRWRWRWRWRWRWRWRWRWRWRWR

Set pass to 1985415:

RAM failure at 00f0021c exp/act: 7ff708f7 7ff700f7
7ff700f7 43dd57e3 cd092d13 fdcc1186 80612178 2d8018bf fc6a1174 76dd0496
7ff700f7 43dd57e3 cd092d13 fdcc1186 80612178 2d8018bf fc6a1174 76dd0496
fg 1: ffc1ffc1
00084042 08008c02 2998d882 6398b906 e3b0281a 30d07323 e8358359 538f61b6
00084042 08008c02 2998d882 6398b906 e3b0281a 30d07323 e8358359 538f61b6
00084042 08008c02 2998d882 6398b906 e3b0281a 30d07323 e8358359 538f61b6
Pass: 1985415 WRWRWRWRWRWRWRWRWRWRWRWRWRWRWRWRWRWRWRWRWRWRWRWRWRWRWRWRWRWRWRWR
Pass: 1985416 WRWRWRWRWRWRWRWRWRWRWRWRWRWRWRWR
RAM failure at 00f0021c exp/act: 7ff708f7 7ff700f7
7ff700f7 43dd57e3 cd092d13 fdcc1186 80612178 2d8018bf fc6a1174 76dd0496
7ff700f7 43dd57e3 cd092d13 fdcc1186 80612178 2d8018bf fc6a1174 76dd0496
WRWRWRWRWRWRWRWRWRWRWRWRWRWRWRWR

And another one:
00084042 08008c02 2998d882 6398b906 e3b0281a 30d07323 e8358359 538f61b6
00084042 08008c02 2998d882 6398b906 e3b0281a 30d07323 e8358359 538f61b6
00084042 08008c02 2998d882 6398b906 e3b0281a 30d07323 e8358359 538f61b6
Pass: 2001799 WRWRWRWRWRWRWRWRWRWRWRWRWRWRWRWRWRWRWRWRWRWRWRWRWRWRWRWRWRWRWRWR
Pass: 2001800 WRWRWRWRWRWRWRWRWRWRWRWRWRWRWR
RAM failure at 00e0021c exp/act: 7ff708f7 7ff700f7
7ff700f7 43dd57e3 cd092d13 fdcc1186 80612178 2d8018bf fc6a1174 76dd0496
7ff700f7 43dd57e3 cd092d13 fdcc1186 80612178 2d8018bf fc6a1174 76dd0496

More:
Pass: 2009992 WRWRWRWRWRWRWRWRWRWRWRWRWRWR
RAM failure at 00d0021c exp/act: 7ff708f7 7ff700f7
7ff700f7 43dd57e3 cd092d13 fdcc1186 80612178 2d8018bf fc6a1174 76dd0496
7ff700f7 43dd57e3 cd092d13 fdcc1186 80612178 2d8018bf fc6a1174 76dd0496

So:
1985416: RAM failure at 00f0021c exp/act: 7ff708f7 7ff700f7
2001800: RAM failure at 00e0021c exp/act: 7ff708f7 7ff700f7

Lowering clock speed to 266 enable memtest to pass. 280 also works. 290 won't
boot.

So, attempting to restructure for shorter code size. Thought: try to make
a subroutine threaded engine.
Use Y as count/next PC

start:
     set PINDIRS, 2       side 0b10 [3]
     out PINDIRS, 8       side 0b00       ; Set CMD/Data pins direction
     out Y, 16            side 0b00       ; Get long lat next PC
     jmp PIN, next        side 0b00       ; Skip if RWDS set for max latency
     out Y, 8             side 0b00       ; Get short lat next PC
     out NULL, 8          side 0b00       ; Pop off extra bits
next:
     out X, 8             side 0b00       ; Get CMD/Data word count
     jmp ddr              side 0b00       ; Do command phase
;8

public reg_w:
     out NULL, 16         side 0b00       ; Dump last 16 bits of command
     jmp start                            ;   since we only write 16 bits
;+2 = 10

public write_l:
     set Y, write_lat_long
     jmp lat
;+2 = 12

public write_s:
     set Y, write_lat_short
     jmp lat
;+2 = 14

ddr:
     out PINS, 8          side 0b00 [4]   ; Setup write of cmd/adr
     nop                  side 0b01       ; CA phase 0 write
     out PINS, 8          side 0b01 [4] 
     jmp X--, adr         side 0b00       ; CA phase 1 write
     jmp Y                side 0b01 [4]   ; Jump to command [start, r/w_lat]
;+5 = 19

public read_l:
     set Y, read_lat_long
     jmp lat
;+2 = 21

public read_s:
     set Y, read_lat_short
;+1 = 22

public lat:
     out PINDIRS, 8       side 0b00       ; Set CMD/Data pins direction
lat_cnt:
     nop                  side 0b00 [5]   ; Wait for latency to expire
     jmp Y--, lat_cnt     side 0b01 [5]
     out X, 16            side 0b00       ; Get transfer word count
     out PC, 8            side 0b00       ; Get next PC
;+5 = 27

public r_data:
     in PINS, 8           side 0b00 [6]    ; CA phase 0 
     in PINS, 8           side 0b00        ; CA phase 1
     jmp X--, r_data      side 0b01 [5]    ; Continue until all data captured 
     jmp start            side 0b10
;+4 = 31

Current count is 27. Could maybe eliminate the reg_w: -2 for 29

What about using the pop pc stuff above to directly get to the Y lat value?
     out Y, 16            side 0b00       ; Get long lat
     jmp PIN, next        side 0b00       ; Skip if RWDS set for max latency
     out Y, 8             side 0b00       ; Get short lat
     out NULL, 8          side 0b00       ; Pop off extra bits

That would save one instruction from the original: 26 instructions.
Can't use it with the above, since we need to serve as the nextPC reg.

orig:
     out PINDIRS, 8       side 0b00       ; Set CMD/Data pins direction
     set Y, LATENCY       side 0b00       ; Assume maximum latency     
     jmp PIN, setup       side 0b00       ; Skip if RWDS set for max latency
     set Y, LAT_SHORT     side 0b00       ; Short latency

setup:
     out X, 8             side 0b00       ; Set length for CMD/ADR phase

proposed:
     out PINDIRS, 8       side 0b00       ; Set CMD/Data pins direction
     out Y, 5             side 0b00       ; Assume maximum latency     
     jmp PIN, setup       side 0b00       ; Skip if RWDS set for max latency
     out Y, 2             side 0b00       ; Short latency
     out Y, 3

setup:
     out X, 3             side 0b00       ; Set length for CMD/ADR phase (2 or 4)

so: 2 bits for short latency, 3 for long. Currently: 0, 1 and 3, 4. Just fits.
For a one instruction slot savings. Perhaps we'll keep this in reserve for now.
Time to bike!

20-jun-2023

Soldered on PSRAM onto second board. Had interesting time trying to get it
to boot afterwards: it would show up on the Windows file manager when plugged
in, but upon replugging, wouldn't. Downloaded blinky with scope loop, and
observed that the 500 kHz waveform wasn't. Decided to replace crystal, and
that solved the booting problem. Also replaced the GD flash device with a
new one, and now flashing blinky actually works! Have to test further - I
manually flashed/verified via OpenOCD when debugging the crystal problem.

Yay! Second board passes mem_test! Had to remove PSRAM, manually "re-ball"
(by which I mean "run the soldering iron over the chip") and solder down.
Turns out that there was a solder short between two balls.

Debugging the flash issue:
openocd flash commands
flash write_image <full path to elf file>
flash verify_image <full path to elf file>
flash md{b,h,w} count - display bytes/halfwords/words from flash

Flash was working, now it's not. I wonder if the reflow process popped it?

21-jun-2023:

Memory test still running on second board.

Replaced flash on first board, was able to copy flash.ufl and reboot into it
successfully. Also shows up when probing with picotool on Linux. Had to switch
USB ports, though.

Ok, this is weird - can reload blink and get it to show up /dev/ttyACM0, but
not mem_test. All with picotool. At least flash appears to work, though.

Time to do gardening...trimmed three shrubs, prepped more bird blockers for
later installation.

Replaced flash on second board, now flashes via drag and drop on the HW lab
PC. Attempting to reprogram on the SW lab RPI0: devel0. Was able to re-flash
blink, and mem_test. Mem_test fails to execute, however. Perhaps the flash
doesn't work when sysclk is 280 MHz? Trying default clkfreq...Yes, mem_test
is now running. So, there's a CMakefile directive to slow down flash speed...

target_compile_definitions(slower_boot2 PRIVATE PICO_FLASH_SPI_CLKDIV=4)

The PICO_FLASH_SPI_CLKDIV is used by "boot stage 2" which is not actually part of your TARGET (from cmake's point of view)

Create yourself your own "board header" - basically just set that define, then include your regular board header: e.g.

Code: Select all

// myboard.h

// setting first overrides the value in the default header
#define PICO_FLASH_SPI_CLKDIV 4

// pick up the rest of the settings
#include "boards/pico.h"

You can place that wherever, and pass a PICO_BOARD_HEADER_DIRS to cmake (or define at the top of your CMakeLists.txt), then do -DPICO_BOARD=myboard

// end web-capture

So, since we have to modify the second stage boot loader to change the I/O
voltage setting, we might as well change the SPI clock freq there as well.

Using blink (the modified boot loader version) as template.

While attempting to get blink to work at elevated clock rates, bricked the
flash. It programs and verifies fine, but fails to boot. Reading the GD25LQ64E
datasheet closely reveals that there's an non-volatile enable bit that
controls the QSPI mode:

QE bit
The Quad Enable (QE) bit is a non-volatile Read/Write bit in the Status
Register that allows Quad operation. When the QE bit is set to 0 (Default)
the WP# pin and HOLD# pin are enable. When the QE pin is set to 1, the
Quad IO2 and IO3 pins are enabled. (It is best to set the QE bit to 0 to
avoid short issues if the WP# or HOLD# pin is tied directly to the power
supply or ground.)

Further:
The GD25LQ64E supports Quad Peripheral Interface (QPI) operations only when
the device is switched from Standard/Dual/Quad SPI mode to QPI mode using the
“Enable the QPI (38H)” command. The QPI mode utilizes all four IO
pins to input the command code. Standard/Dual/Quad SPI mode and QPI mode are
exclusive. Only one mode can be active at any given times. “Enable the QPI
(38H)” and “Disable the QPI (FFH)” commands are used to switch between these two
modes. Upon power-up and after software reset using “Reset (99H)” command,
the default state of the device is Standard/Dual/Quad SPI mode. The QPI
commands require the non-volatile Quad Enable bit (QE) in Status Register set
to 1.

So my guess is that QE has been written to zero. Need to find code to
read flash status bits...

From sdk flash.c:
// Standard RUID instruction: 4Bh command prefix, 32 dummy bits, 64 data bits.
#define FLASH_RUID_CMD 0x4b
#define FLASH_RUID_DUMMY_BYTES 4
#define FLASH_RUID_DATA_BYTES 8
#define FLASH_RUID_TOTAL_BYTES (1 + FLASH_RUID_DUMMY_BYTES + FLASH_RUID_DATA_BYTES)

// Use standard RUID command to get a unique identifier for the flash (and
// hence the board)

static_assert(FLASH_UNIQUE_ID_SIZE_BYTES == FLASH_RUID_DATA_BYTES, "");

void flash_get_unique_id(uint8_t *id_out) {
#if PICO_NO_FLASH
    __unused uint8_t *ignore = id_out;
    panic_unsupported();
#else
    uint8_t txbuf[FLASH_RUID_TOTAL_BYTES] = {0};
    uint8_t rxbuf[FLASH_RUID_TOTAL_BYTES] = {0};
    txbuf[0] = FLASH_RUID_CMD;
    flash_do_cmd(txbuf, rxbuf, FLASH_RUID_TOTAL_BYTES);
    for (int i = 0; i < FLASH_RUID_DATA_BYTES; i++)
        id_out[i] = rxbuf[i + 1 + FLASH_RUID_DUMMY_BYTES];
#endif
}

So we should be able to use the flash_do_cmd to fetch the status register.
From the datasheet:
Command Name Byte 1    Byte 2   Byte 3   Byte 4  Byte 5 Byte 6 Byte 7 Byte 8
Read Status Register-1  05H     (S7-S0)  (cont.)
Read Status Register-2  35H     (S15-S8) (cont.)
Read Unique ID          4BH     00H      00H     00H    dummy  UDD7-0 (cont.)

For the command of Read, Fast Read, Read Status Register or Release
from Deep Power-Down, and Read Device ID, the shifted-in command sequence
is followed by a data-out sequence. All read instruction can be
completed after any bit of the data-out sequence is being shifted out,
and then CS# must be driven high to return to deselected status.

So, using the get_unique as a template:

// Standard RUID instruction: 4Bh command prefix, 32 dummy bits, 64 data bits.
// Status instruction: 35h command prefix, 16 data bits
#define FLASH_READ_STATUS_CMD 0x35
#define FLASH_STATUS_DUMMY_BYTES 0
#define FLASH_STATUS_DATA_BYTES 2
#define FLASH_STATUS_TOTAL_BYTES (1 + FLASH_STATUS_DUMMY_BYTES + FLASH_STATUS_DATA_BYTES)

void flash_get_status_reg(uint8_t *status_out) {
    uint8_t txbuf[FLASH_STATUS_TOTAL_BYTES] = {0};
    uint8_t rxbuf[FLASH_STATUS_TOTAL_BYTES] = {0};
    txbuf[0] = FLASH_READ_STATUS_CMD;
    flash_do_cmd(txbuf, rxbuf, FLASH_STATUS_TOTAL_BYTES);
    for (int i = 0; i < FLASH_STAUTS_DATA_BYTES; i++)
        status_out[i] = rxbuf[i + 1 + FLASH_STATUS_DUMMY_BYTES];
}

Above didn't work - the XIP controller and flash aren't initialized in a
NO_FLASH binary. Searching on the internet yeilded a solution (see flash.c)
Results:

id: 33 32 36 34                                                                 
status1: 00                                                                     
status2: 02

So the QE bit is, in fact, set to one. Still don't know why continuous
read mode fails...

Tried changing the boot2 file in blink to generic_03, now boots. As does
generic_03_mod. Note that the build directory does neet to be removed,
and cmake re-run after changing boot file. Otherwise, make complains about
not finding the boot file. Changed to boot2_w25q080.S, and still boots.
Sigh. I don't know what's going on. There must be some weirdness in
programming/flash formatting.

Going back to getting over-clocking to work. Ok, so the 080_mod.S file
appears to brick the boot process. It looks the previous debugging
efforts left this in a weird state. Restoring from un-modified version,
and adding the pad voltage selects resulted in a booting state.

Proceeding incrementally:
1) vreg_set_voltage succeeded.
2) frequency set to 175 hangs, no output to USB or monitoring GPIO.
   reverting back succeeds.
3) 170 works, 180, 190, 200. Maybe 175 is unreable by the PLL?
4) 220, 240, 260, and finally, 280 works.

Now to try the same with mem_test. Sigh. "Handler HardFault"
Reverting back to no overclock didn't work. Reprogramming with overclocked
blink brought board back to life.

Found problem: forgot to copy fixed 080_mod.S to psram_wren/boot_stage2
directory. Now boots with 280MHz sysclock, from flash! Updated board 1,
also works. Confirmed via scope that we're getting 40 MB/s. (RWDS frequency
of 20 MHz).

22-jun-2023:

Discovered that I'd reversed the opening of the sd card connector. Nearly
impossible to insert card. Not sure if I was successful or not - the
test program indicates failure.

So, rev 1.2 fixes:
1) 180 rotation of SD card socket.
2) Add reset push button.
3) Add LED with jumper to GPIO 8 or 9.
4) Add male connector foot print in parallel with J3.
5) Add jumpers to reclaim unused SDIO pins: SD_DAT1/2 (GPIO 13/14).
6) Possibles: tune length of PSRAM IO vs clk, additional J3 with serial xover.

Wandering off-target for the moment:
Current hyperram.pio code size:
  27, leaving 5 instruction slots.
Ethernet (see 31-mar):
phy_tx.pio: 10 instructions
phy_rx.pio: 7 instructions
And SDIO:
_sdio.pio: sm0: 18, sm1: 5 + 9 = 14

So, we can either do ethernet or SDIO...

Back on target:
It looks like the SD card is fully inserted - it just barely clears
the level translator.

Debugging - probing the SD card connector:
1) pin 5 has clock of 403 kHz. This matches SPI mode clock.
2) pin 2 has low going pulse. This is chip select.
3) all other pins have no signal.

Ok, using modified blink.c to toggle 11, found that only a very small signal
on pin 3. Reflowed U5 (level translator) and now full swing signal observed.
Putting SD card in socket, running simple.c now works.

Defining USE_SPI in examples/command_line/hw_config.c enabled that
example to work:

> mount 0:                                                                      
                                                                                
> ls                                                                            
Directory Listing: 0:/                                                          
System Volume Information [directory] [size=0]                                  
RT11_V5_MUBasic.RL01 [writable file] [size=5242880]                             
Rsts_DL.RL01 [writable file] [size=5242880]                                     
RT11_V5_CFB.RL02 [writable file] [size=10486272]                                
MINC_BASIC.RK05 [writable file] [size=573440]                                   
RSX_31_Fortran.RK05 [writable file] [size=2457600]                              
Unix_V6.RK05 [writable file] [size=2091520]                                     
filename.txt [writable file] [size=28]                                          
                                                                                
> cat filename.txt                                                              
Hello, world!                                                                   
Hello, world!

Enabling SDIO mode via undefining USE_SPI:
> mount 0:                                                                      
sd_sdio_begin,110 SDIO not responding to CMD8 SEND_IF_COND, status 0x2 reply 0x0
f_mount error: The physical drive cannot work (3)                               
                                                                                
>

Time to prune!

Wandering again: Tried reducing the flash speed:
target_compile_definitions(boot2_mod PRIVATE PICO_FLASH_SPI_CLKDIV=8)
This works for the blink and mem_test projects.

Back on target: modified blink to toggle all of the SD socket pins - all
successfully toggled.

Refreshing git source:
git clone -b sdio --recurse-submodules https://github.com/carlk3/no-OS-FatFS-SD-SPI-RPi-Pico.git no-OS-FatFS

Didn't work - same results.

Some debugging shows that the receive pio never gets anything.

Given that we don't have enough PIO instruction slots for PSRAM, Ethernet
and SDIO, I think I'll put this aside for the moment, and go to Ethernet debug.

23-jun-2023:

Debugging pico-rmii-ethernet. To get it to build, changed CMakeLists.txt:
#set(LWIP_PATH ${CMAKE_CURRENT_LIST_DIR}/lib/lwip)
set(LWIP_PATH "${PICO_SDK_PATH}/lib/lwip")

Also made sram build via: /examples/httpd/CMakeLists.txt
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

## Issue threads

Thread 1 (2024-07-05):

Great Project! Can I have a breadboard version?

panelresources, 2024-07-05:
Hi, this project is great! I appreciate your efforts and I love retro workstations.
However, soldering the RP2040 and the BGA HyperRAM is challenging.

Is it possible to use one or more 8-pin 3.3V PSRAM that used in ESP32 modules instead of the HyperRAM? So, that the level shifters can be deleted. Then, we can use off-the-shelf Raspberry Pi Pico or Pico W for the build on a breadboard.

Anathae, 2024-07-05:
The chip that is being used here is a self refreshing dram chip that can runs at 1.8v.  Looks like the 8 pin PSRAM chips are limited to 8MB.  Replacing one BGA chip to 4 eight pin SOP chips would be a significant change in the circuit board.  As the HyperRAM interface (HyperBUS) is an eight pin bidirectional command and data bus, and PSRAM is QSPI, there would also be a significant change in the underlying code.  This would be a different project, IMNSHO.  Perhaps DECstationPiPico.

rscott2049, 2024-07-07:
Anathae has it right - the QPSI PSRAMs aren't fast enough, and would require much different code Note that Dmitry's project does use PSRAMs, so you may want to start there. Should be pretty easy to swap out the HyperRAM specific code for Dmitry's
PSRAM code, and use a RaspiPico board. I don't think there'll be enough bandwidth for video, however.

panelresources, 2024-07-08:
Thank you very much Anathae and Rscott2049 for the explanation.

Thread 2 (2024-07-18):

Missing rev 2.1 running photo

ironhaven, 2024-07-18:
The photo in the README labeled "rev 2.1 running" is the same photo as "rev 1.5 running". Can you update the photo so show the latest revision hooked up and running?

rscott2049, 2024-07-20:
Thanks for pointing that out! Cut'n'paste error - there was a photo in the doc/photos directory, but the README didn't point to it. I took a new photo (better quality, and shows the Logitech keyboard in action), and fixed the README.

Closed 2024-07-20.

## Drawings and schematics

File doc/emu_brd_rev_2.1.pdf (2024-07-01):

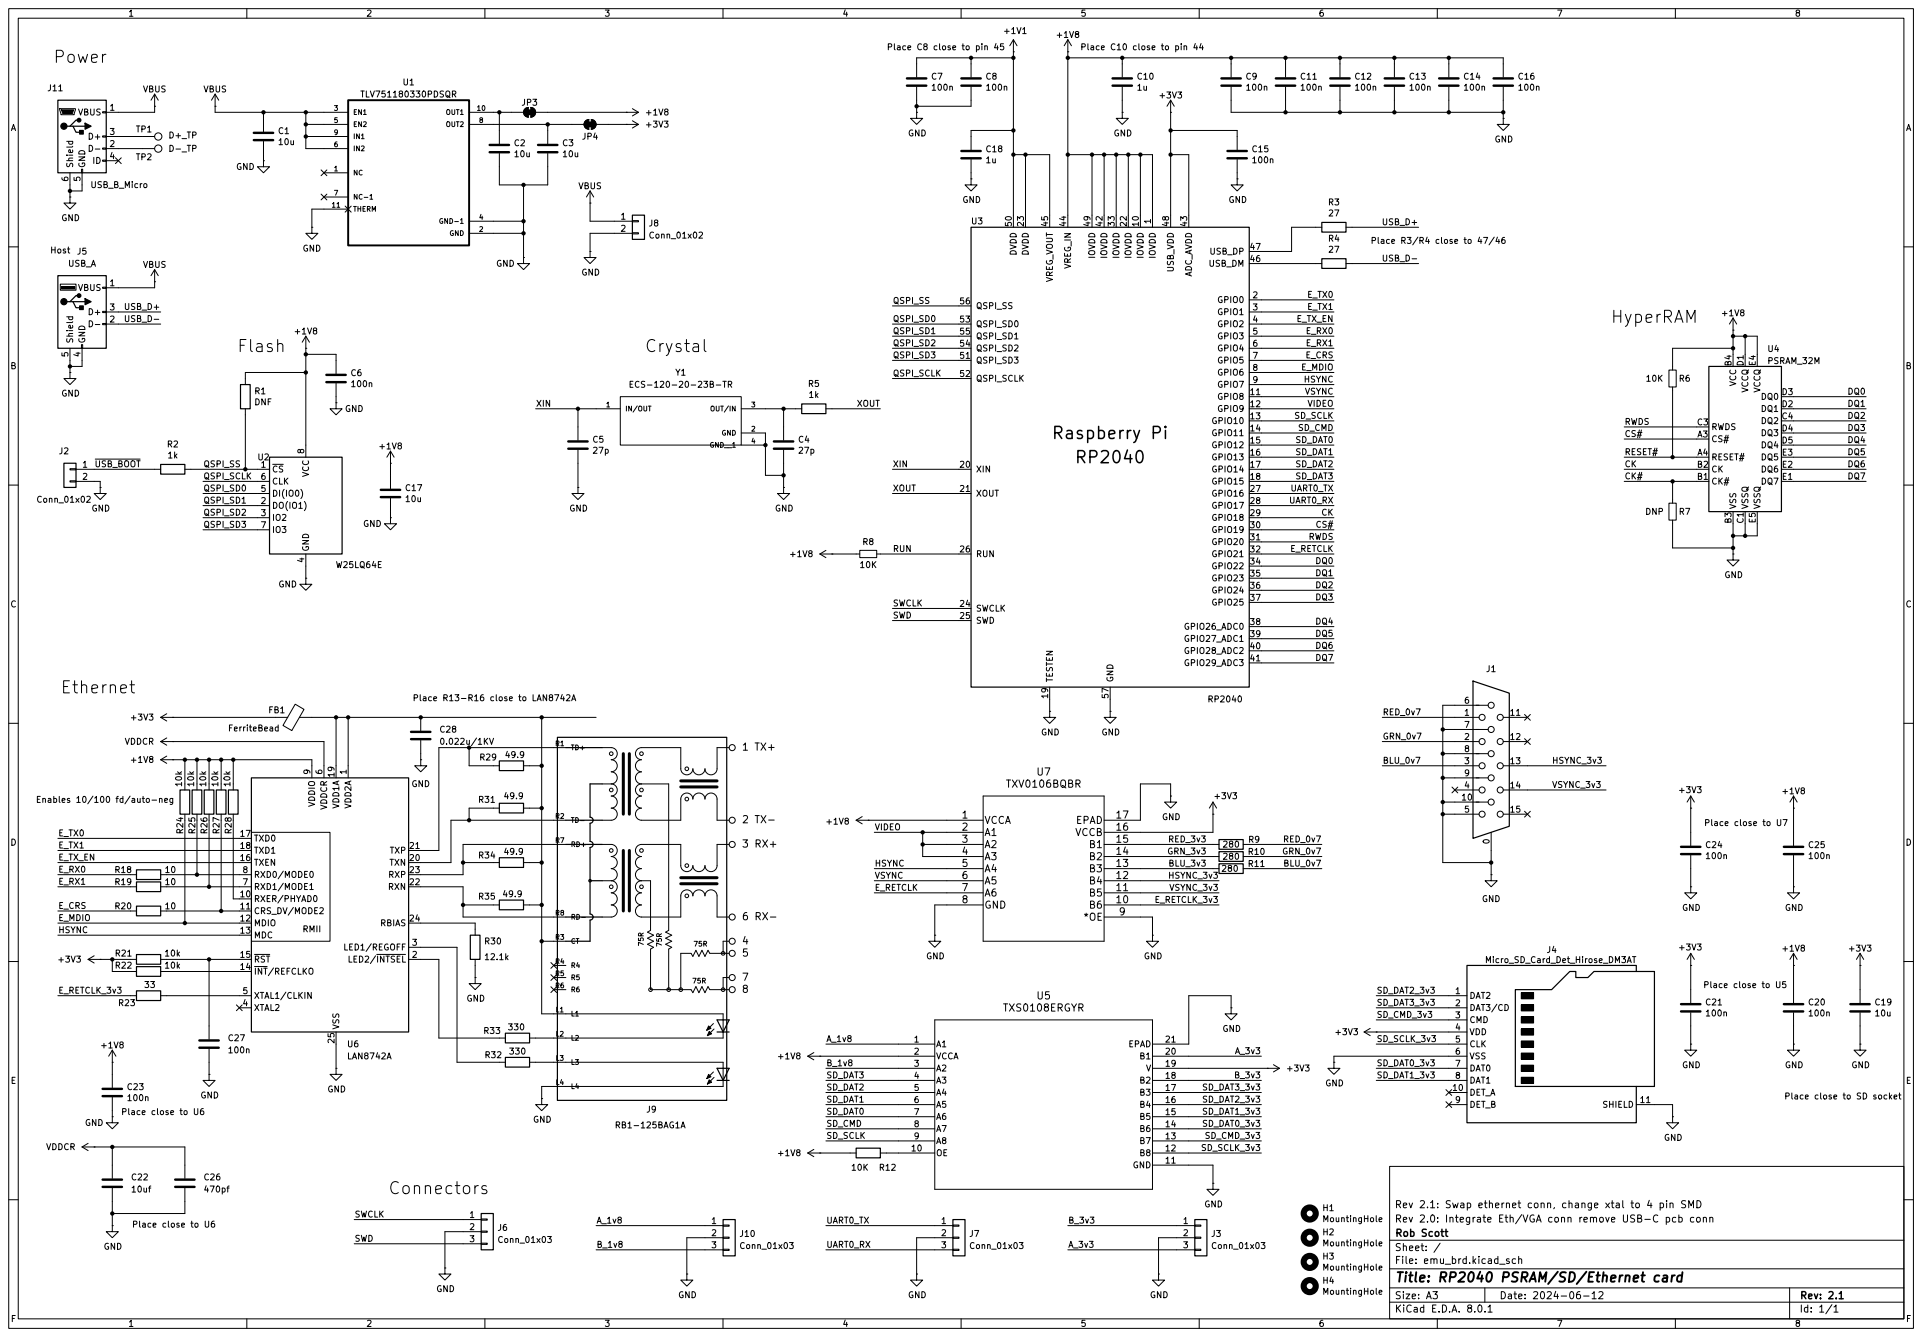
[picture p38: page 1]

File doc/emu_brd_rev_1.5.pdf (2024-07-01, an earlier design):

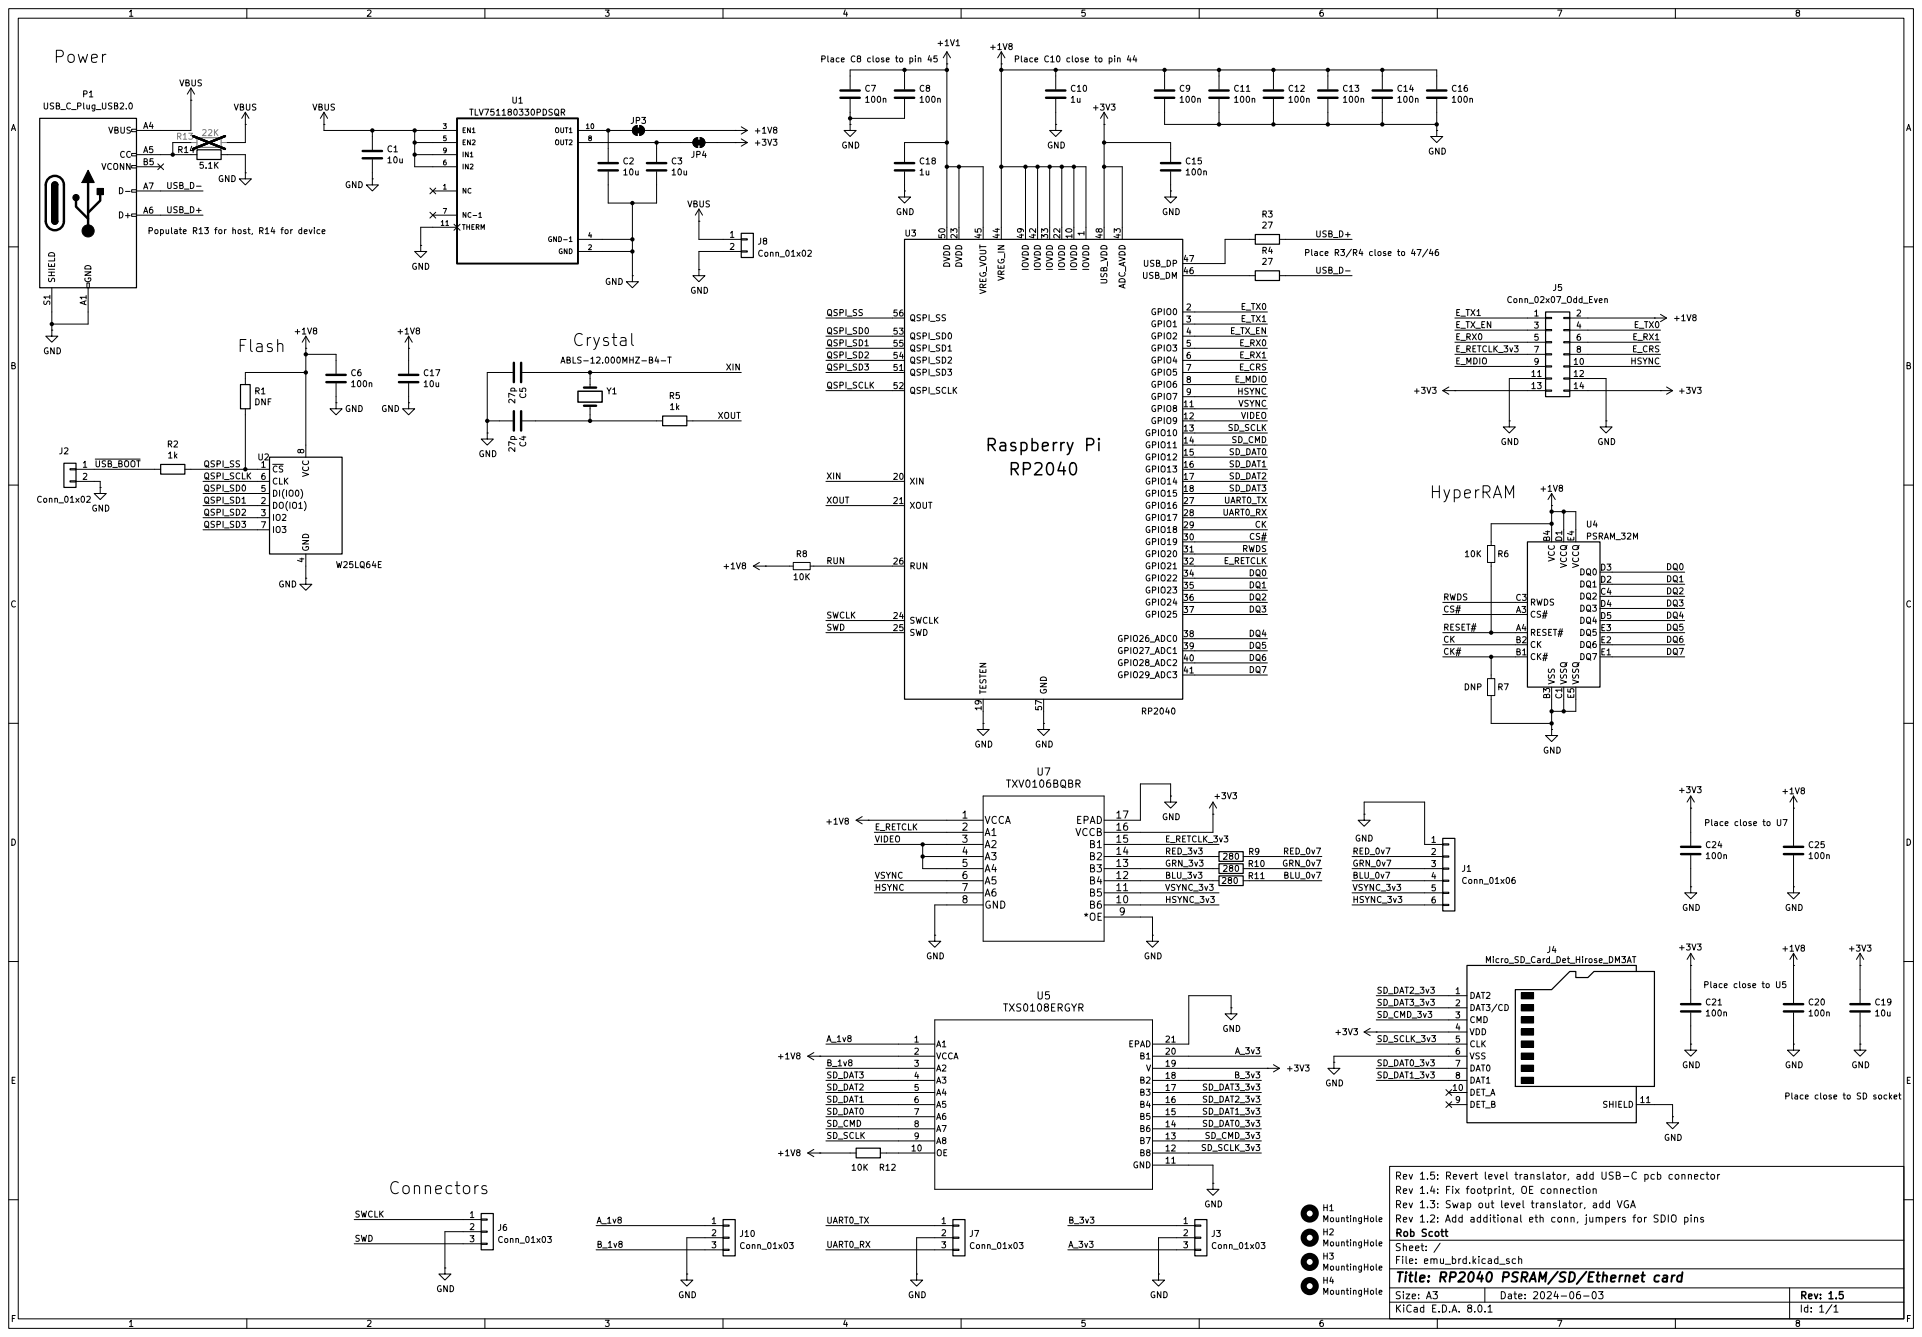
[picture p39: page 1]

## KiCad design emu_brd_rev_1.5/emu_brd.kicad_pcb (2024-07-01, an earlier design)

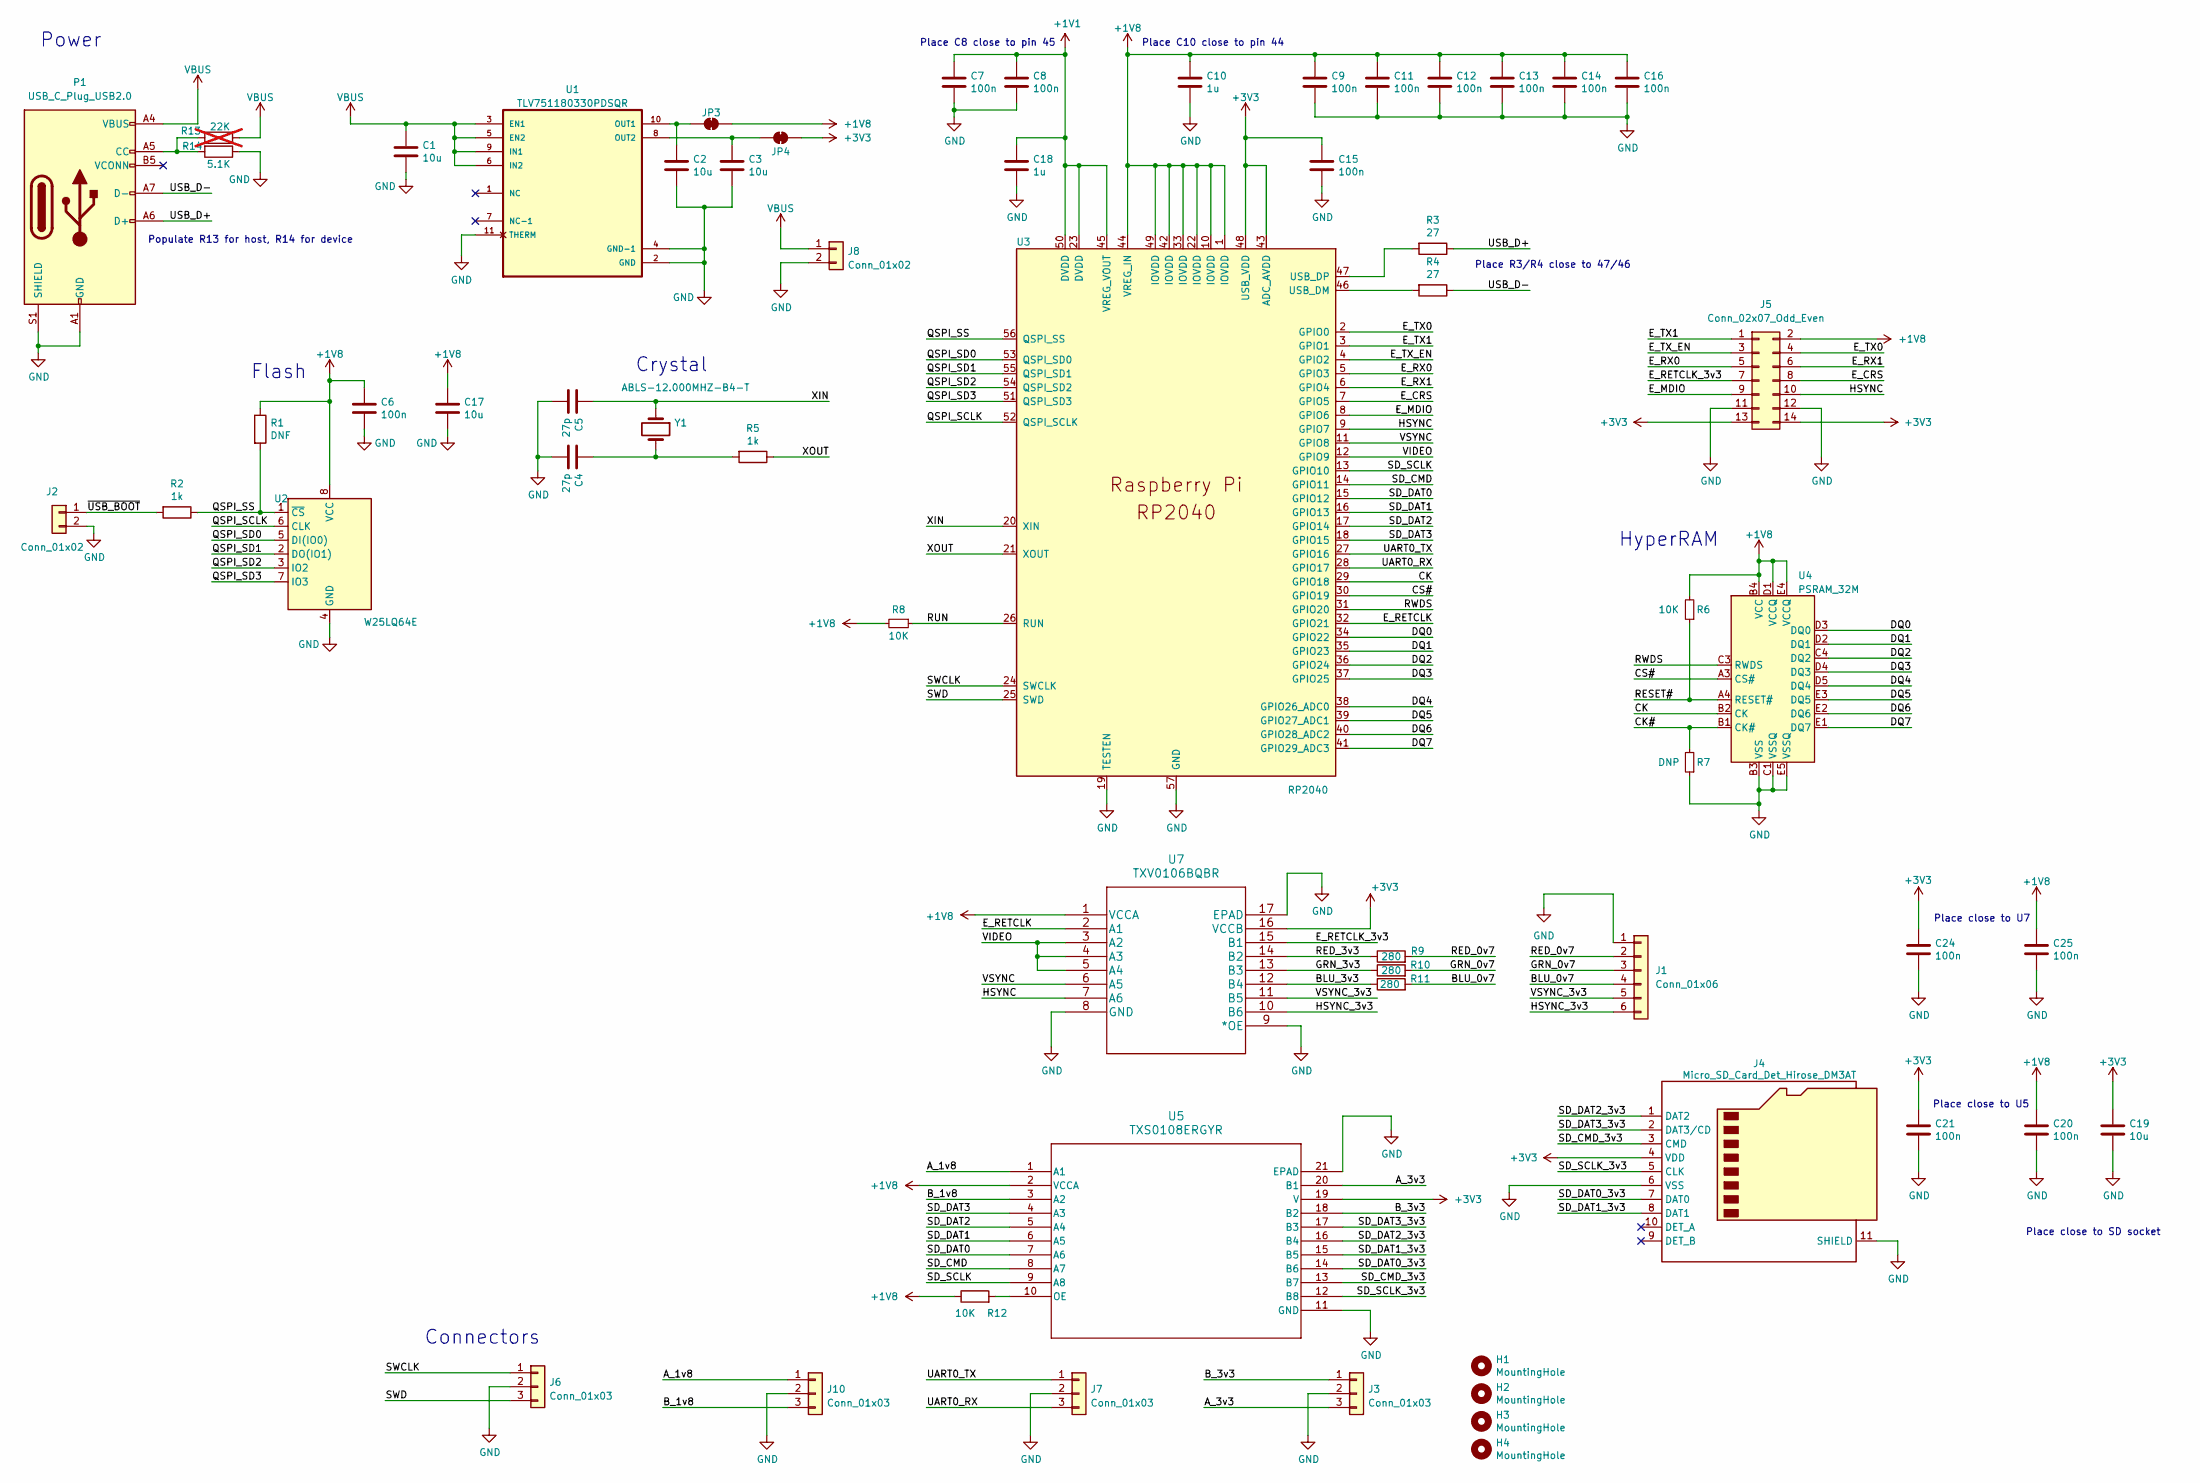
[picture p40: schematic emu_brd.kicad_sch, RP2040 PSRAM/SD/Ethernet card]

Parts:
C1, C2, C3, C17, C19: 10u; C_0805_2012Metric
C4, C5: 27p; C_0603_1608Metric
C6, C7, C8, C9, C11, C12, C13, C14, C15, C16, C20, C21, C24, C25: 100n; C_0603_1608Metric
C10, C18: 1u; C_0603_1608Metric
H1, H2, H3, H4: MountingHole; MountingHole_2.7mm_M2.5
J1: Conn_01x06; PinHeader_1x06_P2.54mm_Vertical
J2, J8: Conn_01x02; PinHeader_1x02_P2.54mm_Vertical
J3, J6, J7, J10: Conn_01x03; PinHeader_1x03_P2.54mm_Vertical
J4: Micro_SD_Card_Det_Hirose_DM3AT; microSD_HC_Hirose_DM3D-SF
J5: Conn_02x07_Odd_Even; PinSocket_2x07_P2.54mm_Horizontal
JP3, JP4: SolderJumper_2_Bridged; SolderJumper-2_P1.3mm_Bridged_Pad1.0x1.5mm
P1: USB_C_Plug_USB2.0; PCB-USB-C
R1: DNF; C_0603_1608Metric
R2, R5: 1k; C_0603_1608Metric
R3, R4: 27; C_0603_1608Metric
R6, R8, R12: 10K; R_0603_1608Metric
R7: DNP; R_0603_1608Metric
R9, R10, R11: 280; R_0603_1608Metric
R13: 22K; R_0603_1608Metric; not fitted
R14: 5.1K; R_0603_1608Metric
U1: TLV751180330PDSQR; SON40P200X200X80-11N
U2: W25LQ64E; WIN_ZP-8_WIN
U3: RP2040; RP2040-QFN-56
U4: PSRAM_32M; BGA25C100P5X5_800X600X120N
U5: TXS0108ERGYR; RGY20_3P05X2P05
U7: TXV0106BQBR; DHVQFN-16-1EP_2.5x3.5mm_P0.5mm_EP1x2mm
Y1: ABLS-12.000MHZ-B4-T; Crystal_SMD_5032-2Pin_5.0x3.2mm_HandSoldering

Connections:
+1V1: C7.1, C8.1, C18.1, U3.23 (DVDD), U3.45 (VREG_VOUT), U3.50 (DVDD)
+1V8: C6.1, C9.1, C10.1, C11.1, C12.1, C13.1, C14.1, C16.1, C17.1, C20.1, C25.1, J5.2, JP3.2 (B), R1.1, R6.2, R8.2, R12.1, U2.8 (VCC), U3.1 (IOVDD), U3.10 (IOVDD), U3.22 (IOVDD), U3.33 (IOVDD), U3.42 (IOVDD), U3.44 (VREG_IN), U3.49 (IOVDD), U4.B4 (VCC), U4.D1 (VCCQ), U4.E4 (VCCQ), U5.2 (VCCA), U7.1 (VCCA)
+3V3: C15.1, C19.1, C21.1, C24.1, J4.4 (VDD), J5.13, J5.14, JP4.2 (B), U3.43 (ADC_AVDD), U3.48 (USB_VDD), U5.19 (V), U7.16 (VCCB)
/A_1v8: J10.1, U5.1 (A1)
/A_3v3: J3.3, U5.20 (B1)
/BLU_0v7: J1.4, R11.2
/BLU_3v3: R11.1, U7.12 (B4)
/B_1v8: J10.3, U5.3 (A2)
/B_3v3: J3.1, U5.18 (B2)
/CK: U3.29 (GPIO18), U4.B2 (CK)
/CK#: R7.2, U4.B1 (CK#)
/CS#: U3.30 (GPIO19), U4.A3 (CS#)
/DQ0: U3.34 (GPIO22), U4.D3 (DQ0)
/DQ1: U3.35 (GPIO23), U4.D2 (DQ1)
/DQ2: U3.36 (GPIO24), U4.C4 (DQ2)
/DQ3: U3.37 (GPIO25), U4.D4 (DQ3)
/DQ4: U3.38 (GPIO26_ADC0), U4.D5 (DQ4)
/DQ5: U3.39 (GPIO27_ADC1), U4.E3 (DQ5)
/DQ6: U3.40 (GPIO28_ADC2), U4.E2 (DQ6)
/DQ7: U3.41 (GPIO29_ADC3), U4.E1 (DQ7)
/E_CRS: J5.8, U3.7 (GPIO5)
/E_MDIO: J5.9, U3.8 (GPIO6)
/E_RETCLK: U3.32 (GPIO21), U7.2 (A1)
/E_RETCLK_3v3: J5.7, U7.15 (B1)
/E_RX0: J5.5, U3.5 (GPIO3)
/E_RX1: J5.6, U3.6 (GPIO4)
/E_TX0: J5.4, U3.2 (GPIO0)
/E_TX1: J5.1, U3.3 (GPIO1)
/E_TX_EN: J5.3, U3.4 (GPIO2)
/GRN_0v7: J1.3, R10.2
/GRN_3v3: R10.1, U7.13 (B3)
/HSYNC: J5.10, U3.9 (GPIO7), U7.7 (A6)
/HSYNC_3v3: J1.6, U7.10 (B6)
/QSPI_SCLK: U2.6 (CLK), U3.52 (QSPI_SCLK)
/QSPI_SD0: U2.5 (DI(IO0)), U3.53 (QSPI_SD0)
/QSPI_SD1: U2.2 (DO(IO1)), U3.55 (QSPI_SD1)
/QSPI_SD2: U2.3 (IO2), U3.54 (QSPI_SD2)
/QSPI_SD3: U2.7 (IO3), U3.51 (QSPI_SD3)
/QSPI_SS: R1.2, R2.1, U2.1 (~CS), U3.56 (QSPI_SS)
/RED_0v7: J1.2, R9.2
/RED_3v3: R9.1, U7.14 (B2)
/RESET#: R6.1, U4.A4 (RESET#)
/RUN: R8.1, U3.26 (RUN)
/RWDS: U3.31 (GPIO20), U4.C3 (RWDS)
/SD_CMD: U3.14 (GPIO11), U5.8 (A7)
/SD_CMD_3v3: J4.3 (CMD), U5.13 (B7)
/SD_DAT0: U3.15 (GPIO12), U5.7 (A6)
/SD_DAT0_3v3: J4.7 (DAT0), U5.14 (B6)
/SD_DAT1: U3.16 (GPIO13), U5.6 (A5)
/SD_DAT1_3v3: J4.8 (DAT1), U5.15 (B5)
/SD_DAT2: U3.17 (GPIO14), U5.5 (A4)
/SD_DAT2_3v3: J4.1 (DAT2), U5.16 (B4)
/SD_DAT3: U3.18 (GPIO15), U5.4 (A3)
/SD_DAT3_3v3: J4.2 (DAT3/CD), U5.17 (B3)
/SD_SCLK: U3.13 (GPIO10), U5.9 (A8)
/SD_SCLK_3v3: J4.5 (CLK), U5.12 (B8)
/SWCLK: J6.1, U3.24 (SWCLK)
/SWD: J6.3, U3.25 (SWD)
/UART0_RX: J7.3, U3.28 (GPIO17)
/UART0_TX: J7.1, U3.27 (GPIO16)
/USB_D+: P1.A6 (D+), R3.1
/USB_D-: P1.A7 (D-), R4.1
/VIDEO: U3.12 (GPIO9), U7.3 (A2), U7.4 (A3), U7.5 (A4)
/VSYNC: U3.11 (GPIO8), U7.6 (A5)
/VSYNC_3v3: J1.5, U7.11 (B5)
/XIN: C5.1, U3.20 (XIN), Y1.1
/XOUT: R5.1, U3.21 (XOUT)
/~USB_BOOT: J2.1, R2.2
GND: C1.2, C2.2, C3.2, C4.2, C5.2, C6.2, C7.2, C8.2, C9.2, C10.2, C11.2, C12.2, C13.2, C14.2, C15.2, C16.2, C17.2, C18.2, C19.2, C20.2, C21.2, C24.2, C25.2, J1.1, J2.2, J3.2, J4.6 (VSS), J4.11 (SHIELD), J5.11, J5.12, J6.2, J7.2, J8.2, J10.2, P1.A1 (GND), P1.A12 (GND), P1.B1 (GND), P1.B12 (GND), P1.S1 (SHIELD), R7.1, R14.1, U1.2 (GND), U1.4 (GND-1), U1.11 (THERM), U2.4 (GND), U2.9, U3.19 (TESTEN), U3.57 (GND), U4.B3 (VSS), U4.C1 (VSSQ), U4.E5 (VSSQ), U5.11 (GND), U5.21 (EPAD), U7.8 (GND), U7.9 (*OE), U7.17 (EPAD)
unnamed: C4.1, R5.2, Y1.2
unnamed: C2.1, JP3.1 (A), U1.10 (OUT1)
unnamed: C3.1, JP4.1 (A), U1.8 (OUT2)
unnamed: P1.A5 (CC), R13.2, R14.2
unnamed: R4.2, U3.46 (USB_DM)
unnamed: R3.2, U3.47 (USB_DP)
unnamed: R12.2, U5.10 (OE)
VBUS: C1.1, J8.1, P1.A4 (VBUS), P1.A9 (VBUS), P1.B4 (VBUS), P1.B9 (VBUS), R13.1, U1.3 (EN1), U1.5 (EN2), U1.6 (IN2), U1.9 (IN1)

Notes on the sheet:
Connectors
Place close to SD socket
Flash
Place R3/R4 close to 47/46
Power
Place close to U5
Place C8 close to pin 45
HyperRAM
Populate R13 for host, R14 for device
Crystal
Place C10 close to pin 44
Place close to U7

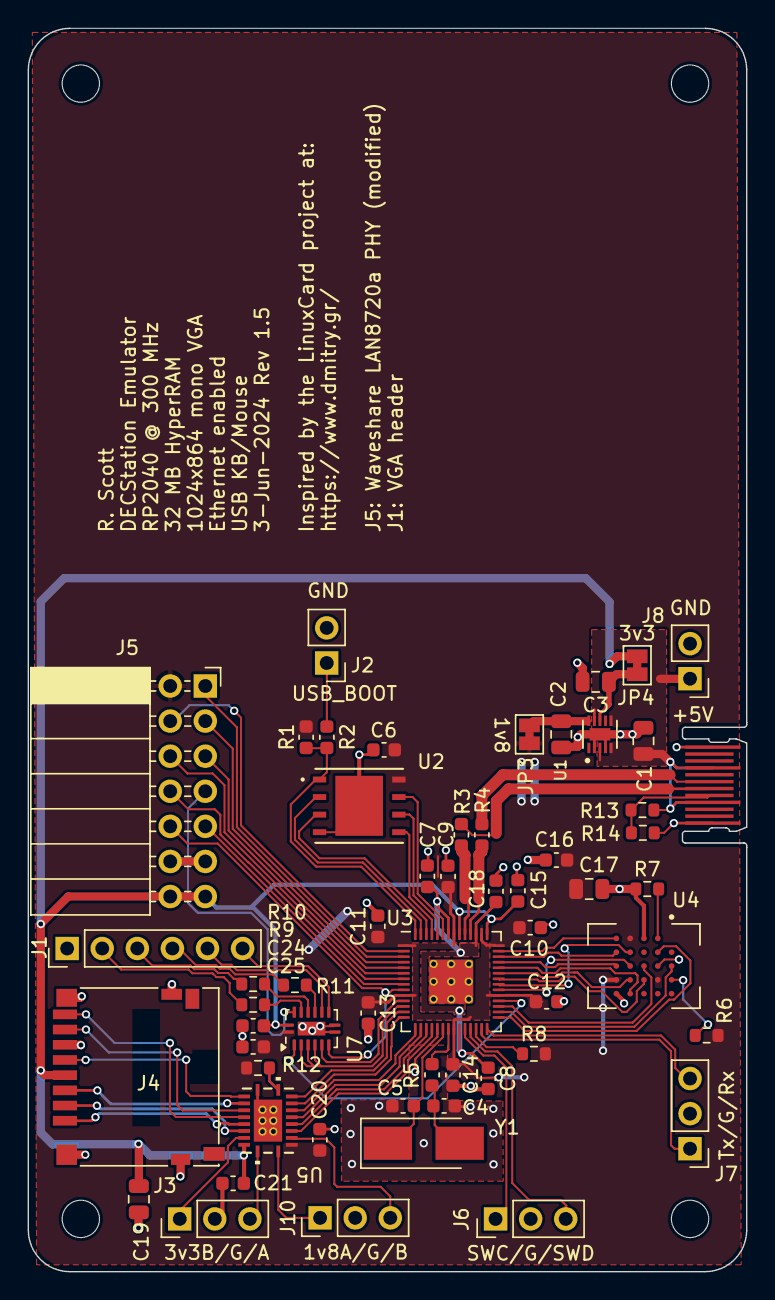
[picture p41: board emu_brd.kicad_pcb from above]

Board: 2 copper layers, 52.0 x 90.0 mm, 60 parts (0 on the bottom side), 77 nets.

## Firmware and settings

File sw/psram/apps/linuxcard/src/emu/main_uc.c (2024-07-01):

/*
	(c) 2021 Dmitry Grinberg   https://dmitry.gr
	Non-commercial use only OR licensing@dmitry.gr
*/

#if defined(CPU_STM32G0)
	#include "stm32g031xx.h"
#elif defined(CPU_SAMD)
	#include "samda1e16b.h"
#elif defined(CPU_CORTEXEMU)
	#include "CortexEmuCpu.h"
#endif

//#include <stdio.h>
//#include <string.h>
//#include "pico/stdlib.h"
#include "hw_config.h"
#include "sd_card.h"
#include "ff.h"
#include "f_util.h"
#include "ff_stdio.h"
#include "r3k_config.h"
#include "../hypercall.h"
#include "scsiNothing.h"
#include "scsiDisk.h"
#include "graphics.h"
#include "timebase.h"
#include "spiRam.h"
#include "printf.h"
#include "decBus.h"
#include "ds1287.h"
#include "lance.h"
#include "usart.h"
#include "ucHw.h"
#include "sdHw.h"
#include "dz11.h"
#include "soc.h"
#include "mem.h"
#include "sii.h"
#include "sd.h"
#include "usbHID.h"

uint32_t mFbBase, mPaletteBase, mCursorBase;
static uint32_t mSiiRamBase, mRamTop;
static uint8_t mDiskBuf[SD_BLOCK_SIZE];
static struct ScsiNothing gNoDisk;
static struct ScsiDisk gDisk;

static sd_card_t *pSD0;

static FIL gDiskFile;

static const uint8_t gRom[] = 
{
	#include "loader.inc"
};


void delayMsec(uint32_t msec)
{
	uint64_t till = getTime() + (uint64_t)msec * (TICKS_PER_SECOND / 1000);
	
	while (getTime() < till);
}


void prPutchar(char chr)
{
	#ifdef SUPPORT_DEBUG_PRINTF
	
#if 0
		#if (ZWT_ADDR & 3)		//byte
		
			*(volatile uint8_t*)ZWT_ADDR = chr;
					
		#else
			volatile uint32_t *addr = (volatile uint32_t*)ZWT_ADDR;
			
			while(addr[0] & 0x80000000ul);
			addr[0] = 0x80000000ul | (uint8_t)chr;
		#endif
#endif
	#endif
	
	#if 1
		if (chr == '\n')
			usartTx('\r');
			
		usartTx(chr);
		//putchar(chr);
	#endif
}

void fastpathReport(uint32_t val, uint32_t addr)
{
	pr("fastpath report: [%08x] = %08x\n", addr
	   , val);
}

void dz11charPut(uint_fast8_t line, uint_fast8_t chr)
{
	(void)chr;

	#ifdef MULTICHANNEL_UART
		
	usartTxEx(line, chr);
		
	#else
	
	if (line == 3)
	  usartTx(chr);
	
	#endif
	
	if (line == 0) decKeyboardTx(chr);	

	if (line == 1) decMouseTx(chr);

	if (line == 3) {
		/*	--	for benchmarking
		static uint8_t state = 0;
		
		switch (state) {
			case 0:
				if (chr == 'S')
					state = 1;
				break;
			case 1:
				state = (chr == 'C') ? 2 : 0;
				break;
			
			case 2:
				state = (chr == 'S') ? 3 : 1;
				break;
		
			case 3:
				state = (chr == 'I') ? 4 : 0;
				break;
			
			case 4:
				;
				uint64_t time = getTime();
				pr("\ntook 0x%08x%08x\n", (uint32_t)(time >> 32), (uint32_t)time);
				state = 5;
				break;
		}
		
		//*/
	//	prPutchar(chr);
	}
}

#if 0
#ifdef SUPPORT_MULTIBLOCK_ACCESSES_TO_SD		//worked on previous boards, will not anymore since we now share an SPI bus between RAM and SD
	

	static bool massStorageAccess(uint8_t op, uint32_t sector, void *buf)
	{
		static uint32_t mCurSec = 0xffffffff;
		static uint8_t mCurOp = 0xff;
		uint_fast8_t nRetries;
		
		switch (op) {
			case MASS_STORE_OP_GET_SZ:
				 *(uint32_t*)buf = sdGetNumSecs();
				 return true;
			
			case MASS_STORE_OP_READ:
			//	return sdSecRead(sector, buf);
				
				if (mCurOp == MASS_STORE_OP_READ && mCurSec == sector){
					
					if (sdReadNext(buf)) {
						mCurSec++;
						return true;
					}
					else {
						
						pr("failed to read next\n");
						sdReportLastError();
						mCurOp = 0xff;
						(void)sdReadStop();
						return false;
					}
				}
				
				if (mCurOp == MASS_STORE_OP_WRITE) {
					
					mCurOp = 0xff;
					if (!sdWriteStop()) {
						
						pr("failed to stop a write\n");
						sdReportLastError();
						return false;
					}
				}
				else if (mCurOp == MASS_STORE_OP_READ) {
					
					mCurOp = 0xff;
					if (!sdReadStop()) {
						
						pr("failed to stop a read\n");
						sdReportLastError();
						return false;
					}
				}
				
				for (nRetries = 0; nRetries < 2; nRetries++) {
				
					if (!sdReadStart(sector, 0)) {
						
						(void)sdReadStop();
						pr("failed to start a read\n");
						sdReportLastError();
						continue;
					}
					if (!sdReadNext(buf)) {
						
						(void)sdReadStop();
						pr("failed to read first sec\n");
						sdReportLastError();
						continue;
					}
					mCurOp = MASS_STORE_OP_READ;
					mCurSec = sector + 1;
					return true;
				}
				pr("giving up\n");
				return false;
				
			case MASS_STORE_OP_WRITE:
			
			//	return sdSecWrite(sector, buf);
			
				if (mCurOp == MASS_STORE_OP_WRITE && mCurSec == sector){
					
					if (sdWriteNext(buf)) {
						mCurSec++;
						return true;
					}
					else {
						
						pr("failed to write next\n");
						sdReportLastError();
						mCurOp = 0xff;
						(void)sdWriteStop();
						return false;
					}
				}
				
				if (mCurOp == MASS_STORE_OP_WRITE) {
					
					mCurOp = 0xff;
					if (!sdWriteStop()) {
						
						pr("failed to stop a write\n");
						sdReportLastError();
						return false;
					}
				}
				else if (mCurOp == MASS_STORE_OP_READ) {
					
					mCurOp = 0xff;
					if (!sdReadStop()) {
						
						pr("failed to stop a read\n");
						sdReportLastError();
						return false;
					}
				}
				
				///aaa
				mCurOp = 0xff;
				return sdSecWrite(sector, buf);
				///aaa
				
				
				for (nRetries = 0; nRetries < 2; nRetries++) {
				
					if (!sdWriteStart(sector, 0)) {
						
						pr("failed to start a write\n");
						sdReportLastError();
						(void)sdWriteStop();
						continue;
					}
					if (!sdWriteNext(buf)) {
						
						(void)sdWriteStop();
						pr("failed to write first sec\n");
						sdReportLastError();
						continue;
					}
					mCurOp = MASS_STORE_OP_WRITE;
					mCurSec = sector + 1;
					return true;
				}
				pr("giving up\n");
				return false;
		}
		return false;
	}
	
#else

	static bool massStorageAccess(uint8_t op, uint32_t sector, void *buf)
	{
		uint_fast8_t nRetries;
		
		switch (op) {
			case MASS_STORE_OP_GET_SZ:
				 *(uint32_t*)buf = sdGetNumSecs();
				 return true;
			
			case MASS_STORE_OP_READ:
				return sdSecRead(sector, buf);
				
			case MASS_STORE_OP_WRITE:
				return sdSecWrite(sector, buf);
		}
		return false;
	}

#endif
#endif
// rp2040 FAT file system level access
static bool massStorageAccess(uint8_t op, uint32_t sector, void *buf)
{
  FRESULT fr;
  unsigned int br;

	switch (op) {
		case MASS_STORE_OP_GET_SZ:
		  *(uint32_t*)buf = (uint32_t)(f_size(&gDiskFile)/(uint64_t)BLK_DEV_BLK_SZ);
		  return true;
		  
		case MASS_STORE_OP_READ:
		  f_lseek(&gDiskFile, (uint64_t)sector * (uint64_t)BLK_DEV_BLK_SZ);
		  f_read(&gDiskFile, buf, BLK_DEV_BLK_SZ, &br);
		  return br == BLK_DEV_BLK_SZ;

		case MASS_STORE_OP_WRITE:
		  f_lseek(&gDiskFile, (uint64_t)sector * (uint64_t)BLK_DEV_BLK_SZ);
		  f_write(&gDiskFile, buf, BLK_DEV_BLK_SZ, &br);
		  return br == BLK_DEV_BLK_SZ;
	}
	return false;
}


static bool accessRom(uint32_t pa, uint_fast8_t size, bool write, void* buf)
{
	const uint8_t *mem = gRom;

	pa -= (DS_ROM_BASE & 0x1FFFFFFFUL);
	
	if (write)
		return false;
	else if (size == 4)
		*(uint32_t*)buf = *(uint32_t*)(mem + pa);
	else if (size == 1)
		*(uint8_t*)buf = mem[pa];
	else if (size == 2)
		*(uint16_t*)buf = *(uint16_t*)(mem + pa);
	else
		memcpy(buf, mem + pa, size);
	
	return true;
}

static bool accessRam(uint32_t pa, uint_fast8_t size, bool write, void* buf)
{	

	if (write)
		spiRamWrite(pa, buf, size);
	else
		spiRamRead(pa, buf, size);

#if 0
	if (write) {
	  if ((pa & 0x3) != 0) {
	    pr("wr: unaligned access at: %08x size: %d\n", pa, size);
	    while(1) {}
	  }
	} else {
	  if ((pa & 0x3) != 0) {
	    pr("rd: unaligned access at: %08x size: %d data: %02x\n",
	       pa, size, *(uint8_t*)buf);
	  }
	}
#endif
	return true;
}

bool cpuExtHypercall(void)	//call type in $at, params in $a0..$a3, return in $v0, if any
{
	uint32_t hyperNum = cpuGetRegExternal(MIPS_REG_AT), t,  ramMapNumBits, ramMapEachBitSz;
	uint_fast16_t ofst;
	uint32_t blk, pa;
	uint8_t chr;
	bool ret;

	switch (hyperNum) {
		case H_GET_MEM_MAP:		//stays for booting older images which expect this
		
			switch (pa = cpuGetRegExternal(MIPS_REG_A0)) {
				case 0:
					pa = 1;
					break;
				
				case 1:
					pa = spiRamGetAmt();
					break;
				
				case 2:
					pa = 1;
					break;
				
				default:
					pa = 0;
					break;
			}
			cpuSetRegExternal(MIPS_REG_V0, pa);
			break;
		
		case H_CONSOLE_WRITE:
			chr = cpuGetRegExternal(MIPS_REG_A0);
			if (chr == '\n') {
			  //	prPutchar('\r');
			  usartTx('\r');
			}
			//prPutchar(chr);
			usartTx(chr);
			break;
		
		case H_STOR_GET_SZ:
			if (!massStorageAccess(MASS_STORE_OP_GET_SZ, 0, &t))
				return false;
			cpuSetRegExternal(MIPS_REG_V0, t);
			break;
		
		case H_STOR_READ:
			blk = cpuGetRegExternal(MIPS_REG_A0);
			pa = cpuGetRegExternal(MIPS_REG_A1);
			ret = massStorageAccess(MASS_STORE_OP_READ, blk, mDiskBuf);
			for (ofst = 0; ofst < SD_BLOCK_SIZE; ofst += OPTIMAL_RAM_WR_SZ)
				spiRamWrite(pa + ofst, mDiskBuf + ofst, OPTIMAL_RAM_WR_SZ);
			cpuSetRegExternal(MIPS_REG_V0, ret);

#if 0
			uint8_t tmp_buf[SD_BLOCK_SIZE];
			uint32_t csum = 0;
			for (ofst = 0; ofst < SD_BLOCK_SIZE; ofst += OPTIMAL_RAM_WR_SZ)
				spiRamRead(pa + ofst, tmp_buf + ofst, OPTIMAL_RAM_RD_SZ);

			for (int i = 0; i < SD_BLOCK_SIZE; i++) {
			  if (tmp_buf[i] != mDiskBuf[i]) {
			    pr("rd fail exp/act: %02x %02x\n", 
				   mDiskBuf[i], tmp_buf[i]);
			  }
			  csum += tmp_buf[i];
			}
			pr("rd blk csum: %d %08x\n", blk, csum);
			//if (blk > 31) while(1) {}
#endif
			if (!ret) {
				
				pr(" rd_block(%u, 0x%08x) -> %d\n", blk, pa, ret);
				while(1);
				hwError(6);
			}
			break;
		
		case H_STOR_WRITE:
			blk = cpuGetRegExternal(MIPS_REG_A0);
			pa = cpuGetRegExternal(MIPS_REG_A1);
			for (ofst = 0; ofst < SD_BLOCK_SIZE; ofst += OPTIMAL_RAM_RD_SZ)
				spiRamRead(pa + ofst, mDiskBuf + ofst, OPTIMAL_RAM_RD_SZ);
			ret = massStorageAccess(MASS_STORE_OP_WRITE, blk, mDiskBuf);
			cpuSetRegExternal(MIPS_REG_V0, ret);
			if (!ret) {
				
				pr(" wr_block(%u, 0x%08x) -> %d\n", blk, pa, ret);
				hwError(5);
			}
			break;
		
		case H_TERM:
			pr("termination requested\n");
			hwError(7);
			break;

		default:
			pr("hypercall %u @ 0x%08x\n", hyperNum, cpuGetRegExternal(MIPS_EXT_REG_PC));
			return false;
	}
	return true;
}

static bool mReportCy = false;

void cycleReport(uint32_t instr, uint32_t addr)
{
	uint_fast8_t i;
	
	if (mReportCy){
	
		//proper save/restore state not beig done. some regs will not read properly, like pc
		pr("[%08x]=%08x {", addr, instr);
		
		for (i = 0; i < 32; i++) {
			if (!(i & 7))
				pr("%u: ", i);
			pr(" %08x", cpuGetRegExternal(i));
		}
		pr("}\n");
	}
	else if (addr == 0x800D4FEC)
		mReportCy = 1;
}

void usartExtRx(uint8_t val)
{
  dz11charRx(3, val);
}

void reportInvalid(uint32_t pc, uint32_t instr)
{
	//inval used for emulation
	if (instr == 0x0000000F)
		return;
	
	//rdhwr
	if (instr == 0x7C03E83B)
		return;
	
	pr("INVAL [%08x] = %08x\n", pc, instr);
}

static void showBuf(uint_fast8_t idx, const uint8_t *buf)
{
	uint_fast16_t i;
	
	pr("BUFFER %u", idx);
	
	for (i = 0; i < 512; i++) {
		
		if (!(i & 15))
			pr("\n  %03x  ", i);
		pr(" %02x", *buf++);
	}
	pr("\n");
}

static void usartPuts(const char *s)
{
	char ch;
	
	while ((ch = *s++) != 0)
		usartTx(ch);
}

static void usartPutSmallDecimal(uint_fast8_t val)
{
	uint_fast8_t i;
	char ch[5];
	
	ch[i = sizeof(ch) - 1] = 0;
	do {
		uint_fast8_t div10 = (6554U * val) >> 16;
		
		ch[--i] = '0'+ val - 10 * div10;
		val = div10;
		
	} while (val);
	
	usartPuts(ch + i);
}

void dz11rxSpaceNowAvail(uint_fast8_t line)
{
	(void)line;
}

int main(void)
{
	uint8_t eachChipSz, numChips, chipWidth;
	volatile uint32_t t = 0;
	uint16_t cy = 0;

	initHwSuperEarly();

	usartInit();

	usbhid_init();

	// This must be called before sd_get_drive_prefix:
        sd_init_driver(); 

	pSD0 = sd_get_by_num(0);
	char const *drive_prefix = sd_get_drive_prefix(pSD0);
	FRESULT fr = f_mount(&pSD0->state.fatfs, drive_prefix, 1);
	if (FR_OK != fr) {
	  hwError(2);
	  pr("SD mount error: %s (%d)\n\r", FRESULT_str(fr), fr);
	} else {
	  pr("SD mount OK!\n\r");
	}

#if 0
        fr  = f_open(&gDiskFile, "ultrix.textmode", FA_READ | FA_WRITE);
	if(fr != FR_OK){
	  pr("Failed to open %s\n", "ultrix.textmode");
		return -1;
	}
	else pr("Opened %s\n", "ultrix.textmode");
#endif

#if 1
        fr  = f_open(&gDiskFile, "ultrix.gui", FA_READ | FA_WRITE);
	if(fr != FR_OK){
	  pr("Failed to open %s\n", "ultrix.gui");
		return -1;
	}
	else pr("Opened %s\n", "ultrix.gui");
#endif

#if 0
        fr  = f_open(&gDiskFile, "linux.wheezy", FA_READ | FA_WRITE);
	if(fr != FR_OK){
	  pr("Failed to open %s\n", "linux.wheezy");
		return -1;
	}
	else pr("Opened %s\n", "linux.wheezy");
#endif


#if 0
	//	while(1) {
	for(int i = 0; i<3; i++) {
	  pr("hello\n");
	  sleep_ms(1000);
	}


	uint32_t buff;
	massStorageAccess(MASS_STORE_OP_GET_SZ,  0, (void *)&buff);
	pr("size: %d\n", buff);

	pr("size: %llu\n", f_size(&gDiskFile));
	pr("size mb: %llu\n", f_size(&gDiskFile)/(1024*1024));
	pr("size gb: %llu\n", f_size(&gDiskFile)/(1024*1024*1024));


	pr("seek to end: %d\n", f_lseek(&gDiskFile, (uint64_t)buff * (uint64_t) BLK_DEV_BLK_SZ));
	pr("seek to beginning: %d\n", ff_fseek(&gDiskFile, 0, SEEK_SET));
	pr("seek to end: %d\n", ff_fseek(&gDiskFile, 0, SEEK_END));

	pr("tell: %d\n", ff_ftell(&gDiskFile)/BLK_DEV_BLK_SZ);


	while(1) {}
#endif
	//return 0;

	initHw();
	asm volatile("cpsie i");
	timebaseInit();
	//usartInit();
	
	pr("ready, time is 0x%016llx\n", getTime());
	pr("ready, time is 0x%016llx\n", getTime());

#if 0
	if (!sdCardInit(mDiskBuf)) {
		
		hwError(2);
		pr("SD card init fail\n");
	}
#else 
	if (0) {
	  
	}
#endif
	else if (!spiRamInit(&eachChipSz, &numChips, &chipWidth)) {
	        hwError(3);
		pr("SPI ram init issue\n");
	}
#if 1
	else if (!graphicsInit()) {
	  pr("Graphics init issue\n");
	}
#endif
	else {
	  	uint32_t ramAmt = spiRamGetAmt();
		pr("ram: %d\n", ramAmt/(1024*1024));

		cpuInit(ramAmt);

		uint_fast8_t i;
		
		//divvy up the RAM
		mSiiRamBase = ramAmt -= SII_BUFFER_SIZE;
		mFbBase = ramAmt -= SCREEN_BYTES;
		mPaletteBase = ramAmt -= SCREEN_PALETTE_BYTES;
		mCursorBase = ramAmt -= SCREEN_CURSOR_BYTES;
		// Set screen display/palette/cursor start appropriately
		graphicsSetStart(mFbBase, mPaletteBase, mCursorBase);
		//round usable ram to page size
		mRamTop = ramAmt = (ramAmt >> 12) << 12;
		pr("ramtop: %d\n", mRamTop/(1024*1024));

		pr("ram:         0x%08x - 0x%08x\n", 0x0, mRamTop - 1);
		pr("palette:     0x%08x - 0x%08x\n",
		   mPaletteBase, mPaletteBase + SCREEN_PALETTE_BYTES - 1);
		pr("framebuffer: 0x%08x - 0x%08x\n",
		   mFbBase, mFbBase + SCREEN_BYTES - 1);
		
#if 0
		extern uint32_t *mCpu;
#define OFST_MEMLIMIT			0x3c
#define NUM_REGS				32
#define OFST_PART2				(NUM_REGS * 4)

		pr("cpuAsm mtop: 0x%08x\n", mCpu[OFST_PART2 + OFST_MEMLIMIT]);
#endif

		if (!memRegionAdd(RAM_BASE, ramAmt, accessRam))
			pr("failed to init %s\n", "RAM");
		else if (!memRegionAdd(DS_ROM_BASE & 0x1FFFFFFFUL, sizeof(gRom), accessRom))
			pr("failed to init %s\n", "ROM");
		else if (!decBusInit())
			pr("failed to init %s\n", "DEC BUS");
		else if (!dz11init())
			pr("failed to init %s\n", "DZ11");
		else if (!siiInit(7))
			pr("failed to init %s\n", "SII");
		else if (!scsiDiskInit(&gDisk, 6, massStorageAccess, mDiskBuf, false))
			pr("failed to init %s\n", "SCSI disc");
		else {
			for (i = 0; i < 6; i++) {
				if (!scsiNothingInit(&gNoDisk, i)) {
					
					pr("failed to init %s\n", "SCSI dummy");
					break;
				}
			}
			
			if (i == 6) {
				
				if (!ds1287init())
					pr("failed to init %s\n", "DS1287");
				else if (!lanceInit())
					pr("failed to init %s\n", "LANCE");
				else {
					
					char x[16];
					usartPuts("uMIPS v2.2.0 (BL ver ");
					usartPutSmallDecimal(*(volatile uint8_t*)8 - 0x10);

					usartPuts(")\r\n will run with ");

#if 0
					usartPutSmallDecimal(numChips);
					usartTx('x');
					usartPutSmallDecimal(eachChipSz);
					usartPuts("MB x");
					usartPutSmallDecimal(chipWidth);
					usartPuts(" RAMs, \r\n");
#else
					usartPutSmallDecimal(EMULATOR_RAM_MB);
					usartPuts("MB\r\n");
#endif					
					printRegions();

					cpuInit(ramAmt);
					while(1) {
					  cy++;
					  cpuCycle(ramAmt);
					}
					while(1);
				}
			}	
		}
		hwError(4);
	}

	while(1);
}

void siiPrvBufferWrite(uint_fast16_t wordIdx, uint_fast16_t val)
{
	uint32_t addr = mSiiRamBase + wordIdx * 2;
	uint16_t v = val;
	
	spiRamWrite(addr, &v, 2);
}

uint_fast16_t siiPrvBufferRead(uint_fast16_t wordIdx)
{
	uint16_t ret;
	
	spiRamRead(mSiiRamBase + wordIdx * 2, &ret, 2);
	
	return ret;
}


void __attribute__((used)) report_hard_fault(uint32_t* regs, uint32_t ret_lr, uint32_t *user_sp)
{
	#ifdef SUPPORT_DEBUG_PRINTF
		uint32_t *push = (ret_lr == 0xFFFFFFFD) ? user_sp : (regs + 8), *sp = push + 8;
		unsigned i;
		
		prRaw("============ HARD FAULT ============\n");
		prRaw("R0  = 0x%08X    R8  = 0x%08X\n", (unsigned)push[0], (unsigned)regs[0]);
		prRaw("R1  = 0x%08X    R9  = 0x%08X\n", (unsigned)push[1], (unsigned)regs[1]);
		prRaw("R2  = 0x%08X    R10 = 0x%08X\n", (unsigned)push[2], (unsigned)regs[2]);
		prRaw("R3  = 0x%08X    R11 = 0x%08X\n", (unsigned)push[3], (unsigned)regs[3]);
		prRaw("R4  = 0x%08X    R12 = 0x%08X\n", (unsigned)regs[4], (unsigned)push[4]);
		prRaw("R5  = 0x%08X    SP  = 0x%08X\n", (unsigned)regs[5], (unsigned)sp);
		prRaw("R6  = 0x%08X    LR  = 0x%08X\n", (unsigned)regs[6], (unsigned)push[5]);
		prRaw("R7  = 0x%08X    PC  = 0x%08X\n", (unsigned)regs[7], (unsigned)push[6]);
		prRaw("RA  = 0x%08X    SR  = 0x%08X\n", (unsigned)ret_lr,  (unsigned)push[7]);
		//		prRaw("SHCSR = 0x%08X\n", SCB->SHCSR);
		#if defined(CPU_CM7)
	    	prRaw("CFSR  = 0x%08X    HFSR  = 0x%08X\n", SCB->CFSR, SCB->HFSR);
	    	prRaw("MMFAR = 0x%08X    BFAR  = 0x%08X\n", SCB->MMFAR, SCB->BFAR);
		#endif
	    
		prRaw("WORDS @ SP: \n");
		
		for (i = 0; i < 32; i++)
			prRaw("[sp, #0x%03x = 0x%08x] = 0x%08x\n", i * 4, (unsigned)&sp[i], (unsigned)sp[i]);
		
		prRaw("\n\n");
	#endif
	
	while(1);
}

#ifdef NO_EXTERNAL_HF_HANDLER
void __attribute__((noreturn, naked, noinline)) HardFault_Handler(void)
{
	asm volatile(
			"push {r4-r7}				\n\t"
			"mov  r0, r8				\n\t"
			"mov  r1, r9				\n\t"
			"mov  r2, r10				\n\t"
			"mov  r3, r11				\n\t"
			"push {r0-r3}				\n\t"
			"mov  r0, sp				\n\t"
			"mov  r1, lr				\n\t"
			"mrs  r2, PSP				\n\t"
			"bl   report_hard_fault		\n\t"
			:::"memory");
}
#endif

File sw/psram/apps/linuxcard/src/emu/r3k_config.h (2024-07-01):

#ifndef _R3K_CONFIG_H
#define _R3K_CONFIG_H

/******************/
/* Emulator config
/******************/

// RAM size in megabytes
#define EMULATOR_RAM_MB 32

// Image filename
#define IMAGE_FILENAME "0:linux.wheezy"

// Enable UART console
#define CONSOLE_UART 1

// Enable USB CDC console
#define CONSOLE_CDC 0

#if CONSOLE_UART

/******************/
/* UART config
/******************/

// UART instance
#define UART_INSTANCE uart1

// UART Baudrate (if enabled)
#define UART_BAUD_RATE 115200

// Pins for the UART (if enabled)
#define UART_TX_PIN 8
#define UART_RX_PIN 9

#endif

/****************/
/* SD card config
/***************/

// Set to 1 to use SDIO interface for the SD. Set to 0 to use SPI.
#define SD_USE_SDIO 1

#if SD_USE_SDIO

/****************/
/* SDIO interface
/****************/

// Pins for the SDIO interface (if used)
// CLK will be D0 - 2,  D1 = D0 + 1,  D2 = D0 + 2,  D3 = D0 + 3
#ifdef ORIG_CONFIG
#define SDIO_PIN_CMD 18
#define SDIO_PIN_D0 19
#endif
#define SDIO_PIN_CMD 11
#define SDIO_PIN_D0 12

#else

/*******************/
/* SD SPI interface
/******************/

// SPI instance used for SD (if used)
#define SD_SPI_INSTANCE spi1

// Pins for the SD SPI interface (if used)
#define SD_SPI_PIN_MISO 12
#define SD_SPI_PIN_MOSI 11
#define SD_SPI_PIN_CLK 10
#define SD_SPI_PIN_CS 15

#endif // SD_USE_SDIO

#endif // _R3K_CONFIG_H

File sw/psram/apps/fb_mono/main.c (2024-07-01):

#include <stdio.h>

#include "pico/stdlib.h"
#include "hardware/pio.h"
#include "hardware/vreg.h"
#include "hardware/clocks.h"

#include "hyperram.h"
#include "fb_mono.h"

// For setting 1.8v threshold
#include "hardware/regs/addressmap.h"
#include "hardware/regs/pads_bank0.h"

// VGA pins
unsigned int VGA_VSYNC_PIN = 13;
unsigned int VGA_HSYNC_PIN = 14;
unsigned int VGA_GREEN_PIN = 16;

// Select one video format from below
//#define USE_1024x768
#define USE_1024x768_70
//#define USE_640x480

// Parameters for 1024x768 @ 60 Hz
#ifdef USE_1024x768
#define PIX_CLK 65000000

#define H_TOTAL 1344
#define H_ACTIVE 1024
#define H_FP 24
#define H_SYNC 136
#define H_BP 160
#define H_SYNC_POLARITY 0

#define V_TOTAL 806
#define V_ACTIVE 768
#define V_FP 3
#define V_SYNC 6
#define V_BP 29
#define V_SYNC_POLARITY 0
#endif

// Parameters for 1024x768 @ 70 Hz
#ifdef USE_1024x768_70
#define PIX_CLK 75000000

#define H_TOTAL 1328
#define H_ACTIVE 1024
#define H_FP 24
#define H_SYNC 136
#define H_BP 144
#define H_SYNC_POLARITY 0

#define V_TOTAL 806
#define V_ACTIVE 768
#define V_FP 3
#define V_SYNC 6
#define V_BP 29
#define V_SYNC_POLARITY 0
#endif

// Parameters for 640 x 480 @60 Hz
#ifdef USE_640x480
#define PIX_CLK 25175000

#define H_TOTAL 800
#define H_ACTIVE 640
#define H_FP 16
#define H_SYNC 96
#define H_BP 48
#define H_SYNC_POLARITY 1

#define V_TOTAL 525
#define V_ACTIVE 480
#define V_FP 10
#define V_SYNC 2
#define V_BP 33
#define V_SYNC_POLARITY 1
#endif

void put_pix(uint32_t *fb_addr, uint32_t x, uint32_t y, uint32_t color) {
  uint32_t pixels;

  // Position pixel within 32 bit word
  uint32_t pix_mask = 1 << (x & 0x1f);

  // Calculate pixel address
  uint32_t pix_addr = (y << 5) + (x >> 5);

  // Do RMW to set/clear pixel
  hyperram_read_blocking(&g_hram_all[0], pix_addr<<2, &pixels, 1);
  pixels = (pixels & ~pix_mask) | (color << (x & 0x1f));
  hyperram_write_blocking(&g_hram_all[0], pix_addr<<2, &pixels, 1);

}


void draw_box(uint32_t *fb_addr, uint32_t x, uint32_t y, uint32_t size, uint32_t color) {
  uint32_t i, j;
  uint32_t next_x;

  for (i = 0; i < size; i++) {
    next_x = x;
    for (j = 0; j < size; j++) {
      put_pix(fb_addr, next_x++, y, color);
    }
    y++;
  }
}

void printdata(const uint8_t *data, uint len) {
	for (int i = 0; i < len; ++i)
		printf("%02x%c", data[i], i % 16 == 15 ? '\n' : ' ');
	if (len % 16 != 15)
		printf("\n"); 
}

void printdataint(const uint32_t *data, uint len) {
	for (int i = 0; i < len; ++i)
		printf("%08x%c", data[i], i % 8 == 7 ? '\n' : ' ');
	//	if (len % 8 != 7) printf("\n"); 
}


int main() {
  int clkdiv;
  int pass;

  vreg_set_voltage(VREG_VOLTAGE_1_20);
  sleep_ms(1);
  pass = set_sys_clock_khz(300 * 1000, true);

  //	setup_default_uart();
  stdio_init_all();
  sleep_ms(3000);

  if (pass) {
    printf("Set sysclk to 300 MHz\n");
  } else {
    printf("FAILED: Did not set sysclk to 300 MHz\n");
  }


  // Set 1.8v threshold for I/O pads
  io_rw_32* addr = (io_rw_32 *)(PADS_BANK0_BASE + PADS_BANK0_VOLTAGE_SELECT_OFFSET);
  *addr = PADS_BANK0_VOLTAGE_SELECT_VALUE_1V8 << PADS_BANK0_VOLTAGE_SELECT_LSB;

  printf("pad bank0 voltage select addr/data: %08x %08x\n", (uint32_t)addr,
	 (uint32_t)*addr);



  // Setup RAM
  pass = hyperram_init();
  if (pass == 0) {
    printf("Hyperram initialized\n");
  } else {
    printf("FAILED: Did not initialize Hyperram\n");
  }

  // Setup mono frame buffer
  fb_mono_inst_t inst = {
    .pio = pio1,
    .sm_sync = 2,
    .sm_video = 3,
    .pio_fb = g_hram_all[1].pio,
    .sm_fb = g_hram_all[1].sm,
    .sync_base_pin = VGA_VSYNC_PIN,
    .vsync_offset = 0,
    .hsync_offset = VGA_HSYNC_PIN - VGA_VSYNC_PIN,
    .vsync_assert_polarity = V_SYNC_POLARITY,
    .hsync_assert_polarity = H_SYNC_POLARITY,
    .vga_green_pin = VGA_GREEN_PIN,
    .pix_clk = PIX_CLK,
    .hfp = H_FP,
    .hactive = H_ACTIVE,
    .hbp = H_BP,
    .hsync = H_SYNC,
    .htotal = H_TOTAL,
    .vfp = V_FP,
    .vactive = V_ACTIVE,
    .vbp = V_BP,
    .vsync = V_SYNC,
    .vtotal = V_TOTAL
  };

  printf("Using %d x %d video format\n", inst.hactive, inst.vactive);

  uint32_t *fb_addr = fb_mono_init(&inst);
  
  printf("Initialzing frame buffer\n");

#if 0
  printf("FB addr: %08x\n", (uint32_t)fb_addr);
  for (int j = 0; j < inst.vactive; j++) {
    for (int i = 0; i < inst.hactive/32; i++) {
      uint32_t pix_addr = (j * inst.hactive/32) + i;
      fb_addr[pix_addr] = (j & 1) ? 0xaaaaaaaa : 0x55555555;
      //fb_addr[pix_addr] = 0;
    }
  }
#endif

  uint32_t line_buf[32];
  uint32_t pix_addr;

  for (int j = 0; j < inst.vactive; j++) {
    for (int i = 0; i < inst.hactive/32; i++) {
      line_buf[i] =  (j & 1) ? 0xaaaaaaaa : 0x55555555;
      //line_buf[i] =  ((i % 4) == 0) ? -1 : 0;
    }
    pix_addr = (j * inst.hactive/32);
    hyperram_write_blocking(&g_hram_all[0], pix_addr<<2, line_buf, 32);
  }

  while (0) {
    int j = 0;
    for (int i = 0; i < inst.hactive/32; i++) {
      line_buf[i] = -1;
    }
    pix_addr = (j * inst.hactive/8);
    hyperram_write_blocking(&g_hram_all[0], pix_addr, line_buf, 32);
    pix_addr = inst.vactive * inst.hactive/8;
    hyperram_write_blocking(&g_hram_all[0], pix_addr, line_buf, 32);

    for (int i = 0; i < inst.hactive/32; i++) {
      line_buf[i] = 0;
      if (i == 0) line_buf[i] = 0x1;
      if (i == 31) line_buf[i] = 0x80000000;
    }
    for (j = 1; j < inst.vactive - 2; j++) {
      pix_addr = (j * inst.hactive/8);
      hyperram_write_blocking(&g_hram_all[0], pix_addr, line_buf, 32);
    }
    draw_box(fb_addr, 0, 0, 10, 1);
    draw_box(fb_addr, (1024/4)+2, 0, 10, 1);
    sleep_ms(1000);
  }

  int32_t x, old_x;
  int32_t y, old_y;
  int32_t x_inc, y_inc;
  uint32_t size = 10;

  x_inc = 3;
  y_inc = 3;
  x = 0;
  y = 0;

#if 0
  for (int i = 0; i < 32; i++) {
    draw_box(fb_addr, x+(i*size), y+(i*size), size, 1);
    fb_mono_sync_wait(inst.vactive);
  }

  for (int i = 0; i < 16; i++) {
    draw_box(fb_addr, x+(i*size), y+(i*size), size, 0);
    for (int j = 0; j < 70; j++) {
      fb_mono_sync_wait(inst.vactive);
    }
  }
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

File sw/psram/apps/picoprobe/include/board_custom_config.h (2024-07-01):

/*
 * The MIT License (MIT)
 *
 * Copyright (c) 2023 Raspberry Pi (Trading) Ltd.
 *
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
 */

#ifndef BOARD_CUSTOM_H_
#define BOARD_CUSTOM_H_

/* Direct connection - SWCLK/SWDIO on two GPIOs */
#define PROBE_IO_RAW

/* Include CDC interface to bridge to target UART. Omit if not used. */
#define PROBE_CDC_UART

#define PROBE_SM 0
// Use emu board 3v3 I/Os for SWD: J7, select GPIO16/17 via jumpers 1 & 2
//#define PROBE_PIN_OFFSET 16

// Use emu board 3v3 I/Os for SWD: GPIO13/14 (aka: SD_CMD1, SD_CMD2)
//#define PROBE_PIN_OFFSET 13

// Use emu board 1v8 I/Os for SWD: GPIO8/9
#define PROBE_PIN_OFFSET 8

/* PIO config for PROBE_IO_RAW */
#if defined(PROBE_IO_RAW)
#define PROBE_PIN_SWCLK (PROBE_PIN_OFFSET + 0)
#define PROBE_PIN_SWDIO (PROBE_PIN_OFFSET + 1)
#endif

#if defined(PROBE_CDC_UART)
#define PICOPROBE_UART_TX 16
#define PICOPROBE_UART_RX 17

#define PICOPROBE_UART_INTERFACE uart0
#define PICOPROBE_UART_BAUDRATE 115200
#endif

/* LED config - some or all of these can be omitted if not used */
//#define PICOPROBE_USB_CONNECTED_LED 2
//#define PICOPROBE_DAP_CONNECTED_LED 15
//#define PICOPROBE_DAP_RUNNING_LED 16
//#define PICOPROBE_UART_RX_LED 7
//#define PICOPROBE_UART_TX_LED 8

#define PROBE_PRODUCT_STRING "Custom board as Pico Probe"

#endif
